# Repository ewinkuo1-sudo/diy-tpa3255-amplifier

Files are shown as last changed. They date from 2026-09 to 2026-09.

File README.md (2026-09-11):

# TPA3255 DIY 立體聲後級

使用 TI TPA3255 自畫電路與 PCB，搭配材料選用、3D 機構與量測，完成一台練習機／備用後級，記錄 AI 協作過程供課堂展示。

## 先看成品怎麼用

**Z10 送出音樂 → 這台後級放大 → 左右喇叭發聲。** 音量由 Z10 調整；後級機內自帶電源，機背只接一條市電電源線，另外可接 Trigger 跟隨前級開機／待機。

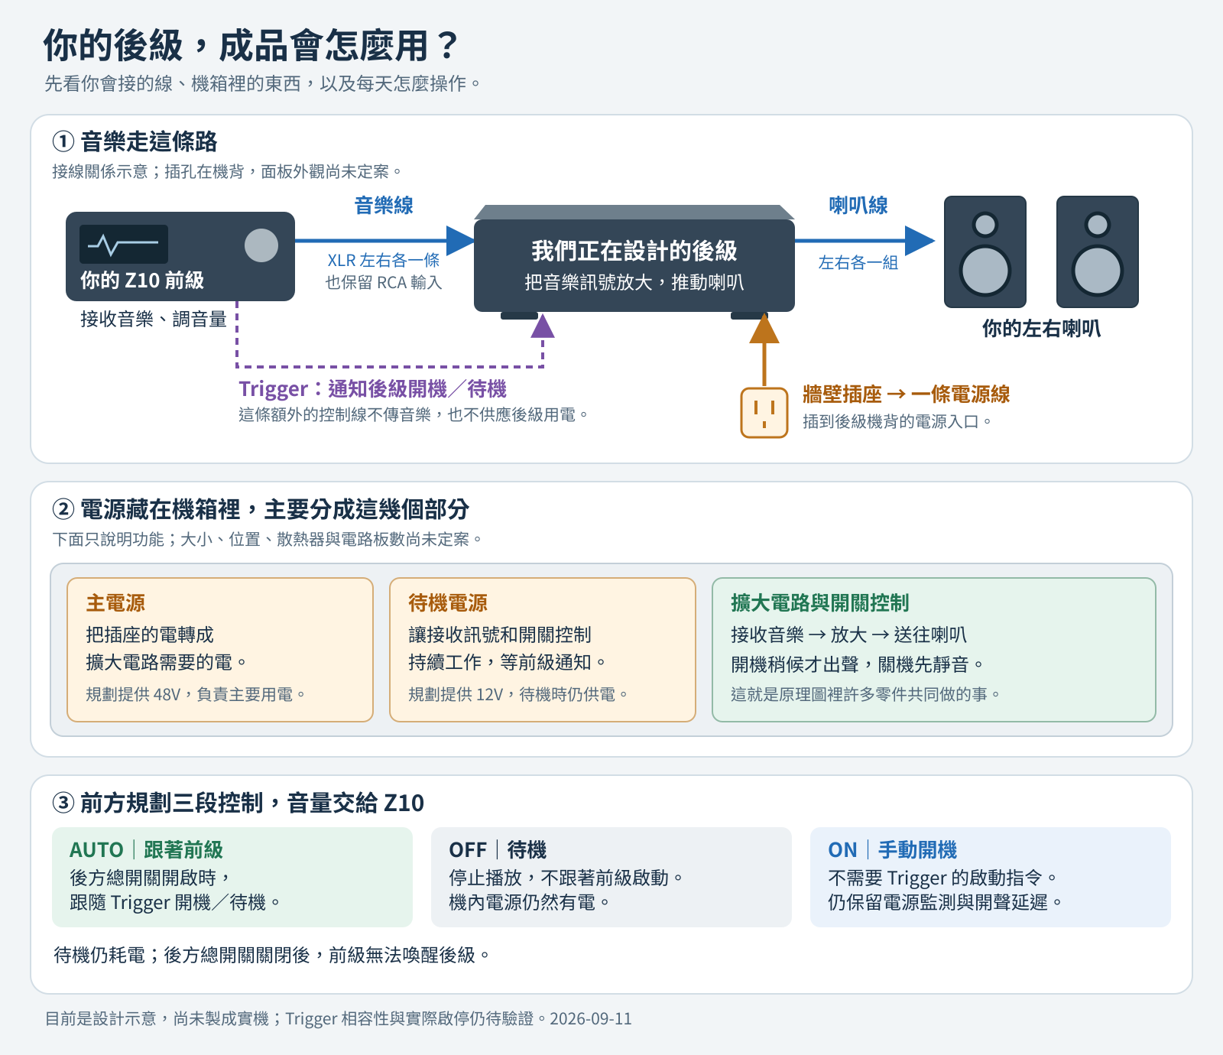
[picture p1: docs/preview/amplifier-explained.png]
後級使用方式圖解


[白話說明與放大圖](docs/使用方式圖解.md)。這是功能與使用方式示意，外觀、內部位置及尺寸尚未定案；目前尚無實機。

## 目前進度

V0.3 已加入 **XLR 平衡輸入並保留 RCA**，搭配濾波後回授（PFFB）、四顆 Coilcraft MA5172-AE，以及隔離 Trigger、自動啟停與 48V 功率電源開關。原八頁的全部元件已按訊號路徑重新排列成 **一張連續接線的完整電路圖**，可由輸入一路看到放大、喇叭、四路回授及啟停控制；元件與電氣連接維持原版。已開始 PCB 零件配置；以 2×50W / 8Ω 為第一階段目標，尚無完成的板子或實測。

XLR 使用 INA2137 差動接收器，依 Z10 的 XLR／RCA 電平匹配音量。第一版由左右聲道跳線選擇輸入，切換前先進入待機。

整機已改為 **機內電源、機背一條市電線**：規劃單一 IEC 入口，機內分別供應 48V 主電源與 12V 待機電源。Trigger 關機只停止功率級供電，兩組 AC/DC 與 12V 支路仍有電。電源模組已有候選，交流保護、12V 入口保護、配線及熱驗證尚待完成；Z10 Trigger 的電壓、極性與帶載能力仍需實測。

## PCB 第一版配置

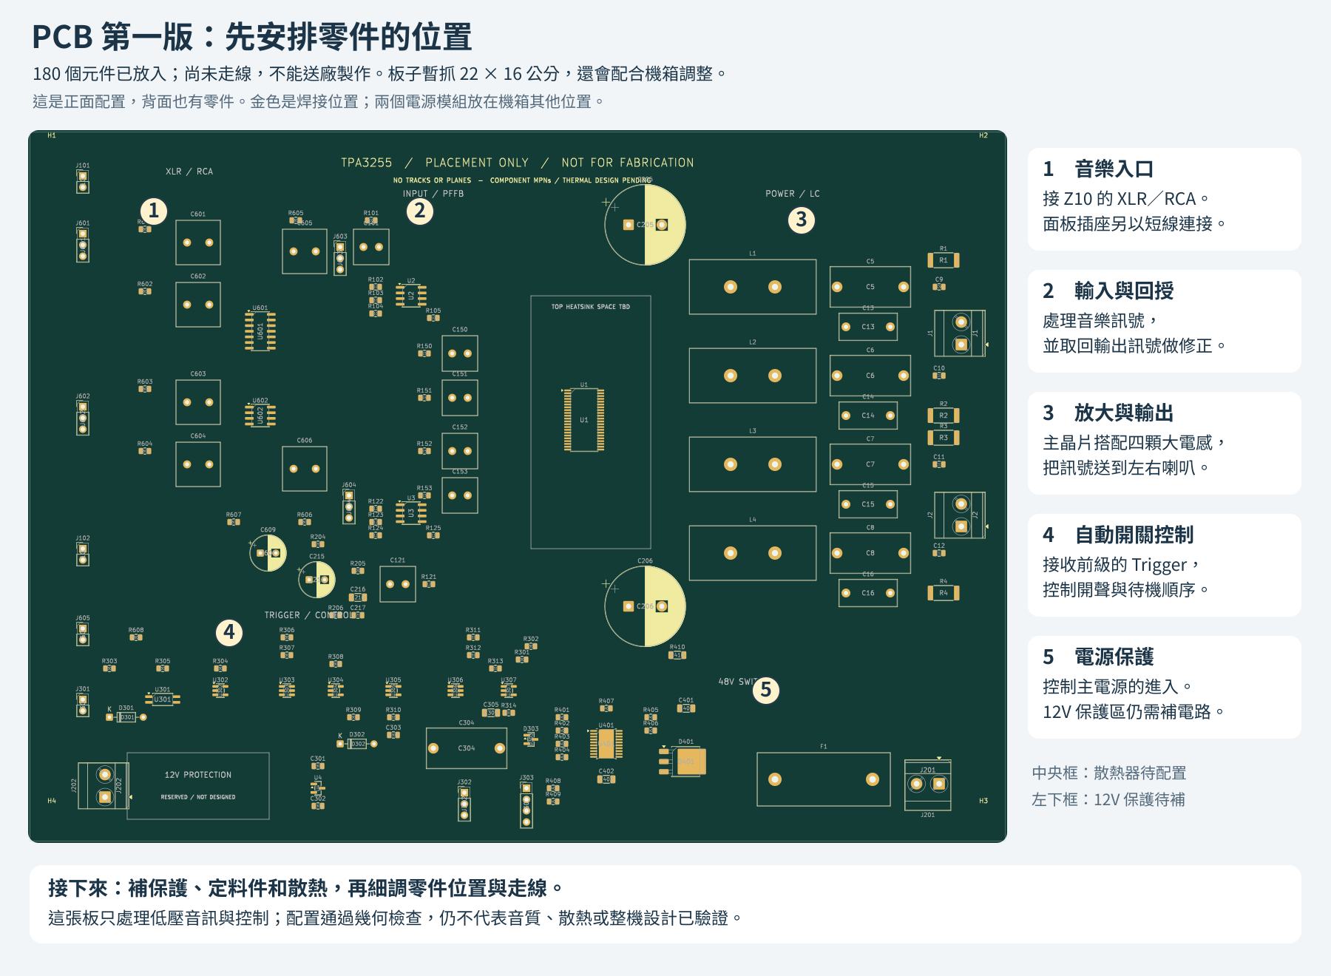
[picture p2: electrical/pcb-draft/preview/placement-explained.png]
PCB 配置中文圖解


**[看 PCB 配置與中文說明](electrical/pcb-draft/README.md)** · [檢查結果](electrical/pcb-draft/validation.md)

已放入 180 個元件與 4 個固定孔，暫抓 22×16 公分，尺寸與料件仍需調整。**尚未走線，不能送廠製作。** 先補電源保護、定料與散熱，再細調位置和走線。

## 電路圖：輸入、放大、回授與控制接成一張大圖

**[開啟／下載單頁 PDF](electrical/v03/preview/tpa3255-v03-overview.pdf)** · [放大 SVG](electrical/v03/preview/tpa3255-v03-overview.svg) · [看圖說明](electrical/v03/README.md) · [合併檢查](electrical/v03/overview-validation.md)

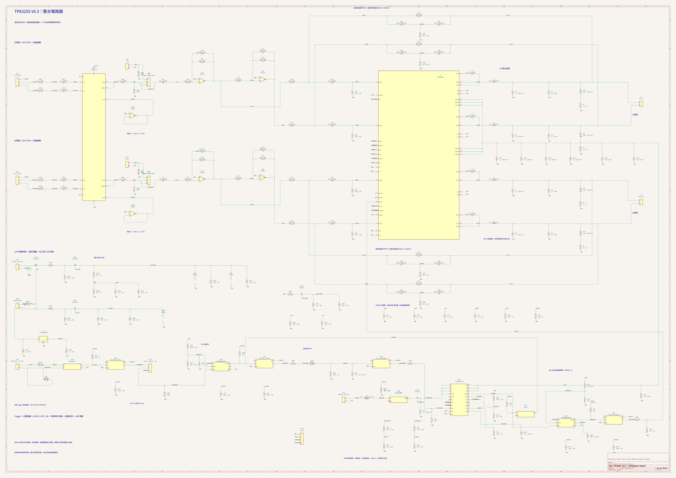
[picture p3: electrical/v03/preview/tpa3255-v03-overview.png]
V0.3 完整單頁電路總圖


總圖採 **A0 橫式單頁**，180 個元件重新編排；音訊由左往右，四路 PFFB 實際接線繞回輸入，下方整合供電與啟停控制。483 個腳位、120 個網路與原版一致，另以移除標籤的接線表確認主要路徑確實連通。PDF／SVG 可放大看數值。建議直接把單頁 PDF 傳給教授，螢幕閱讀時放大；列印以 A0 原尺寸為佳，縮到 A4 文字會太小。供電、偏壓與部分狀態線使用同名標籤相連；導線交叉處有圓點才相接。

[中文設計說明](docs/V0.3_設計說明.md) · [電路／模型驗證報告](electrical/v03/validation.md) · [原八頁 PDF](electrical/v03/preview/tpa3255-v03.pdf)

## 整機電源與機箱

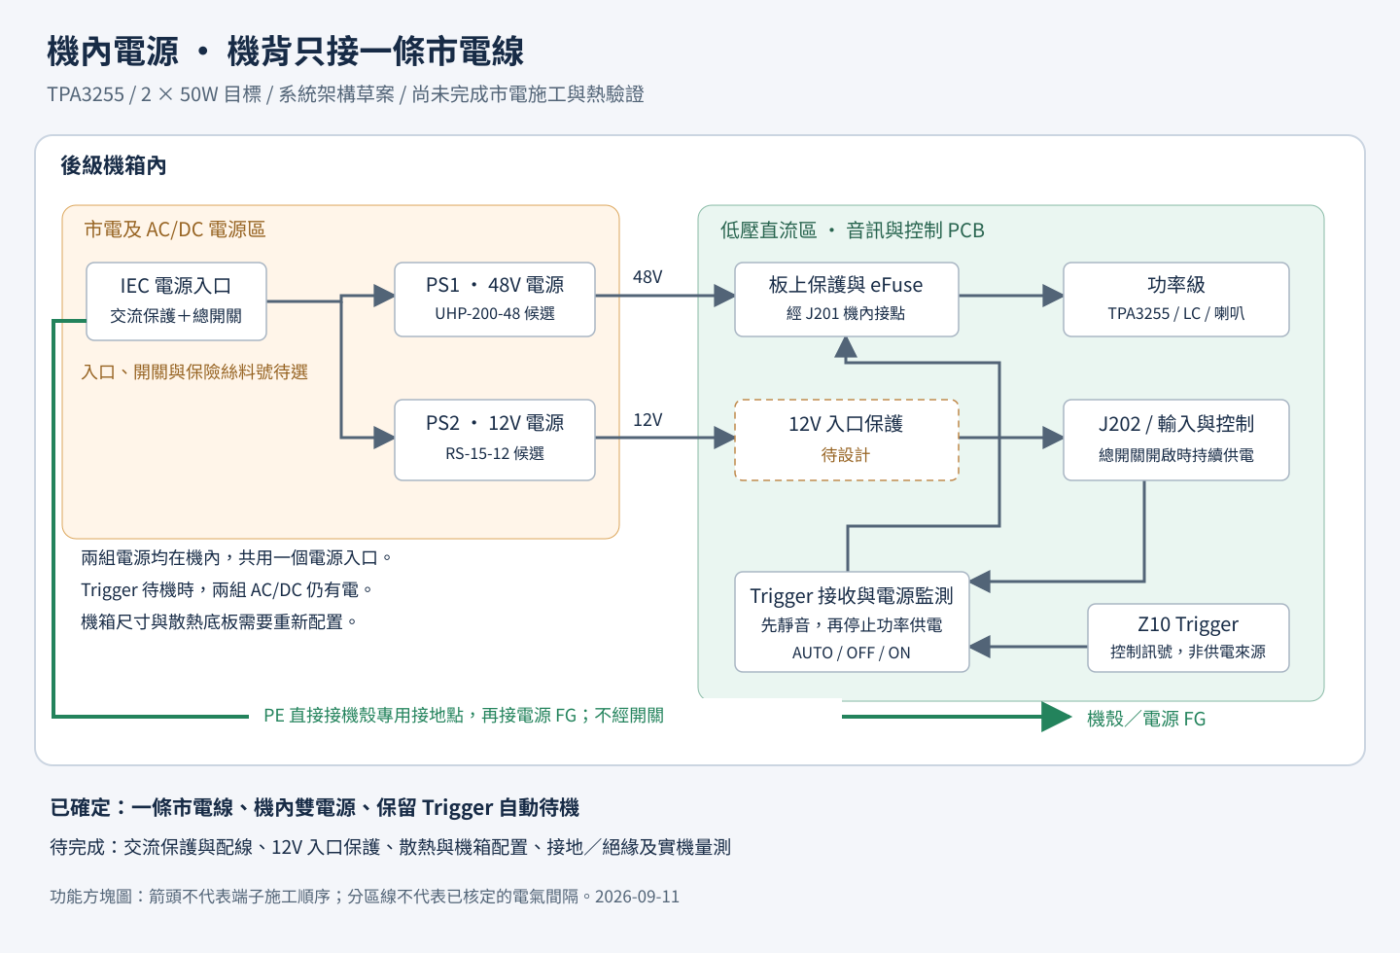
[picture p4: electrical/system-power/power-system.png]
一條市電線的機內電源架構


[電源架構、模組候選與待辦](electrical/system-power/README.md) · [機箱製作方式](mechanical/機箱選擇.md)

採現成鋁機箱＋客製前後面板的方向，需重新容納機內電源、熱路徑與市電配線。機箱尚未定案；[原 V0.1 空間圖](mechanical/README.md) 保留為歷史占位，不代表目前整機尺寸。

## 文件

| 文件 | 用途 |
|---|---|
| [使用方式圖解](docs/使用方式圖解.md) | 先看 Z10、後級、喇叭怎麼連接，以及電源和開關怎麼用 |
| [PCB 配置草案](electrical/pcb-draft/README.md) | 真正 KiCad 板檔、180 元件初步配置、中文預覽與待辦 |
| [機內電源架構](electrical/system-power/README.md) | 單一市電入口、48V／12V 模組候選、保護接地與待機 |
| [V0.3 電路設計](docs/V0.3_設計說明.md) | 電感選型、回授、Z10 匹配與 Trigger 啟停 |
| [PCB 設計要求](docs/V0.3_PCB設計要求.md) | 供電、接地、取樣與元件配置要求 |
| [V0.2 電路設計](docs/V0.2_電路設計.md) | 歷史基線：手動控制、未加 PFFB |
| [音質改善評估](docs/V0.2_音質改善評估.md) | 回授、電感、供電與輸入級的改善優先順序 |
| [BOM 草案](electrical/v03/bom-draft.csv) | V0.3 電路元件；封裝候選另列於 PCB 草案，尚未回填定案 |
| [V0.1 設計規格](docs/V0.1_設計規格.md) | 系統、選材條件與測試流程 |
| [電路設計筆記](docs/01_電路設計.md) | 已修正的腳位、供電與設計注意事項 |
| [功率估算](docs/V0.1_功率估算.md) | 可重算的需求情境 |
| [原始規劃](docs/00_專案總覽.md) | 歷史成本與構想，待重核 |
| [接班進度](HANDOFF.md) | 下一步與驗證程度 |
| [拆分紀錄](MIGRATION.md) | 舊版本與歷史來源 |

## 下一步

補齊 12V 入口保護與交流入口／總開關選型，依機內電源的散熱需求重排機箱。同時完成回授穩定性、真實運放與電源開關的進一步驗證，核對 Trigger 介面、剩餘料件及封裝，再確定 PCB 板形、佈局和散熱器。

重新產生計算報告：

```sh
python3 tools/power_budget.py > docs/V0.1_功率估算.md
```

預覽更新方式見 [看圖說明](mechanical/README.md)。
Purifi 主力機位於 [獨立專案](https://github.com/ewinkuo1-sudo/diy-purifi-amplifier)，本專案的檔案與測試不依賴它。

## License

MIT（沿用來源專案的授權聲明）；衍生自 KiCad 的獨立封裝另依[封裝庫授權](electrical/pcb-draft/Placement.pretty/README.md)。

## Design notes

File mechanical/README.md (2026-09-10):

# 看圖入口

目前按使用者要求採 **機內電源、機背一條市電線**，見[整機電源架構圖](../electrical/system-power/README.md)。機箱建議採現成鋁殼＋客製前後板，已整理[製作方式與尺寸參考](機箱選擇.md)。型號與尺寸需重新配置；以下 V0.1 圖僅為外接電源時期的歷史占位，未包含現在的機內 AC/DC、XLR、實際電感及固定方式。

## 機殼草案

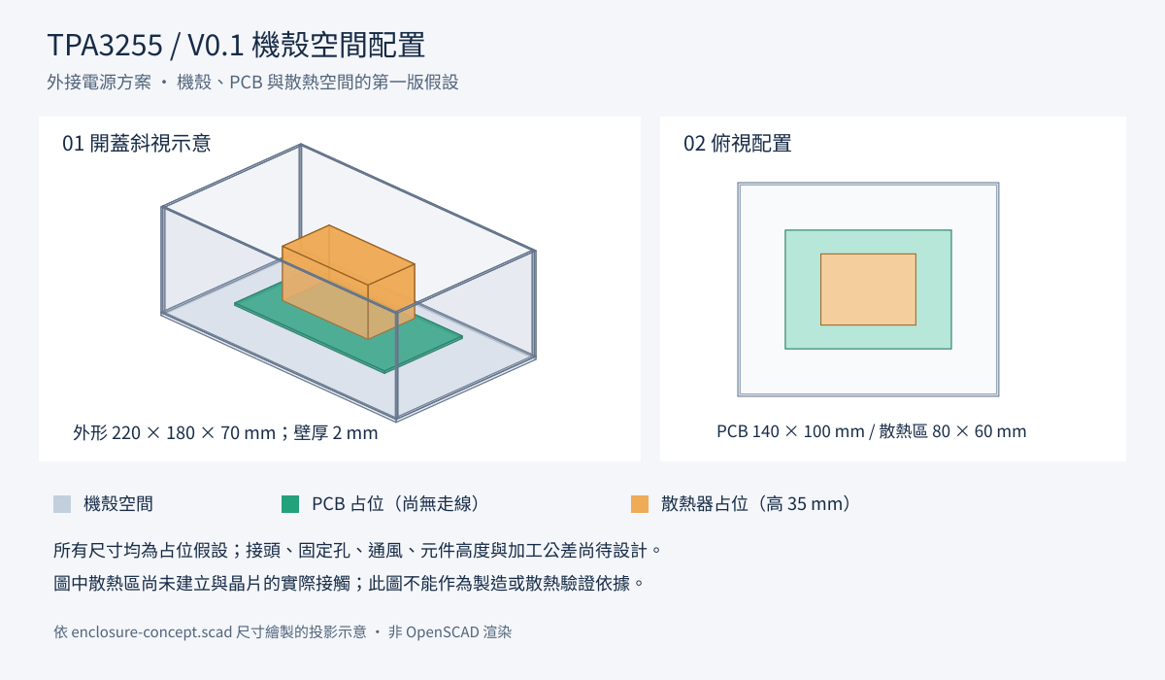
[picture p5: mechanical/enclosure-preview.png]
TPA3255 V0.1 機殼空間配置


左側是開蓋斜視，右側是俯視。綠色是 PCB 占位，橘色是散熱器占位，灰色是機殼。這是空間配置草案；板上尚無元件與走線，尺寸仍可改。

- [放大看 PNG](enclosure-preview.png)
- [向量圖 SVG](enclosure-preview.svg)
- [可修改尺寸的 OpenSCAD 原始檔](enclosure-concept.scad)
- [系統方塊圖與設計規格](../docs/V0.1_設計規格.md#系統方塊圖)

GitHub 的文件與 PNG 可直接閱讀。若要旋轉並修改機殼模型，下載 `.scad`，用 [OpenSCAD](https://openscad.org/) 開啟並按 F5 預覽。本機目前尚未安裝 OpenSCAD；上述圖片是讀取模型尺寸繪製的投影示意，不是 CAD 軟體渲染。

## 更新預覽

在專案根目錄執行：

```sh
python3 tools/enclosure_preview.py
rsvg-convert -o mechanical/enclosure-preview.png mechanical/enclosure-preview.svg
```

Python 腳本不需要額外套件；PNG 轉換使用 librsvg 的 `rsvg-convert`。腳本讀取 SCAD 中的數值尺寸，投影邏輯對應目前的矩形空間配置。若更改 SCAD 的幾何形狀，需同步更新腳本。預覽固定隱藏上蓋，尚未輸出可旋轉的 STL。

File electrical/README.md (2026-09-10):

# TPA3255 原理圖：直接看圖

最新設計已移至 **[V0.3 八頁原理圖：XLR／RCA 與 Trigger](v03/README.md)**。以下保留 V0.2 歷史基線。

這裡是 V0.2 可編輯的 KiCad 電路草案，已通過 ERC 與接線群組核對，尚無 PCB 或實測。四頁屬於同一電路，全域網路名稱相同即相連。

**[下載四頁 PDF](preview/tpa3255-v02.pdf)** · [中文設計說明](../docs/V0.2_電路設計.md) · [驗證結果](validation.md) · [BOM 草案](bom-draft.csv)

## 1. 功率級與輸出濾波

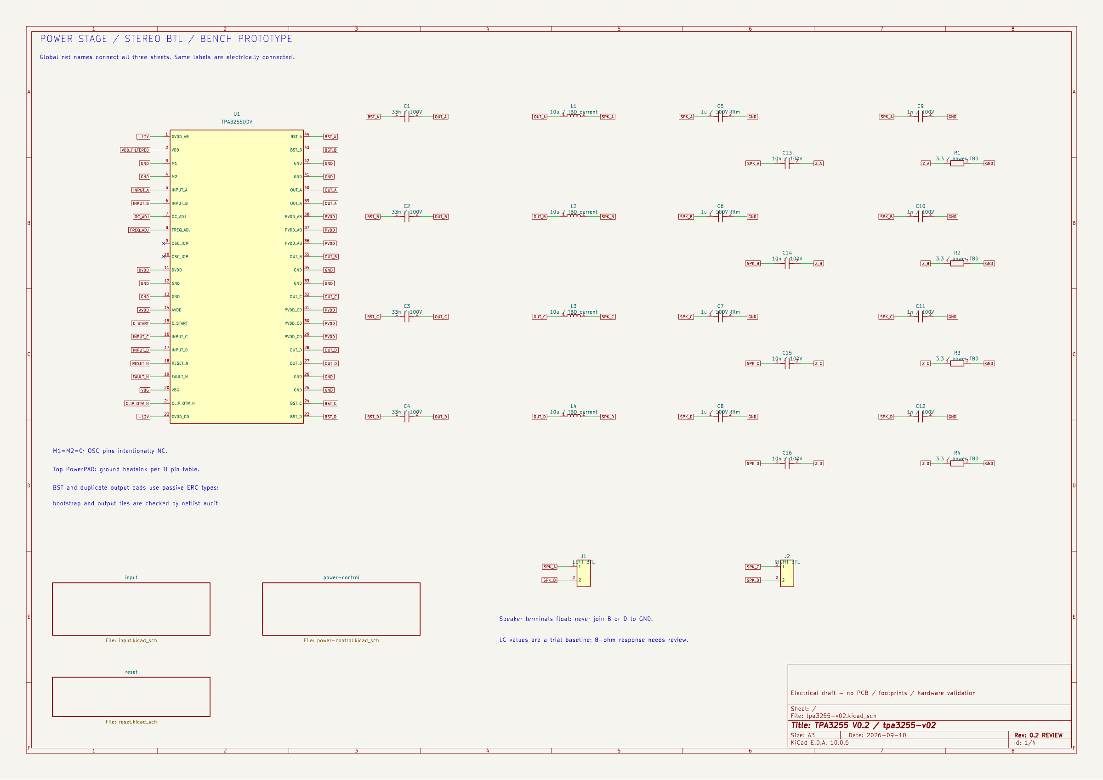
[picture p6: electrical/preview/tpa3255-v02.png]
TPA3255 功率級


[放大 SVG](preview/tpa3255-v02.svg)

## 2. RCA 輸入級

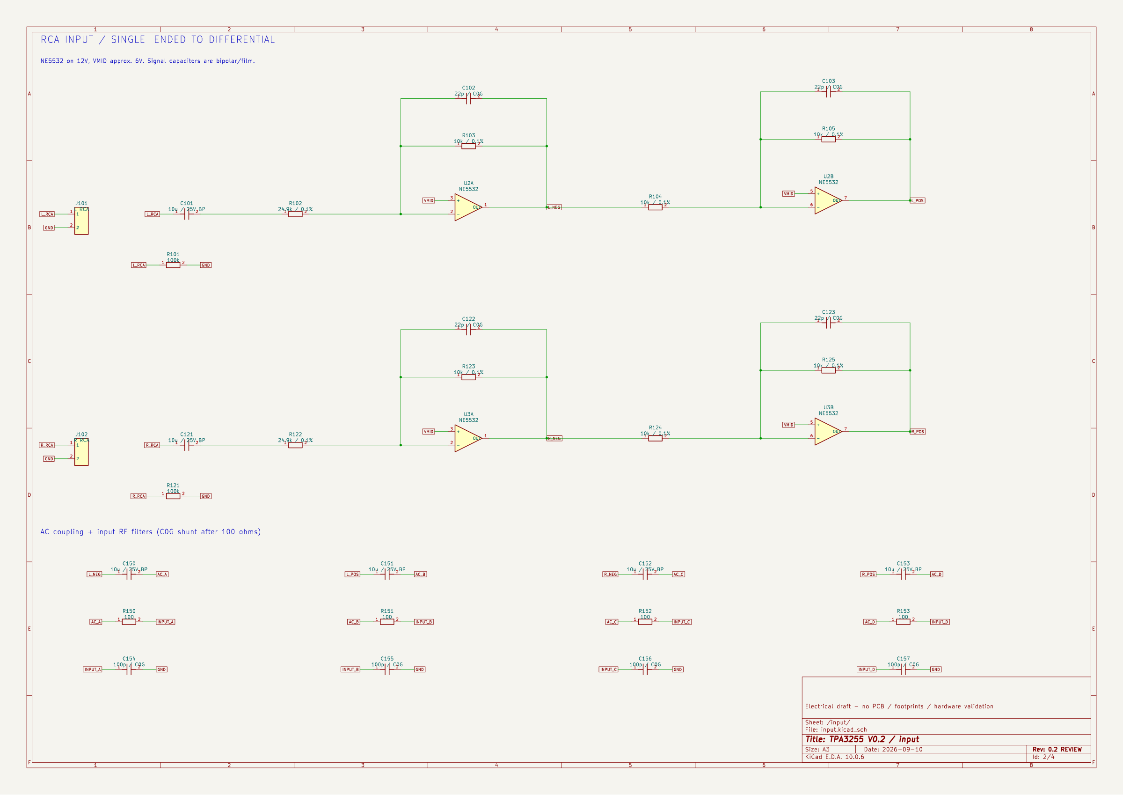
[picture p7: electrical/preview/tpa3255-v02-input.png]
RCA 輸入與差動轉換


[放大 SVG](preview/tpa3255-v02-input.svg)

## 3. 供電與去耦

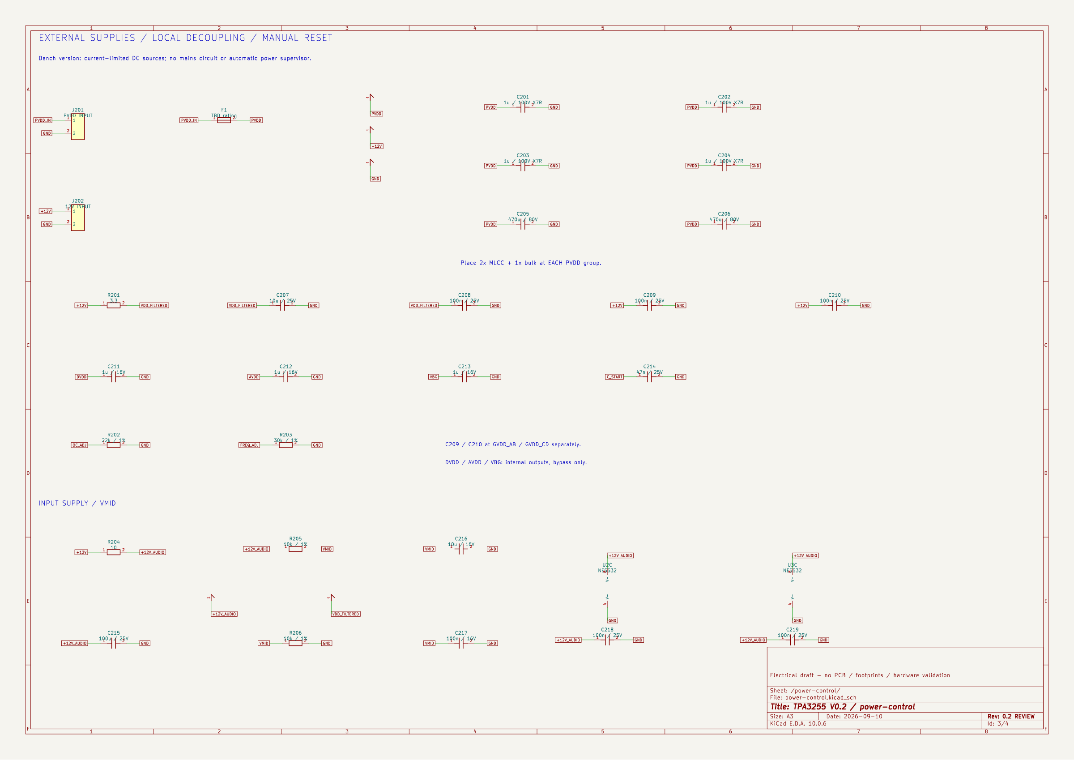
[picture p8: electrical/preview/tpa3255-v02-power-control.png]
主電源、12V 與局部去耦


[放大 SVG](preview/tpa3255-v02-power-control.svg)

## 4. 手動啟停控制

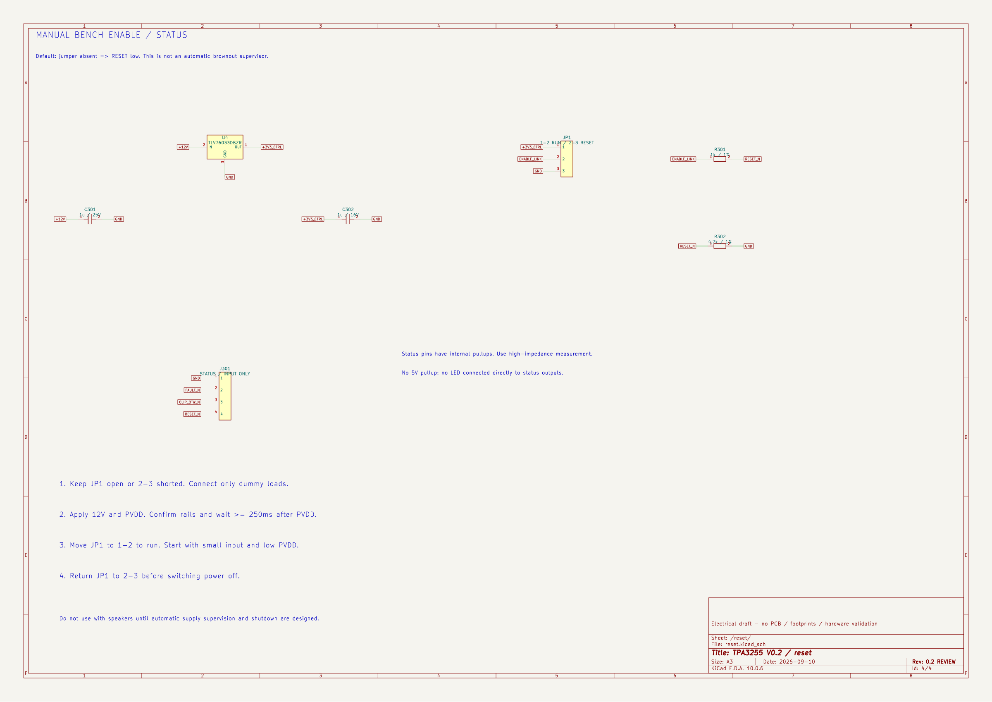
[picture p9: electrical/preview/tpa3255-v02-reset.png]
手動 RESET 與故障量測


[放大 SVG](preview/tpa3255-v02-reset.svg)

## 編輯與重現

用 KiCad 10 開啟 [tpa3255-v02.kicad_pro](tpa3255-v02.kicad_pro)，再開啟同名原理圖。`Project.kicad_sym` 與 `sym-lib-table` 已隨專案附上，不依賴另行下載的自訂符號。

檢查與輸出（在專案根目錄）：

```sh
python3 tools/verify_electrical.py
python3 tools/export_schematic.py
```

`verify_electrical.py` 讀取目前的原理圖，用 KiCad 匯出接線表，核對 `expected-connections.csv` 並產生 ngspice 輸入／LC 區塊模型、CSV 數據與報告。更改電路時需審查並更新預期接線表；不要為了通過檢查而直接接受未知連接。

`tools/build_schematic.py` 是本次初始圖面的產生器，重跑會覆寫四頁原理圖、自訂符號、預期接線表與專案檔。若已在 KiCad 手動編輯，平時使用上面的驗證／匯出指令即可。

`export_schematic.py` 使用 `kicad-cli` 匯出四頁 PDF／SVG，整理 SVG 行尾空白，再用 `rsvg-convert` 產生寬 2400 像素的 PNG。需安裝 KiCad 與提供 `rsvg-convert` 的 librsvg；圖面更新時執行一次即可同步首頁預覽。

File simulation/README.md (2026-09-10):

# V0.2 區塊模擬

由 `python3 tools/verify_electrical.py` 從 KiCad 匯出接線表產生，使用 ngspice 47。

| 檔案 | 範圍 | CSV first / second |
|---|---|---|
| `input-ac.cir` / `input-ac.csv` | 左右輸入級 AC，理想有限增益運放 | 左聲道 / 右聲道的晶片輸入差動電壓 |
| `filter-ac.cir` / `filter-ac.csv` | 左聲道 BTL 輸出濾波，4Ω 和 8Ω 比較 | 4Ω / 8Ω 的差動電壓 |

CSV 頻率單位 Hz，電壓是相對 1V AC 激勵的複數結果。數值不是 THD、噪音、熱或實機性能。模型與假設見 [設計說明](../docs/V0.2_電路設計.md)，摘要見 [驗證報告](../electrical/validation.md)。

在本目錄可用 `ngspice -b input-ac.cir` 或 `ngspice -b filter-ac.cir` 重跑，生成 `.dat`。正式 CSV 與驗證報告由根目錄的驗證腳本統一更新。

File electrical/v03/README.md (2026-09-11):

# V0.3 電路圖：完整單頁整合電路

原八頁的所有元件已重新編排成 **一張 A0 橫式、連續接線的完整電路圖**，包含 XLR 平衡接收／RCA 選擇、PFFB、四顆 MA5172-AE，以及隔離 Trigger 控制與 48V 功率電源開關。180 個元件、483 個腳位、120 個網路與原版完全一致；音訊、四路回授與主要啟停控制以實際導線連接；電路功能未改。電路已有接線檢查及簡化模型驗證，亦有[未走線 PCB 配置草案](../pcb-draft/README.md)，尚無實機性能驗證。

整機採[機內電源、單一市電入口](../system-power/README.md)。總圖完整涵蓋原八頁的低壓音訊與控制；J201／J202 為機內供電接點，市電區另行規劃，沒有包含在本版 ERC／模型驗證內。

**[開啟／下載單頁 PDF](preview/tpa3255-v03-overview.pdf)** · [放大 SVG](preview/tpa3255-v03-overview.svg) · [高解析 PNG](preview/tpa3255-v03-overview.png) · [單頁 KiCad 圖檔](tpa3255-v03-overview.kicad_sch) · [合併檢查](overview-validation.md)

完整單頁電路總圖

建議將單頁 PDF 傳給教授，放大看元件數值；列印以 A0 原尺寸為佳，縮到 A4 文字會太小。PDF／SVG 是可放大的向量圖；PNG 供快速預覽。供電、偏壓與部分狀態線仍以同名標籤表示相連；導線交叉有圓點才相接。

總圖閱讀順序：

1. 左側 XLR／RCA 輸入與選擇 → NE5532 差動驅動 → 中央 TPA3255 → 右側 LC 與喇叭。
2. 喇叭端的四路 PFFB 從功率級上下方繞回 SUM 加總點；回授阻容直接畫在回線上。
3. 左下方為 12V 待機、類比供電與 VMID；功率級 PVDD 去耦接在右側供電幹線。
4. 下方 Trigger 經隔離、模式選擇、電源監測與關機保持，控制 48V eFuse；延遲開聲線直接接回 TPA3255 的 RESET。

原八頁的方格分區已移除。U1／U601 的圖形腳位改按訊號流排列，實體腳號、名稱與電氣型態均保留；一個 IC 仍是一個 IC。

[中文設計說明](../../docs/V0.3_設計說明.md) · [電路／模型驗證](validation.md) · [BOM 草案](bom-draft.csv)

<details>
<summary>展開原八頁分區圖（維護與逐區查閱）</summary>

[下載原八頁 PDF](preview/tpa3255-v03.pdf)。以下為原版頁次；整合總圖已依訊號路徑重新安排。

## 1. 功率級與輸出電感

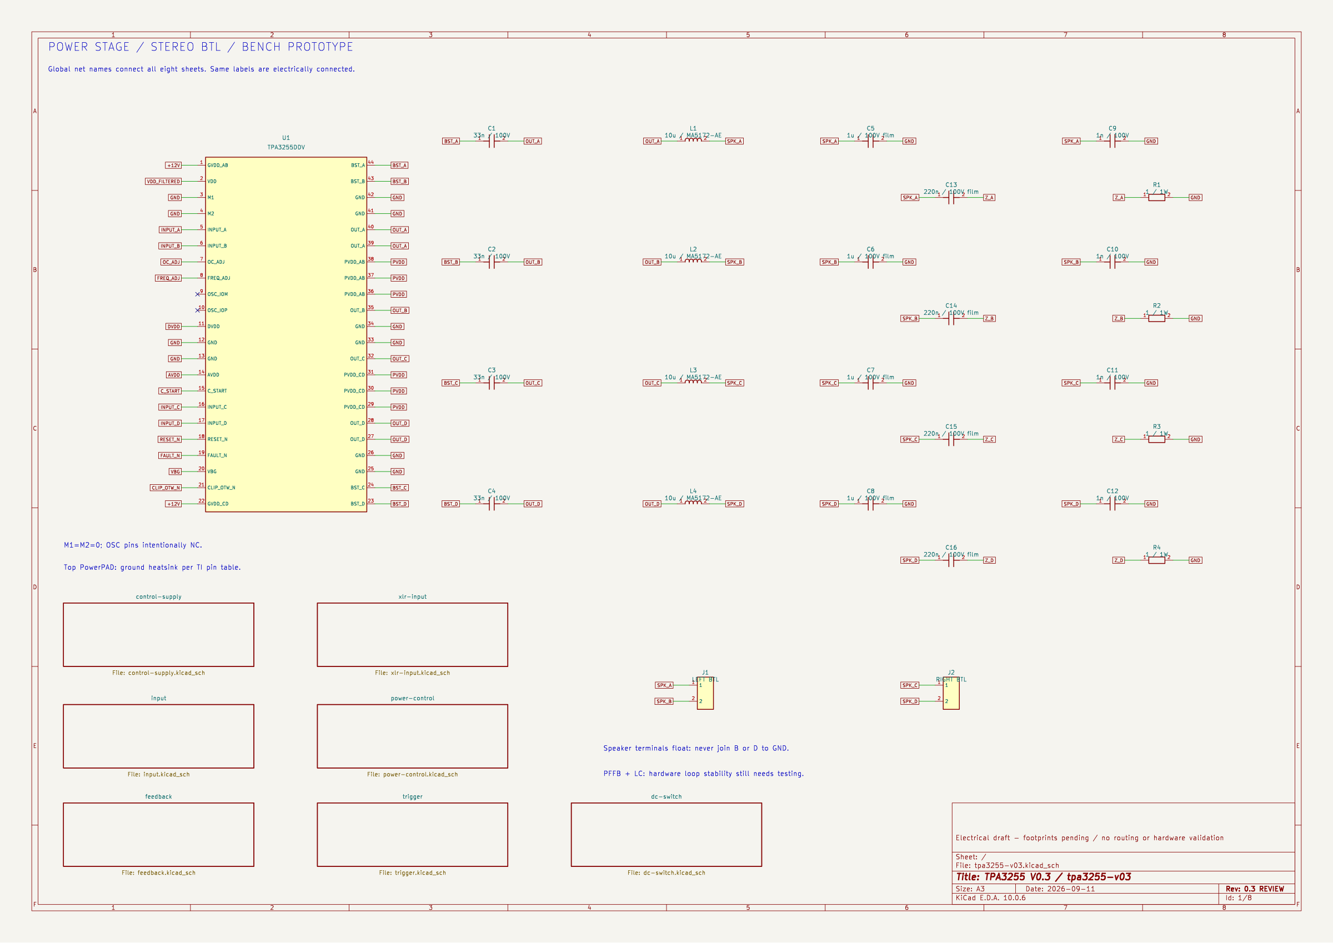
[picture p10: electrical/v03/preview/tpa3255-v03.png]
功率級


[放大 SVG](preview/tpa3255-v03.svg)

## 2. RCA 插座與選定訊號的差動驅動級

RCA 或 XLR 訊號由第八頁 J603／J604 選擇後，送入本頁的 C101／C121。

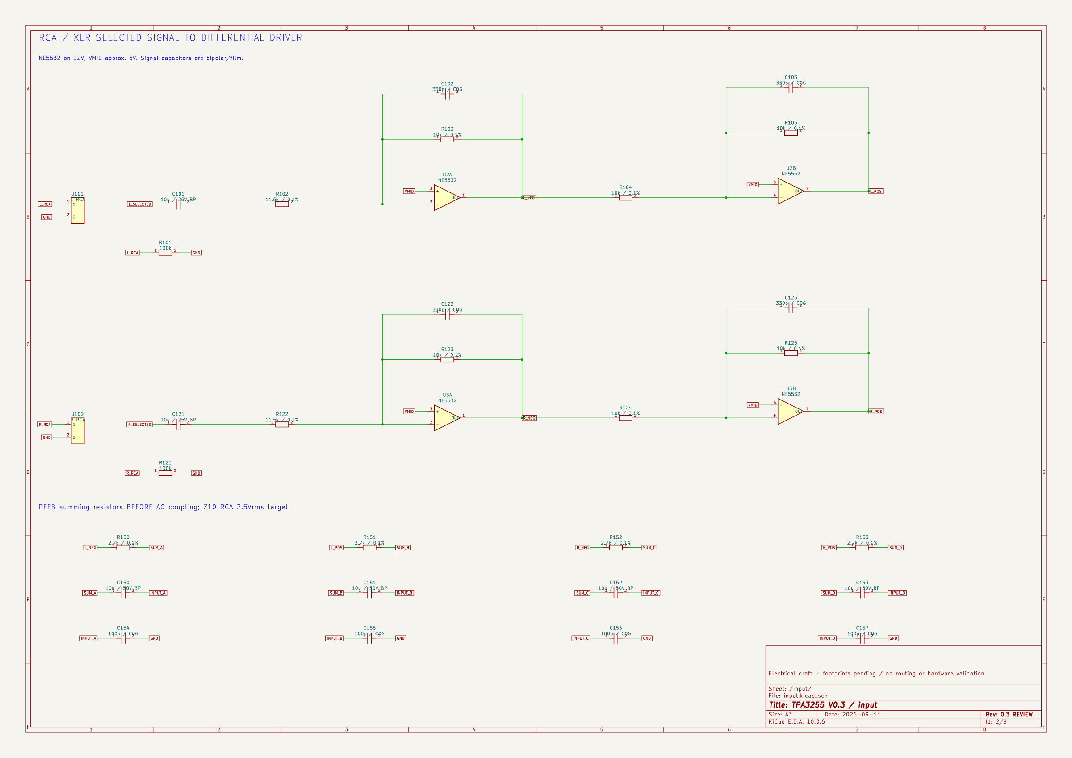
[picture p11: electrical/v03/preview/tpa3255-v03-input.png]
輸入級


[放大 SVG](preview/tpa3255-v03-input.svg)

## 3. 供電去耦

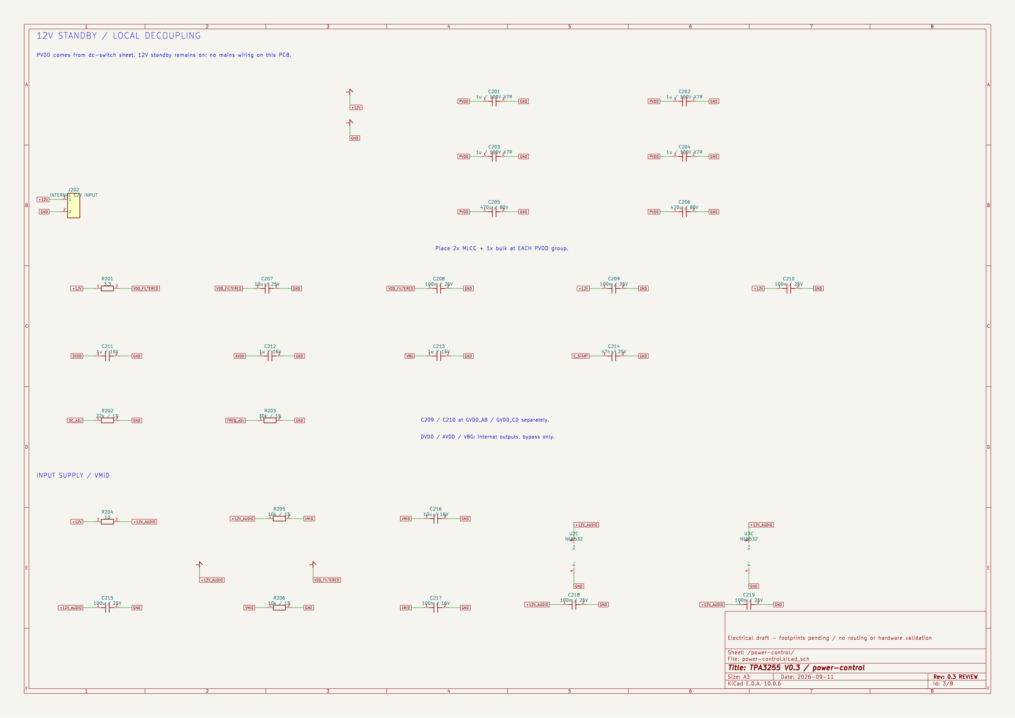
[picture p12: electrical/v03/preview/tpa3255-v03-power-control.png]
供電去耦


[放大 SVG](preview/tpa3255-v03-power-control.svg)

## 4. 濾波後回授 PFFB

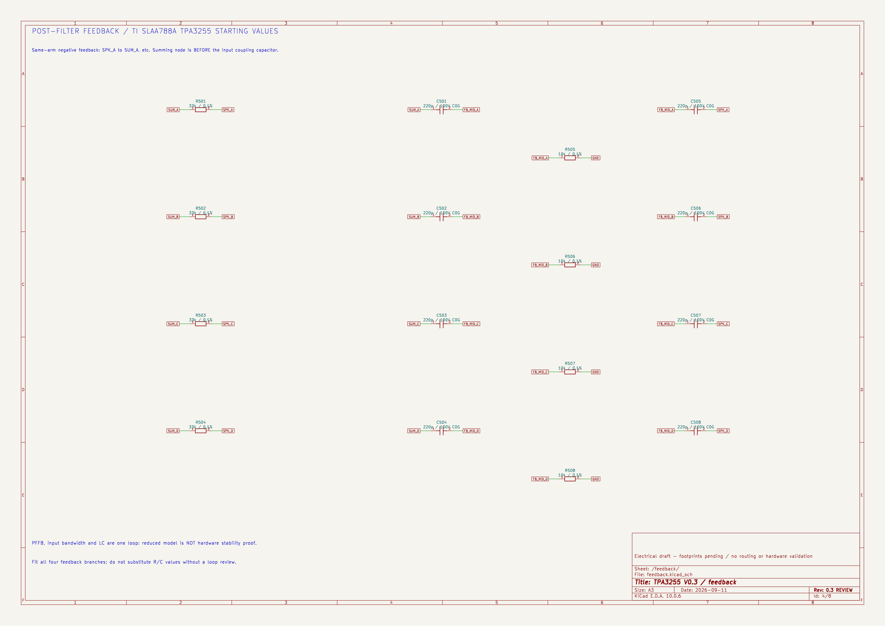
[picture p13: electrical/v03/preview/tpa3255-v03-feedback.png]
PFFB


[放大 SVG](preview/tpa3255-v03-feedback.svg)

## 5. Trigger 接收與關機延遲

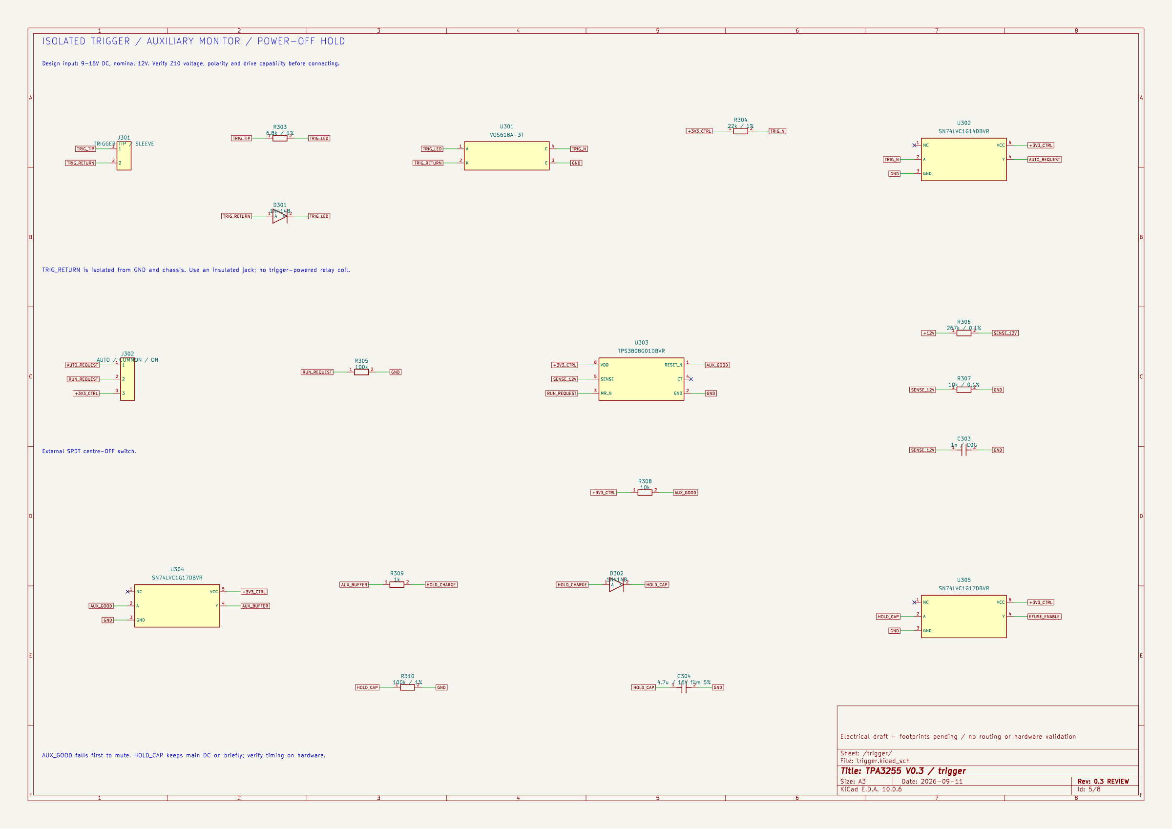
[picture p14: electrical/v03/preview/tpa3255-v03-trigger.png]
Trigger


[放大 SVG](preview/tpa3255-v03-trigger.svg)

## 6. 48V 功率電源開關與延遲開聲

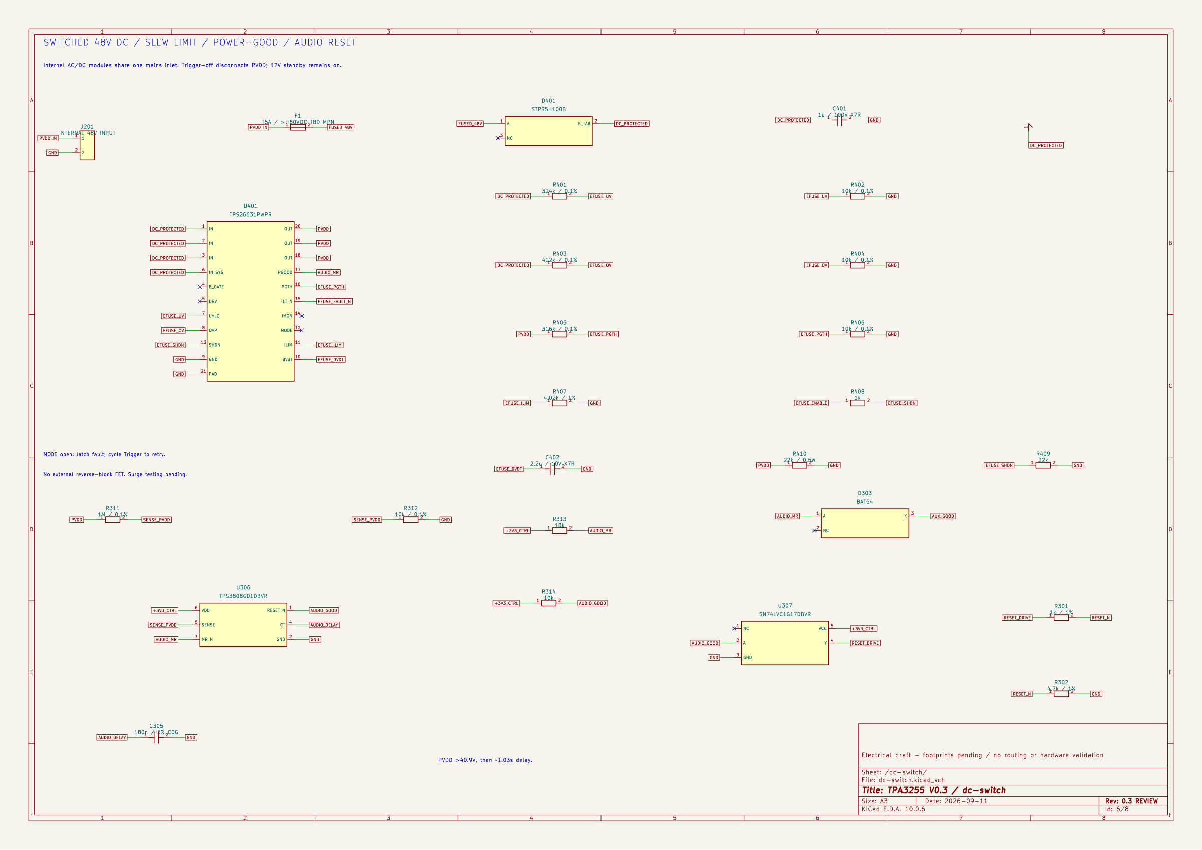
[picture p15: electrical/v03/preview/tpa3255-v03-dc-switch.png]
功率電源開關


[放大 SVG](preview/tpa3255-v03-dc-switch.svg)

## 7. 待機控制供電

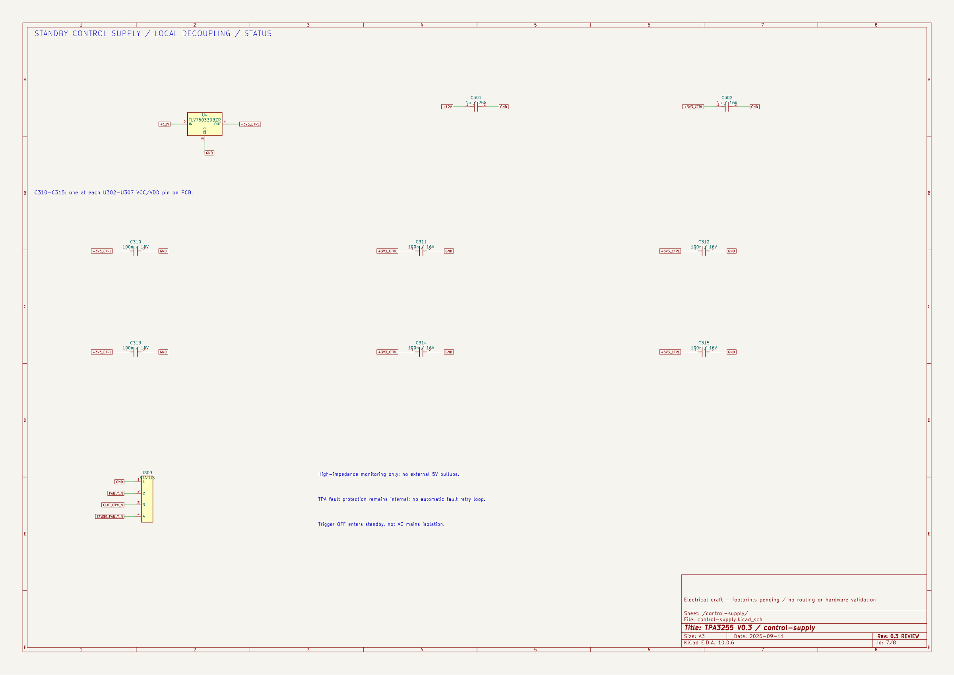
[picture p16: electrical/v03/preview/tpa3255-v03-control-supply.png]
待機控制供電


[放大 SVG](preview/tpa3255-v03-control-supply.svg)

## 8. XLR 平衡接收與輸入選擇

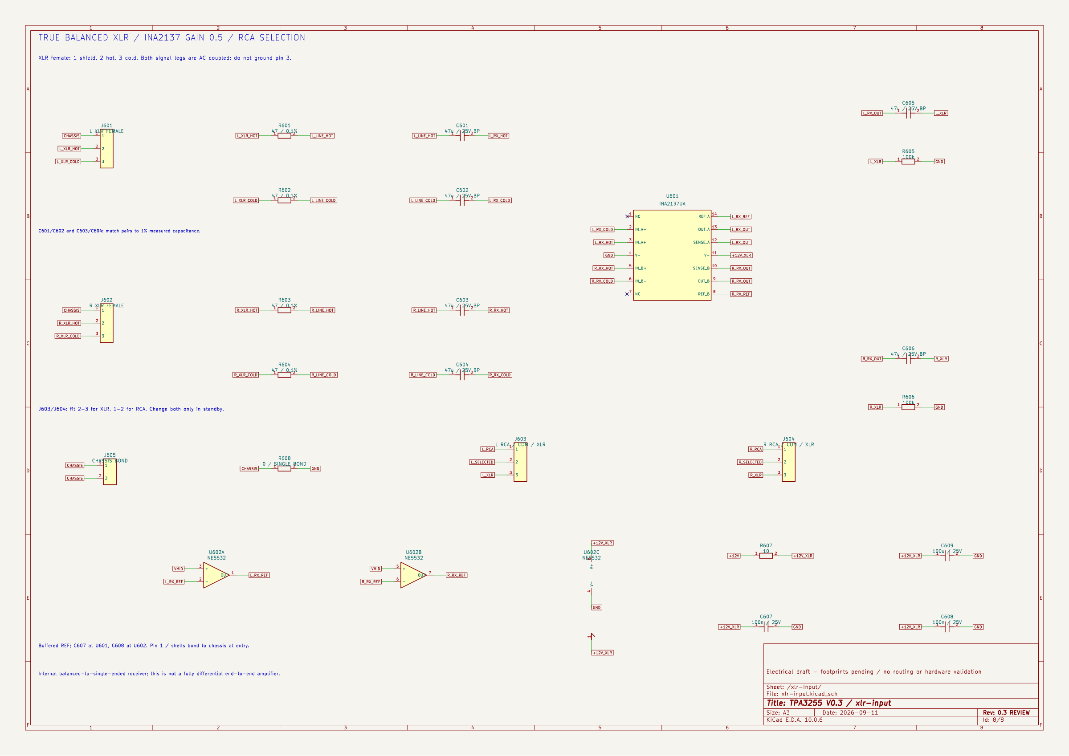
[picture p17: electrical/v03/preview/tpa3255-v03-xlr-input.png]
XLR 平衡輸入


[放大 SVG](preview/tpa3255-v03-xlr-input.svg)

左右聲道各一個 XLR 母座。J603／J604 均接 2–3 選 XLR，均接 1–2 選 RCA；切換前先將 J302 設為 OFF 待機。這版是板上跳線設定，機殼面板切換方式尚待機構與靜音設計。

</details>

## 原始檔、編輯與驗證

單頁總圖可用 KiCad 10 開啟 [tpa3255-v03-overview.kicad_pro](tpa3255-v03-overview.kicad_pro)，它是包含全部元件的原生單頁圖檔。由現行八頁來源讀取全部元件，再重新配置位置與實際導線；保留元件、數值、單元及符號 UUID。`Overview.kicad_sym` 保存 U1／U601 的功能排列圖形，其餘符號沿用 Project 庫。

維護時仍以八頁來源為準，再重建總圖。既有 PCB 對應原階層路徑，請繼續從原專案更新 PCB；總圖若另行編輯，不會自動回寫來源，重建也會覆寫總圖。`overview-sources.json` 記錄 SHA-256，驗證可偵測來源變動而總圖尚未更新。

只更新總圖時執行（不需重跑電路模型）：

```sh
python3 tools/build_schematic_overview.py
python3 tools/verify_schematic_overview.py
python3 tools/export_schematic.py electrical/v03/tpa3255-v03-overview.kicad_sch --pdf-from-svg --png-width 4800
```

驗證會比對元件、每個符號的電氣腳位、全部接線與 ERC，再暫時移除標籤，檢查音訊、回授及主要控制路徑仍靠導線完整連接。PDF 由 KiCad SVG 轉為靜態向量圖，保留 A0 尺寸、中文與細節。

KiCad 10 開啟 [tpa3255-v03.kicad_pro](tpa3255-v03.kicad_pro)，再開同名原理圖；自訂符號庫已隨附。電感料號已選，其餘 BOM 仍有待定項，全部 footprint 尚未定案。

在儲存庫根目錄執行：

```sh
python3 tools/verify_v03.py
python3 tools/export_schematic.py electrical/v03/tpa3255-v03.kicad_sch
```

`verify_v03.py` 檢查實際 KiCad 接線表，更新 BOM、AC 數據與控制時序規格模型。後者不是實際控制 IC 的 SPICE 模型，也沒有驗證真正的回授穩定裕度。

`tools/build_schematic_v03.py` 只供重建這版初始圖面，會覆寫本資料夾的原理圖、符號庫、預期接線表與專案檔。手動編輯後使用上述驗證與匯出指令，避免直接重建。V0.2 仍保留在[上層歷史圖面](../README.md)。

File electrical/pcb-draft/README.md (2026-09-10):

# PCB 第一版：零件配置草案

已開始畫真正的 KiCad 電路板檔案。本階段先安排零件位置和空間，**尚未走線，不能送廠製作**。板子暫抓 220×160 mm，機箱與散熱器仍需配合調整。

PCB 配置中文圖解

[放大中文圖解](preview/placement-explained.svg) · [正面原始預覽](preview/top.png) · [背面原始預覽](preview/bottom.png) · [檢查結果](validation.md)

## 目前這張板包含什麼

- 180 個電路元件與 4 個暫定 M3 固定孔，保留原理圖接線資料。
- 左側接前級；中間放輸入處理、回授與功率晶片；右側安排四顆電感與喇叭輸出；下方安排 Trigger 與主電源開關。
- 主晶片頂部的散熱器、12V 入口保護各有空間標記。標記是配置預留，不代表完成 3D 干涉檢查或電氣隔離設計。
- 暫用 4 層、1.6 mm 板厚做空間研究；尚未核定製程、銅厚、介質、線寬、過孔或地平面，沒有畫任何銅箔走線／覆銅。
- 只包括音訊與低壓控制。兩個 AC/DC 電源、交流入口與市電線束放在機箱其他位置，不在這張板上。

分區和現有間距只是起點。高電流回路、去耦過孔、回授取樣、背面元件可裝配性及散熱器固定仍要細調；目前不能以「放得下」判定可用於實際功率輸出。

## 封裝核對與尚未定料的項目

[placement.csv](placement.csv) 每個元件一列，記錄初始封裝、正／背面、位置和來源封裝檔 SHA-256；它是生成結果，手動修改板檔後需同步更新。`package_candidate` 表示已依下列原廠資料核對封裝類型及腳序，但未完成製造放行；`provisional` 表示暫用的尺寸／封裝占位，未選定相應實際料號。

| 部分 | 本次處理與依據 |
|---|---|
| TPA3255 | 使用 DDV 44 腳頂面散熱封裝；PCB 沒有額外的第 45 腳底部散熱焊盤。依 [TI 原廠資料，封裝及 §12](https://www.ti.com/lit/ds/symlink/tpa3255.pdf)。散熱器尺寸與接觸壓力未定。 |
| 主電源開關 | TPS26631 使用 PWP0020T 對應的 HTSSOP-20 與 2.96×2.96 mm 阻焊開口版本，底部第 21 腳接 GND；散熱銅面／過孔仍未設計。[TI TPS2663](https://www.ti.com/lit/ds/symlink/tps2663.pdf) |
| XLR 接收與運放 | INA2137UA 用 SOIC-14；NE5532 暫選 SOIC-8（D 封裝方向，完整訂購料號待定）。[INA2137](https://www.ti.com/lit/ds/symlink/ina137.pdf)、[NE5532](https://www.ti.com/lit/ds/symlink/ne5532.pdf) |
| 監測／邏輯／穩壓 | TPS3808 DBV 用 6 腳 SOT-23；LVC1G14／17 DBV 用 5 腳 SOT-23；TLV760 DBZ 為 3 腳且 1=OUT、2=IN、3=GND。[TPS3808](https://www.ti.com/lit/ds/symlink/tps3808.pdf)、[LVC1G14](https://www.ti.com/lit/ds/symlink/sn74lvc1g14.pdf)、[LVC1G17](https://www.ti.com/lit/ds/symlink/sn74lvc1g17.pdf)、[TLV760](https://www.ti.com/lit/ds/symlink/tlv760.pdf) |
| Trigger 光耦 | VOS618A 用 SSOP-4，依 [Vishay 外形與腳序](https://www.vishay.com/docs/83465/vos618a.pdf)。隔離兩側仍須在走線時保持分開。 |
| 二極體 | D303 的 BAT54 由邏輯兩腳符號改成實體 1=A、2=NC、3=K，陰極接 AUX_GOOD，功能方向不變。[Nexperia BAT54](https://assets.nexperia.com/documents/data-sheet/BAT54.pdf)。D401 採 DPAK，1=A、2=K／散熱片、3=NC，[ST 資料](https://www.st.com/resource/en/datasheet/stps5h100.pdf)。D301／D302 的軸向封裝另依本專案 A=1、K=2 重新編號，陰極帶位置不變。 |
| 電感 | 自訂 MA5172-AE 占位採原廠 28.6×12.3 mm 包絡與名義 10 mm 腳距。**1.4 mm 成品孔、3 mm 焊盤是本次暫定值**，不是原廠建議；腳距 ±0.5 mm、線徑最大 1.07 mm 仍須配合孔公差、裝配及電流核定。[Coilcraft 外形圖](https://www.coilcraft.com/getmedia/5fb1a3ea-b3b6-4ae7-89c3-2a4c68c350e4/ma5172.pdf) |
| 電阻／電容／保險絲 | 封裝僅估空間。0805、1206 或 2512 尺寸不能保證耐壓、功率、電容偏壓特性或誤差；所有實際料號需補齊。無極性電容用無正負標記的專用占位；F1 與座尚未定料，圖中外形／孔距不對應已核定的產品。 |
| 插座與線束 | XLR、RCA、Trigger 和面板控制暫以板端排針占位，**不是面板插座的實際腳位／孔位**；尚需選有防呆／固定的接頭並製作線束對照。主電源與喇叭端子也只選封裝候選，額定與料號未核定。 |

## 開啟與修改

KiCad 10 開啟 [tpa3255-placement.kicad_pro](tpa3255-placement.kicad_pro)，再開同名 PCB；也可直接開 [板檔](tpa3255-placement.kicad_pcb)。原理圖維持在 [V0.3](../v03/README.md)。

本階段封裝候選由 `placement.csv`／生成器管理，**尚未回填原理圖的 Footprint 欄位**，避免把占位當成定案。正式轉入原理圖與 PCB 同步流程時，先定料、回填封裝、核對多單元符號對應，再審查「由原理圖更新 PCB」的差異。不能直接重新生成後覆蓋人工佈局。

```sh
python3 tools/verify_pcb_draft.py
python3 tools/export_pcb_draft.py
```

`tools/build_pcb_draft.py` 由最新原理圖產生初始配置，預設拒絕覆寫已有板檔；`--force` 會丟棄人工 PCB 修改。這不是佈線工具。背面預覽從背面看，左右相對正面翻轉。

PCB 草案完成後的下一步：先補 12V 保護並核定料件／散熱器，再縮短功率回路與取樣路徑、配置地平面並逐區走線。製板前仍須完整 DRC、電路與熱設計審查；試作板再量測音質、穩定度、啟停與溫升。沒有輸出 Gerber 或下單。

本機 KiCad 10.0.6 Python API 的部分舊通孔封裝寫出時會遺漏阻焊開口，生成器已補回，檢查工具會重新讀取板檔逐腳核對。這項工具相容處理不改變腳號或接線。專案自訂庫的來源與授權見 [Placement.pretty/README.md](Placement.pretty/README.md)。

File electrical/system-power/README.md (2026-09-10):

# 機內電源：一條市電線的整機架構

2026-09-11。使用者已確定成品採機內電源，機背只接一條市電電源線。以下是整機架構與電源候選，尚未完成市電配線施工圖、交流保護選型、機構熱驗證或採購。

機內電源架構

[放大向量圖](power-system.svg) · [低壓音訊／控制原理圖](../v03/README.md) · [機箱規劃](../../mechanical/機箱選擇.md)

## 已確定的使用方式

- 機背規劃單一 IEC C14 三芯電源入口與總電源開關，前面維持 AUTO／OFF／ON 控制；電源線型式與額定隨最終入口及使用地核定。
- 機內兩組隔離式 AC/DC 電源共用這個市電入口，分別提供 48V 主電源與 12V 待機／類比電源。
- J201、J202 改為機內供電接點，成品後板不提供兩個外接 DC 電源孔。
- 後方總電源開啟後，兩組電源持續工作；AUTO 跟隨 Z10 Trigger，板上 eFuse 控制功率級的 48V。
- Trigger 關閉先靜音，再停止功率級供電。兩組 AC/DC 與 12V 類比／控制仍有電，所以仍有待機耗電；不宣稱低於 0.5W 或零耗電。
- 後方總開關關閉會撤除兩組 AC/DC 的輸入，Trigger 無法喚醒。入口、開關上游與殘存電荷仍需按市電設備處理；維修先拔除電源線。

本次採現成隔離式 AC/DC 模組整合，音訊 PCB 維持低壓直流電路。尚未加入以 Trigger 關閉主 AC/DC 的市電繼電器，也未使用電源模組遙控功能。

## 第一輪候選

候選用於容量、空間與介面評估，確切料號須通過降額、保護協調、供貨與價格確認後才列入採購清單。

| 位置 | 候選 | 核對到的原廠資料 |
|---|---|---|
| PS1 主電源 | MEAN WELL UHP-200-48，標準型 | 48V、4.2A、201.6W；90–264VAC；本體 194×55×26 mm；無風扇，須依安裝方式與溫度降額 |
| PS2 輔助電源 | MEAN WELL RS-15-12 | 12V、1.3A、15.6W；85–264VAC；本體 62.5×51×28 mm；螺絲端子，另需防觸碰罩與固定空間 |

來源：[UHP-200 原廠規格，2025-08-01](https://www.meanwell.com/upload/pdf/UHP-200%28R%29/UHP-200-spec.pdf)、[RS-15 原廠規格，2026-04-10](https://www.meanwell.com/Upload/PDF/RS-15/RS-15-SPEC.PDF)。上述範圍涵蓋本案暫以台灣 110V／60Hz 為評估條件；不表示整機已完成全輸入範圍驗證。

UHP-200 的標準型與帶 R 選配型不可混淆；本案不依賴 DC OK 或冗餘選配。其安裝頁要求用底部鋁板支援指定曲線，建議板為 **300×300×3 mm**，亦提供無額外鋁板時的降額曲線。不能把模組本體尺寸當成完整散熱占位，也不能直接把任何機箱側散熱片當作等效散熱底板。

## 容量與保護需要對上的地方

兩聲道各 50W、功率級效率假設 90% 時，主功率需求約 111W；先另留 5W 給主 DC 路徑損耗，約 116W，增加 25% 容量預留後約 145W。12V 支路另暫編 5W，約 0.42A。這些是選型假設，非最大值驗證或實測；與舊版把輔助耗電合併在 48V 預算的估算方式區分。

兩個候選的名義容量可作第一輪評估，但仍要核對低輸入電壓、箱內高溫及動態負載。這個配置不代表可以保證兩聲道各 100W。

- PS1 調整目標 48.0V，不任意調到最高輸出。板上 eFuse 仍負責主 DC 過壓、欠壓與啟停。電源自身的過壓動作範圍不能替代功率晶片的保護。
- 目前 eFuse 名義限流約 4.5A，PS1 額定為 4.2A；正常目標負載低於兩者，但故障時哪一級先動作及是否反覆重啟尚未驗證，需協調限流、板上 F1 與電源保護。
- PS2 調整目標 12.0V。**J202 前的反接／過壓／過流保護仍待設計**；現有 TPS3808 只監測供電及靜音，不能當作供電串聯保護。RS-15-12 自身過壓保護的動作範圍高於 TPA3255 建議的 12V 支路上限，不能據此宣稱供電已受完整保護。
- 交流端的入口、保險絲、雙極總開關、端子、配線與湧流處理仍待選型；須考慮兩個 AC/DC 同時冷啟動及熱重啟，不能只用音訊平均功率推算交流保險絲。[TPA3255 供電要求](https://www.ti.com/lit/ds/symlink/tpa3255.pdf)

## 接地與裝配要求

整機按有保護接地的金屬機箱方向設計。IEC 入口的 PE 直接到機殼專用接地固定點，再連接需要接地的面板／電源 FG；PE 不經總開關、保險絲、R608 或音訊 PCB。R608 只負責訊號 GND 與 CHASSIS 的設計連接，不能充當保護接地導體。N、PE 與訊號 GND 不可在機內任意短接。

兩路 DC 負端按音訊板 GND 連接需求共用參考，仍需核對電源輸出與 FG 的內部關係，避免另增訊號地回路。XLR 屏蔽、RCA 絕緣與 Trigger 隔離維持原設計要求。

市電線束、端子罩、防鬆固定及與低壓訊號區的間隔，要和機構一起設計；螺絲伸入、通風與鄰近熱源依原廠安裝規定審查。不能把方塊圖中的分區當成已通過的電氣間隙或爬電距離。

原廠要求 FG 接保護地，並要求整合後重新確認系統表現；模組本身的認證不代表本台整機已通過。[明緯機殼型電源安裝手冊](https://www.meanwell.com/Upload/PDF/Enclosed_Type_CH.pdf)

## 下一步與驗證程度

本次完成使用需求、架構圖、原廠候選核對及低壓圖面接點說明。V0.3 音訊板的接線與簡化模型驗證不包含市電模組。

下一階段先補 12V 入口保護、確定交流入口與總開關／保險絲，再把兩個電源、熱路徑與線束放入 3D 配置。機箱仍未定案。市電裝配與第一次上電須由具市電設備經驗的人員檢查接地、絕緣及接線；實機再量測突波、掉電靜音、待機耗電、溫升與噪聲。

本圖為系統方塊圖，沒有端子施工順序或可直接交付製造的配線尺寸。PNG 更新：`rsvg-convert -o electrical/system-power/power-system.png electrical/system-power/power-system.svg`。

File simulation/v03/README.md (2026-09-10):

# V0.3 模型與結果

執行 `python3 tools/verify_v03.py`，從 V0.3 實際 KiCad netlist 建立 AC 模型並核對控制腳位。

- `ac-rca-*`／`ac-xlr-*` 的 `.cir`／`.csv`：兩種輸入各有 4Ω、8Ω、空載近似，以及理想功率級或自訂 100kHz 極點兩種假設，共十二組。XLR 以 pin 2／3 各 ±0.5V 形成 1V 差動，RCA 使用 1V。運放只有理想有限增益，沒有真實頻寬、噪聲及失真。空載使用 1GΩ 數值近似。
- `ac-summary.csv`：20Hz／1kHz／20kHz 的增益與相對 1kHz 響應，包含輸入種類。
- `ac-common-*`／`xlr-external-imbalance.csv`：同相驅動 XLR 正負腳；一組理想匹配，一組外部 47Ω 電阻 ±0.1%、配對 47µF 電容 ±0.5%。INA2137 內部四電阻採名義 12kΩ／6kΩ 理想比例；理想匹配案例的極大抑制數值只是數值運算殘差，不是實機性能。外部公差案例也未包含晶片內部失配、真實 REF 阻抗、電容漏電／ESR 與訊源阻抗。
- `sequence-*.csv`：控制時序規格模型，由腳位審查後的阻容值與電源門檻驅動。涵蓋正常開關、缺少任一電源、5ms Trigger 脈衝、主／輔助電源掉壓與 eFuse 故障鎖定。不是實際半導體暫態模擬。

改為機內雙電源後，另加 `sequence-psu_48v_late.csv` 與 `sequence-psu_12v_late.csv`，驗證兩個電源啟動順序互換時，均等待供電良好及延遲後才開聲。1s／3s 階躍是測試刺激，不是廠商實際啟動波形；完整控制案例共九個。尚未模擬市電側、電源實際突波或 3.3V 控制電源崩落的半導體行為。

輸入選擇端在 KiCad 是三腳接頭，模型明確閉合所選模式的接點；XLR 正負腳、耦合、Sense、REF 與參考緩衝器使用實際 netlist。電源偏壓仍理想化，沒有模擬上電偏壓建立、切換爆音或功率放大器 clipping。

完整數值與限制見 [驗證報告](../../electrical/v03/validation.md)。所有數據為設計模型輸出，沒有實測資料。

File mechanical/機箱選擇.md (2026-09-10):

# 機箱製作方式與現成候選

2026-09-11。使用者已確定機內電源、單一市電線；現成機箱加客製面板仍是建議方向，型號、採購與加工圖未定。

## 建議：現成鋁機箱＋客製前後面板

第一版優先使用可拆裝、前後板可加工的現成金屬機箱。由專案設計接頭孔位、PCB 固定、線材空間與散熱器接觸，再依圖交由機箱供應商或加工店製作。無須從零切割、折彎整個盒子。

| 方式 | 本專案的取捨 |
|---|---|
| 現成鋁機箱＋加工面板 | 優先方向；可利用既有殼體與表面處理，仍可自行安排接頭與內部機構 |
| 從鋁板完全自製 | 自由度高，但額外增加折彎、接合、公差及表面處理工作；待現成尺寸確實不合時再考慮 |
| 3D 列印 | 用於面板試裝樣件、鑽孔治具、線夾與裝飾；支架須依承重、耐熱與位置判定，不作第一版功率散熱主體 |

上述為設計判斷，未取得加工報價；最終比較機箱、面板加工、運費與稅費的總成本。AI／3D 工作仍包含整機裝配、孔位設計與干涉檢查，採用現成殼體也能保留這些課堂展示成果。

## 查得的尺寸參考

以下原廠頁面於 2026-09-11 核對，原先按外接電源方向列入比較。改為機內電源後，兩款均須重新檢查，不能直接當成整機候選已通過；尚未確認台灣庫存、到貨時間、價格或裝配相容性。

| 候選 | 原廠資料與比較重點 |
|---|---|
| [TAKACHI HY88-28-23BB／SS](https://www.takachi-enclosure.com/products/HY) | 黑／銀散熱側板鋁機箱。外部寬×高×深為 280×88×231 mm，內部為 236×76×225 mm；原廠提供對應 PDF／DXF 圖。優先作桌上型外形與裝配空間參考 |
| [Hammond 1455U2801](https://www.hammfg.com/part/1455U2801) | 鋁擠型機箱、金屬端板，有原廠尺寸圖。列為普通鋁殼對照方案，散熱器及通風需另外評估 |

TAKACHI 數字依原廠表頭 W×H×D；內部尺寸仍要扣除接頭伸入、螺柱、螺絲與線材彎曲空間，不能直接當成 PCB 可用面積。較低價的通用空白面板機箱也可納入比較，但需取得同樣完整的內部尺寸與板厚資料。

## 本電路需要安排的內容

- 後板：左右 XLR 母座、兩個 RCA、四個喇叭端子、絕緣 Trigger 插座，以及單一 IEC 市電入口／總開關；不設外接 48V／12V 電源孔。J201／J202 改為機內線束接點。
- 前板：AUTO／OFF／ON 操作位置；指示燈可預留空間，但 V0.3 尚未畫出完整面板燈號電路。音量仍由 Z10 控制。
- 內部：兩組 AC/DC 電源及其散熱／防觸碰／配線空間，另加四顆電感、主電容、輸入區、功率區、控制區、接地點、線材及螺柱。音訊板 180 個元件未包含交流電源系統；電路分頁也不代表八塊 PCB。
- XLR pin 1／外殼在入口接 CHASSIS，訊號地依 V0.3 單點連接；RCA 與 Trigger 插座按設計絕緣，不能靠面板碰觸形成非預期接地。
- 散熱：TPA3255 使用頂面散熱，需安排晶片至散熱器／機箱的實際熱路徑及固定力。側面有散熱片不表示晶片已獲得散熱；另核對 eFuse 與反接二極體的銅面散熱。[TPA3255 原廠資料](https://www.ti.com/lit/ds/symlink/tpa3255.pdf)

目前依[機內雙電源架構](../electrical/system-power/README.md)重排空間。PS1 暫以 UHP-200-48 比較：本體 194×55×26 mm，但原廠指定散熱底板參考達 300×300×3 mm，並有不同安裝方式的降額曲線；原小型候選不得只按模組本體判斷裝得下。可能需要更大底板與機箱，或依實際熱負載重新選電源，尚未定案尺寸。

市電區與音訊區的機械隔離、線束防鬆及端子罩需設計；IEC PE 直接連機箱專用接地點與電源 FG，訊號 GND 的 R608 不能替代保護接地。這部分的空間也必須納入板形規劃。

## 執行順序

1. 取得候選機箱、兩個電源與實際接頭尺寸圖，完成供電分區、PCB／散熱器及線束的初步空間配置。
2. 用 3D 裝配檢查元件高度、後板接頭、線材與固定點，同步調整 PCB 板形。
3. 比較含加工的總價與供貨情況，再定案殼體；通過配置及散熱審查後輸出前後板加工圖。
4. 試裝、量測溫升並修正。現有模型尚未達到本階段。

原 [220×180×70 mm 空間圖](README.md) 為 V0.1 歷史占位，未按 V0.3 新增的 XLR 與實際電感更新。它不是現成機箱型號，也不是可直接加工的全自製機箱圖。

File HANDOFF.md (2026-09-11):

# TPA3255 接班進度

更新：2026-09-11，Codex。儲存庫 `ewinkuo1-sudo/diy-tpa3255-amplifier`；本次工作副本 `~/Projects/diy-tpa3255-amplifier`，原副本仍在 `~/.openclaw/workspace/diy-tpa3255-amplifier`。

## 使用者方向與同步約定

AI 應用課程，可含電路、材料、PCB 與 3D 設計；期限、預算、設備未定。前級為 Eversolo DAC-Z10，喇叭為 Usher BE-718，初期目標 2×50W / 8Ω。Purifi 在另一獨立儲存庫。

使用者要求每次完成並檢查後立即 commit / push 並回報，首頁同步可看的圖面。推送前確認遠端進度，不覆寫其他協作者。最近要求由設計端選電感、處理 PCB 注意事項、配合 Z10 Trigger 自動開關，並補上 XLR。

最新已確定：**電源內建，機背只接一條市電電源線**。取代先前外接兩路 DC 的成品方向；不需再詢問內建或外接。

使用者表示看不懂電路圖。後續說明先用成品接線、用途與操作介紹，再提供零件細節；首頁已先放 `docs/使用方式圖解.md` 的中文圖解（SVG／PNG），說明 Z10、後級、喇叭、機內電源與 Trigger。這是功能示意，不是定案面板、板數、配置或比例圖。

最新要求開始 PCB；已完成第一份未走線配置草案。可以先做配置與封裝審查，不需要等到實機音質量測後才能開始；正式走線／製板仍須處理下述電路與熱設計問題。

最新回饋：使用者要的是將八頁的所有內容重新編排成一張連續電路圖。前一版 A0 直式只是將八頁位置平移到 2×4 方格，不符合這個意思；已改成下述 **A0 橫式整合電路圖**。

## 新增：重新佈圖與連續接線的完整電路

- `electrical/v03/tpa3255-v03-overview.kicad_sch`／同名專案：保留原八頁全部 180 元件、192 符號單元（含電源旗標）。左右音訊由輸入經驅動、TPA3255 到 LC 與喇叭；四路 PFFB 直接沿回線繞回 SUM。下方串接 Trigger、隔離、啟停條件、48V eFuse 與 RESET。供電／偏壓及部分狀態線使用同名局部標籤。
- `tools/integrated_schematic_layout.py` 定義元件位置、導線與中文閱讀提示；`tools/build_schematic_overview.py` 為入口及原生格式共用函式。讀目前八頁來源，未呼叫會覆寫來源的初始電路生成器。
- U1／U601 的圖形腳位依訊號流重新排列，另存 `Overview.kicad_sym`；`sym-lib-table` 加入該庫，原 Project 庫未修改。元件 UUID、單元、實體腳號、名稱與電氣型態保留。其他符號仍使用 Project 庫。
- `tools/verify_schematic_overview.py` 比對原版／整合版實際匯出接線表與 `expected-connections.csv`：180 元件、483 腳位、120 網路群組。另比對每腳電氣定義、原生單元身份與屬性；移除標籤後再次匯出接線表，確認音訊、四路回授與主要啟停路徑確實由導線連通。兩版 ERC 要求 0 錯誤／0 警告，無排除。
- `overview-sources.json` 保存來源及總圖雜湊。局部標籤匯出時自訂名稱增加 `/` 路徑前綴；原未命名節點使用接線契約名稱。電氣等價以腳位群組判斷。
- A0 橫式向量 PDF／SVG 與 4800 像素 PNG 已同步至首頁；放大可看元件數值。原八頁 PNG 仍收在可展開區域。

**八頁來源仍是電路與既有 PCB 維護主檔**；板檔 UUID 路徑對應原階層，請從原專案更新 PCB。先改來源，再調整整合圖配置與接線並重建／驗證。總圖手改不會回寫來源，重建會覆寫衍生檔。這次未改電路功能、PCB 或性能模型，未新增實機驗證。

```sh
python3 tools/build_schematic_overview.py
python3 tools/verify_schematic_overview.py
python3 tools/export_schematic.py electrical/v03/tpa3255-v03-overview.kicad_sch --pdf-from-svg --png-width 4800
```

匯出工具仍只更新這次實際輸出的檔案，避免八頁原版與總圖共用檔名前綴時誤覆寫彼此的 PNG。

## 目前成果：V0.3 原理圖草案

- `electrical/v03/tpa3255-v03.kicad_pro`：八頁原理圖，依序為功率級、訊號驅動、類比供電、PFFB、Trigger、主電源開關、控制供電、XLR 輸入。
- `electrical/v03/README.md`：單頁總圖為預設看圖入口，原八頁 PNG／SVG／PDF 保留在可展開區域。180 個元件；原理圖 Footprint 欄位仍空白，PCB 封裝候選另列，尚未定料放行。
- `docs/V0.3_設計說明.md`：元件來源、訊號路徑、控制方式與限制；`docs/V0.3_PCB設計要求.md` 為下階段佈局要求。
- L1–L4 選 Coilcraft MA5172-AE：10µH，25°C 最大 DCR 26mΩ；45A 是典型 10% 電感下降條件，不是連續額定。
- 四路同臂 PFFB 採 TI SLAA788A TPA3255 範例起始值，SUM 在 AC 耦合前；輸出阻尼為 220nF + 1Ω，NE5532 回授補償 330pF。真實穩定裕度尚未驗證。
- XLR：U601 INA2137UA，實體 SOIC-14 腳位，約 0.5 倍差動接收；U602 兩個 NE5532 跟隨器提供低阻抗 REF。正負線各串 47Ω／0.1% 與 47µF BP，按聲道配對電容到 1%；輸出再隔直流。R607／C609 獨立濾波 12V 支路，C607／C608 本地去耦。
- J603／J604 各裝一個跳線帽：兩個都接 2–3 選 XLR，兩個都接 1–2 選 RCA，預定初裝 XLR。切換先將 J302 設為 OFF 待機；尚無面板切換／切換靜音電路。
- XLR pin 1／金屬外殼接 CHASSIS，R608 單點接 GND；RCA 插座絕緣。Trigger 的 TRIG_RETURN 維持隔離。
- Trigger 以 12V 名義、9–15V、tip 正／sleeve 負為待實測假設。Z10 手冊確認有 Trigger，但缺少完整電流、電平容差與極性資料。12V 設計負載約 1.6mA，不能引用其他機種 150mA 當成 Z10 規格。
- J302 外接 AUTO／OFF／ON 的 SPDT 中心斷開開關。TPS3808 監測輔助電源與 PVDD；開機先升功率電源，再延遲開聲；關機先 RESET 靜音，再延後停止 eFuse。
- 主電源以 TPS26631PWPR 切換、STPS5H100B 反接保護。eFuse 約 4.5A 名義限流，MODE 懸空選鎖定，軟啟動名義約 2.2s；F1 為 T5A／至少 80VDC 的規格占位，尚未選料號／協調曲線。
- PCB 封裝核對修正 D303 BAT54：原兩腳邏輯符號改為 SOT-23 實體 1=AUDIO_MR（A）、2=NC、3=AUX_GOOD（K），功能方向不變；原理圖、符號庫、接線契約與檢查已同步。D301／D302 仍採邏輯 A=1、K=2，專用 DO-35 封裝已反轉標準庫編號以維持陰極帶正確。
- 整機電源見 `electrical/system-power/README.md` 與方塊圖：單一 IEC 入口、交流保護／雙極總開關待選，機內 PS1 UHP-200-48 與 PS2 RS-15-12 為首輪候選，尚未採購。J201／J202 圖面文字已改為機內 DC 接點；音訊原理圖不含市電。
- Trigger 關機為待機：只切功率級 48V；兩組機內 AC/DC 及 12V 類比／控制仍有電。後方總開關撤除兩組 AC/DC 的輸入。待機耗電未測，功率電容不會立即放空。
- V0.2 圖面與模型保留於 `electrical/`、`simulation/` 上層，作為歷史基線。機殼仍是 V0.1 占位模型，尚未按電感／XLR／散熱器重新配置。

## 新增：PCB 初步配置

`electrical/pcb-draft/tpa3255-placement.kicad_pcb`／同名專案可直接用 KiCad 10 開啟。180 個電路元件（正面 127／背面 53）、4 個 NPTH 固定孔；暫用 220×160 mm、4 層、1.6 mm，尚無走線與覆銅。只包括低壓音訊與控制，機內 AC/DC 和市電線束另置。

`placement.csv` 記錄初始配置／封裝候選／來源 SHA-256。主要 IC 封裝族與腳序已核對；其餘電容、電阻、F1／座和板端接頭多為占位，全部仍未放行製造。面板 XLR／RCA／Trigger 插座不是這些排針，線束與防呆接頭待選。初始位置定義在 `tools/build_pcb_draft.py`；CSV 是輸出記錄，改板檔後需同步更新，不能把 CSV 當成自動匯入來源。

首頁已有中文 PCB 配置圖；`preview/top`、`bottom` 是 KiCad 原始預覽，背面以背面視角輸出。中文圖嵌入真實板檔匯出，不繪製虛構走線。散熱器與 12V 保護只預留框，尚未完成機構干涉／高度與熱路徑驗證。電源與訊號回路仍需縮短、重新微調配置。

## 驗證

`python3 tools/verify_v03.py` 通過：KiCad 10.0.6 ERC 0 錯誤／0 警告（無排除）；180 元件、483 腳、120 nets 群組吻合預期，另以獨立實體腳位檢查 XLR、PFFB、電源及控制。較前版多出 BAT54 實體 NC 腳及其獨立未接網路。

ngspice 47 執行 12 組 RCA／XLR AC 模型（4Ω、8Ω、空載 × 功率級無限頻寬／自訂 100kHz 極點）與 2 組共模模型。50W/8Ω 名義靈敏度約 RCA 2.126Vrms、XLR 差動 4.268Vrms；按 Z10 2.5／5Vrms 驅動，三個檢查頻率的輸出差異均小於 0.1dB。

9 個控制時序規格模型涵蓋正常開關、任一電源缺失、5ms Trigger 脈衝、主／輔助電源掉壓、eFuse 鎖定，以及新增的兩路電源啟動順序互換。後兩者用 1s／3s 階躍作測試刺激，非廠商波形。腳位與阻容核算不能當成實際半導體或市電驗證。數據及原始模型位於 `simulation/v03/`。

運放及 INA2137 內部比例仍理想化，TPA3255 只有線性增益源，100kHz 極點是自行假設；未驗證 PWM 延遲、真實 CMRR、噪聲、THD、迴路穩定裕度或偏壓建立爆音。已檢視圖面預覽；PCB 未走線，沒有 Gerber、整機 EMI／熱或實測。

`python3 tools/verify_pcb_draft.py` 通過：483 個電氣腳號／484 個編號銅焊盤（DPAK 腳與 tab 共用 2）、120 nets 與原理圖及接線契約吻合。符號 UUID、關鍵封裝腳位、通孔阻焊開口、焊盤位於板內均檢查；幾何／封裝 DRC 0 違規，**仍有 364 項未連接**，保留在 `drc.json`，不能稱為完整製造 DRC 通過。KiCad 10.0.6 獨立 Python API 對舊式 THT 封裝寫出阻焊層有差異，生成器已在原生檔案宣告中補回，驗證會重新載入確認；不得移除此檢查。

使用方式圖解僅更新文件與預覽，未改電路；檢查 SVG 格式、中文排版及文件連結，不重跑電路模型。

## 下一步

機箱仍優先現成鋁機箱＋客製面板，但需因機內電源重排。原 TAKACHI HY88-28-23／Hammond 1455U2801 小型候選尚未通過；UHP-200 本體雖小，其指定散熱底板參考為 300×300×3 mm，需審查降額或換用適合的電源／機箱。不得只看本體尺寸就宣稱裝得下。V0.1 空間圖仍保留歷史。

市電入口、交流保險絲／雙極總開關、湧流與端子防觸碰、機殼 PE 固定、12V 入口保護均未完成；R608 不是保護接地導體。原廠資料已核對並附來源，但整機配線、絕緣、EMI、噪聲與熱驗證尚未完成。市電裝配與初次上電需具相應經驗的人員檢查。

1. 驗證 PFFB 在實際 TPA3255、運放頻寬、電感容差與開路／不同喇叭負載下的穩定裕度。不可憑目前 AC 模型直接製板。
2. 審查 XLR 單電源擺幅／共模範圍、配對電容及訊源阻抗影響、REF 雜訊、上電偏壓建立與插拔／切換靜音；選 XLR 母座與後板佈局。
3. 確認 Z10 Trigger 電壓、極性與帶載能力，驗證正常及突然掉電時序；關機 RC 的 0.071–0.983s 是工程包絡，不是保證閾值。
4. 核定 48V 穩壓供電、12V 輸入保護、保險絲協調、eFuse／反接二極體散熱、電感磁芯損耗、其他料號與全部 footprint。
5. 以現有 PCB 配置為起點；定料後回填原理圖 Footprint，核對與板檔同步方式，再逐區佈線與覆銅，同步安排機箱、散熱器和面板線束。預留 XLR、RCA、絕緣 Trigger 與 AUTO／OFF／ON 操作介面。

## 工具與更新方法

本機已有 KiCad 10.0.6、kicad-library、ngspice 47、rsvg-convert；尚未安裝 OpenSCAD／FreeCAD。原廠資料表暫存在 `/tmp/tpa3255-reference`，持久連結列於設計文件，未將原廠 PDF 放進儲存庫。

```sh
python3 tools/verify_v03.py
python3 tools/export_schematic.py electrical/v03/tpa3255-v03.kicad_sch
python3 tools/verify_pcb_draft.py
python3 tools/export_pcb_draft.py
```

`tools/build_schematic_v03.py` 可重建 V0.3 初始圖面，但會覆寫專案、八頁圖面、符號庫及預期接線表；人工修改後避免直接執行。更改生成器後需審查新接線，再驗證／匯出。KiCad 10 `sym-lib-table` 必須保留標準多行格式。

舊 `tools/build_schematic.py`／`verify_electrical.py` 僅處理 V0.2；匯出工具未給參數時亦保留 V0.2 行為。

`tools/build_pcb_draft.py` 只生成初始配置；已有板檔時預設拒絕覆寫，`--force` 會丟棄人工改動。正式接續 PCB 工作前先讀草案 README，避免重新生成覆寫。`Placement.pretty` 內 DO-35 衍生封裝沿用 KiCad CC BY-SA 4.0 與附加例外，附授權文件；其餘專案自訂占位沿用 MIT。

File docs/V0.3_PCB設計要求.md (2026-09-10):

# V0.3 PCB 設計要求

依使用者要求，以下由設計端處理，不要求使用者自行決定走線。已開始[PCB 零件配置草案](../electrical/pcb-draft/README.md)，尚未走線；以下要求仍需在細部佈局與走線中落實。

整機已改為[機內雙電源、單一市電入口](../electrical/system-power/README.md)。音訊板只接兩路低壓 DC，市電端子與線束另設區域；機箱內須預留保護接地與電源散熱，不能沿用早期純音訊板占位。

| 區域 | 佈局與驗收要求 |
|---|---|
| 功率級 | 依 TI EVM 與資料表縮短 PVDD／半橋／去耦回路；bootstrap 電容放在對應 BST 與 OUT 腳旁 |
| 地平面 | 維持連續地平面，靠元件分區與回流路徑控制干擾；不任意切割地平面 |
| PFFB | 從各自 LC 濾波後的輸出取樣；回授走線遠離 OUT 開關節點與電感，保持四臂對稱 |
| 輸入 | RCA、XLR 接收器與 NE5532 放在低噪聲區；12V 類比去耦在元件旁；避免主電流流過輸入地與 VMID 回路 |
| XLR | 母座 pin 1／金屬外殼在入口接 CHASSIS；R608 單點接訊號 GND，RCA 插座絕緣；pin 2／3 走線及 47Ω／47µF 支路對稱；四顆輸入電容按聲道配對到 1% |
| 輸入選擇 | J603／J604 保留短路帽及操作空間，標清 RCA 1–2／XLR 2–3，初裝 XLR；前端配線短，面板切換與靜音另行設計 |
| 接收器參考 | U602 到 U601 REF 走線短；不與功率電流共用回流；INA2137 不能直接以未緩衝的 VMID 分壓器驅動 REF |
| 電感 | 四顆 MA5172-AE 各預留 28.6×12.3mm 本體包絡；腳距 10±0.5mm、最大線徑 1.07mm；鑽孔及焊盤另行核定，重件需固定 |
| 開關電源路徑 | TPS26631 的 PowerPAD 接地與導熱過孔，STPS5H100B 的 cathode tab 電位不可誤接 GND；依損耗分配銅面，遠離前端 |
| 控制 | U302–U307 各有本地去耦；CT、SENSE 與保持電容遠離開關節點；eFuse 設定電阻靠近 IC |
| 機內供電 | J201 接主 DC、J202 接持續供電的 12V；待補 12V 入口保護。兩路電源啟動先後、掉電及突波須另驗證 |
| 保護接地 | IEC PE 直接到機箱專用接地點及電源 FG；不依賴 PCB、訊號地 R608 或可拆訊號線維持保護接地 |
| Trigger | 絕緣插座；TRIG_RETURN 不接 GND／機殼；隔離兩側的銅面與焊盤不可誤連 |
| 喇叭端 | BTL 兩端均為輸出；左右負端不共接、不接機殼；預留差動量測位置 |
| 機構 | 為兩個 XLR 母座、兩個 RCA、絕緣 Trigger 插座與電源／喇叭端子預留後板空間；高度與散熱器仍需實際封裝核對，V0.1 機殼只是占位；八頁原理圖不表示八塊 PCB |

來源：[TPA3255 §12](https://www.ti.com/lit/ds/symlink/tpa3255.pdf)、[TPA3255EVM](https://www.ti.com/lit/ug/slou441/slou441.pdf)、[PFFB §1–2](https://www.ti.com/lit/an/slaa788a/slaa788a.pdf)、[TPS2663 §10](https://www.ti.com/lit/ds/symlink/tps2663.pdf)、[Coilcraft 外形圖](https://www.coilcraft.com/getmedia/5fb1a3ea-b3b6-4ae7-89c3-2a4c68c350e4/ma5172.pdf)。

XLR 接收器腳位、Sense／REF 與去耦依 [INA2137 原廠資料](https://www.ti.com/lit/ds/symlink/ina137.pdf) 核對；母座封裝需再依選定製造商確認，不能以通用三腳符號猜測實際孔位。

板層、線寬、孔徑、銅厚及距離必須依製程、溫升與回路要求核定；這張表不替代 DRC、熱分析或實機量測。

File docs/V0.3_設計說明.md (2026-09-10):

# V0.3：XLR／RCA、音質改版與前級 Trigger 自動啟停

2026-09-11。依使用者要求加入 XLR，保留 RCA，由設計端選擇電感、依 Z10 前級匹配輸入，加入 Trigger 自動開關機，並採用前次音質改善建議。此版為原理圖草案，已有[PCB 初步配置](../electrical/pcb-draft/README.md)，尚未走線或實機驗證。

開始 PCB 封裝核對時，已將 D303 BAT54 從邏輯兩腳符號修正為實體 SOT-23：1=A 接 AUDIO_MR、2=NC、3=K 接 AUX_GOOD；功能方向不變，避免套入封裝時誤接到 NC。依 [BAT54 原廠腳序](https://assets.nexperia.com/documents/data-sheet/BAT54.pdf)，並同步更新接線檢查。

[八頁電路圖與 PDF](../electrical/v03/README.md) · [驗證結果](../electrical/v03/validation.md) · [BOM 草案](../electrical/v03/bom-draft.csv) · [PCB 設計要求](V0.3_PCB設計要求.md)

## 使用時會怎麼動作

```mermaid
flowchart LR
    A[Z10 Trigger 開機訊號] --> B[隔離接收與電源檢查]
    B --> C[功率級 48V 緩慢上升]
    C --> D[電源穩定後延遲開聲]
    E[Z10 Trigger 關機訊號] --> F[先靜音]
    F --> G[延後切斷功率級 48V]
    G --> H[待機，等待下次 Trigger]
```

整機依使用者要求改為[機內電源、單一市電線](../electrical/system-power/README.md)，48V／12V 均由機內模組供應，J201／J202 為機內接點。Trigger 關機是進入待機：切斷板上功率級的 48V 供電；兩組 AC/DC 及 12V 待機／類比支路仍有電，總耗電待實測。後方總開關處理整機供電，音訊 PCB 不切換市電。交流保護與配線不在本版低壓原理圖內。

J302 接三段 AUTO／OFF／ON 開關。AUTO 跟隨前級；OFF 為開關中心斷開；ON 手動開啟，但仍受電源監測與延遲控制。開關連接腳為 1=AUTO、2=公共端、3=ON。

## 電感已選擇：四顆 Coilcraft MA5172-AE

| 項目 | 原廠資料／本版用途 |
|---|---|
| 位置與數量 | L1–L4，共四顆，BTL 每聲道兩顆 |
| 電感量 | 10µH，資料表容差 ±1µH |
| 直流電阻 | 25°C 最大 26mΩ；取代 V0.2 模型的假設 50mΩ |
| 電流與溫升 | 6.1Arms 對應 20°C 溫升、8.2Arms 對應 40°C 溫升，依原廠測試條件 |
| 電感下降電流 | 25°C、45A 對應典型 10% 電感下降；不能當成 45A 連續額定 |
| 機械空間 | 本體最大直徑 28.6mm、厚 12.3mm，腳距 10.0±0.5mm，線徑最大 1.07mm |

來源：[Coilcraft MA5172/3-AE、PA6331-AE，Doc 943-1，2023-04-11](https://www.coilcraft.com/getmedia/5fb1a3ea-b3b6-4ae7-89c3-2a4c68c350e4/ma5172.pdf)。

選它是因為有 Class-D 應用、電流與機械資料可核對。50W/8Ω 的喇叭電流為 2.5Arms；加入本版簡化的開關紋波估算後約 2.62Arms，低於上述溫升參考電流。銅損估算不含磁芯損耗，實際 450kHz、偏磁及封閉機箱溫升仍要量測。

7µH 的 MA5173-AE 及 15µH 的 PA6331-AE 屬不同濾波設計，不能直接代換。四顆電感需一起考慮容差、左右對稱、固定方式及 PCB 回路；不把標稱電流較大當作音質保證。TPA3255 也要求過流點仍保有足夠電感量，需檢查高溫與保護條件。[TPA3255 §7.3、§9.4](https://www.ti.com/lit/ds/symlink/tpa3255.pdf)

## 回授與輸入級一起修改

已加入四路同臂 PFFB：`SPK_A→SUM_A`，B／C／D 同理。採 TI TPA3255 範例的起始參數：33kΩ 回授、2.7kΩ 輸入加總電阻、220pF／220pF／10kΩ 高頻支路，輸出阻尼改為 220nF＋1Ω；運放回授電容改為 330pF。加總點位於送往晶片的耦合電容之前。[TI SLAA788A，Figure 2、Table 1](https://www.ti.com/lit/an/slaa788a/slaa788a.pdf)

本板保留 RCA 輸入與兩級 NE5532 差動轉換，第一級改為 11.5kΩ 輸入／10kΩ 回授，第二級 10kΩ／10kΩ。這是因應 PFFB 降低增益後重新匹配，不是直接套用 TI 整張 EVM。RCA 端約 100kΩ 並聯 11.5kΩ 的中頻負載，尚需核對 Z10 的實際帶載表現。新增的 XLR 接收器與 RCA 共用後段驅動級。

原廠 Z10 規格標示 RCA 2.5Vrms、XLR 5Vrms，均為 0dBFS。模型下達到 50W/8Ω 需要約 2.126Vrms RCA 或 4.268Vrms XLR 差動訊號，保留名義輸入餘裕；滿刻度輸入仍可能超過 50W，這不是硬性功率限制。[Eversolo DAC-Z10 官方手冊，P14](https://www.eversolo.com/files/DAC-Z10%20User%20Manual-v1.0.pdf)

在無限頻寬功率級的簡化模型中，20kHz 相對 1kHz 為 4Ω 約 −0.28dB、8Ω 約 +0.30dB；這只是設計分析。加入自訂 100kHz 功率級極點也重新計算，供敏感度比較。這兩種模型都沒有真正的 PWM 延遲、運放頻寬／失真／噪聲，因此不能用來宣稱音質或迴路穩定性已通過。

## XLR 平衡輸入怎麼接

```mermaid
flowchart LR
    X[左／右 XLR 母座] --> C[正負兩線各自隔直流]
    C --> R[INA2137 差動接收，約半倍增益]
    R --> S[左右輸入選擇跳線]
    A[左／右 RCA] --> S
    S --> N[NE5532 差動驅動]
    N --> T[TPA3255、LC 與 PFFB]
    T --> L[左／右喇叭]
```

J601／J602 是左右 XLR 母座，接點編號依插座原廠圖面核對，不依正面目視猜測：1 為屏蔽、2 為正訊號、3 為負訊號。2、3 腳分別接到 U601 INA2137UA 的正／負輸入，平衡接收後轉成單端，再送既有 NE5532 差動驅動級。這項設計主要處理兩條訊號線共同受到的干擾；是否比 RCA 安靜要看訊源、配線、PCB 與量測。

U601 以 SOIC-14 實體腳位繪製；Sense 接自身輸出，採原廠 0.5 倍組態。REF 需要低阻抗，故新增 U602 的兩個 NE5532 跟隨器，分別驅動左右 REF，避免直接負載原本 VMID 分壓器。U601／U602 使用獨立的 10Ω／100µF 濾波支路及各自 100nF 去耦。[INA137／INA2137，腳位圖與 Figure 1、REF 說明](https://www.ti.com/lit/ds/symlink/ina137.pdf)、[NE5532 單位增益工作與電源要求](https://www.ti.com/lit/ds/symlink/ne5532.pdf)

兩條 XLR 訊號線各串 47Ω／0.1% 與 47µF／25V 無極性電容，阻擋單電源偏壓流入前級。C601/C602、C603/C604 各成一對，需挑選實測電容量差異不超過 1% 的料件；一般電解電容標示 ±20% 並不能保證配對。接收器輸出再以 C605／C606 隔直流，100kΩ 提供選擇器前的直流回路。完整阻容值已納入模型，未把電容視為短路。

J603／J604 每聲道各一個三腳選擇端：均接 **2–3 為 XLR（預定初裝設定）**，均接 **1–2 為 RCA**。每個端子只裝一個跳線帽，兩種訊源不混接；先將 J302 設為 OFF 待機後再改設定。圖面中的接頭不會在 KiCad netlist 自動短接，模擬明確依所選模式閉合對應接點。面板切換、切換靜音及接頭確切料號仍待後續設計。

XLR pin 1 與金屬外殼在入口接機殼，J605 是機殼連接點；R608 是訊號 GND 與 CHASSIS 的單一 0Ω 連接。RCA 插座採絕緣安裝，避免出現額外機殼接點。Trigger 的隔離回線仍獨立，不接到這個屏蔽網路；PCB 須讓屏蔽回流避開安靜的輸入地。

搭配 Z10 時，依其手冊將 Output Port 選為 **XLR Only**，XLR Polarity 使用正常極性；使用 RCA 時則選 RCA 輸出。先從低音量開始調整。[Z10 官方手冊，P22](https://www.eversolo.com/files/DAC-Z10%20User%20Manual-v1.0.pdf)

XLR 與 RCA 的十二組負載／極點模型及兩組共模測試已通過；以 Z10 標示的 5／2.5Vrms 輸入比較，20Hz、1kHz、20kHz 的輸出差異均小於 0.1dB。模型使用理想內部電阻比與運放，不代表 INA2137 的真實 CMRR。實際電容匹配、訊源阻抗、共模範圍、12V 低電壓下的最大擺幅、偏壓建立／切換爆音、ESD／射頻干擾及失真仍需檢驗。

## Trigger 的規格邊界

Z10 官方手冊確認有 Trigger IN／OUT，官方韌體說明也列出聯動關機功能。查得的官方手冊沒有完整列出輸出電流能力、接點極性或電平容差；本版以 **12V 名義、9–15V 設計輸入範圍、tip 正／sleeve 負** 作為待實測的介面假設，沒有套用其他 Eversolo 型號的 150mA 額定。[Z10 官方手冊](https://www.eversolo.com/files/DAC-Z10%20User%20Manual-v1.0.pdf)、[官方下載與韌體紀錄](https://www.eversolo.com/en/downloads/dac-z10)

U301 VOS618A-3T 光耦接收訊號，6.8kΩ 限流，12V 時 LED 名義約 1.6mA；1N4148 保護 LED 反向電壓。`TRIG_RETURN` 不接板上 GND 或機殼，插座也須絕緣安裝，避免多出接地回路。這是訊號隔離；不把元件的隔離測試額定當成整板安規認證。[Vishay VOS618A](https://www.vishay.com/docs/83465/vos618a.pdf)

實機接線前需確認 Z10 Trigger 的電壓、正負極、待機電平，以及接上約 1.6mA 負載後能否保持正常。這是硬體相容性待辦，不是已完成的測試。

## 電源監測與實際斷開功率電源

U303 TPS3808 監測 12V，名義門檻 11.22V；Trigger 和 12V 正常後才產生 `AUX_GOOD`。U304／D302／R310／C304／U305 提供掉電保持：關閉請求先撤除音訊允許，再延後撤除 eFuse 使能。保持時間需以實際邏輯閾值、二極體、漏電和電容確認，試算包絡不是保證規格。[TPS3808，SBVS050N，2026-08 修訂](https://www.ti.com/lit/ds/symlink/tps3808.pdf)、[SN74LVC1G17](https://www.ti.com/lit/ds/symlink/sn74lvc1g17.pdf)、[SN74LVC1G14](https://www.ti.com/lit/ds/symlink/sn74lvc1g14.pdf)

U401 TPS26631PWPR 切換 48V。設定約 4.5A 名義限流，依該型號還具有短時 2 倍電流支援；MODE 留空選擇過載鎖定。2.2µF 設定名義約 2.2 秒軟啟動。324kΩ／10kΩ 設定欠壓，412kΩ／10kΩ 設定約 50.64V 過壓切斷。供電以穩壓 48V、±2% 作為下一步電源選型要求。[TPS2663，SLVSE94G，§5、§6.5、§8](https://www.ti.com/lit/ds/symlink/tps2663.pdf)

PGOOD 與 AUX_GOOD 共同控制 U306，U306 再監測 PVDD 約 40.9V，電源良好後延遲約 1.03 秒釋放 RESET。不能只依靠 PGOOD：eFuse 本身的狀態、實際 PVDD 及輔助電源都要符合條件。正常關機的保持時間以 3.3V 待機電源仍正常為前提；突然失去全部供電時，是否無爆音仍需實測。

D401 選 STPS5H100B 作主電源反接阻擋，需核對 DPAK 散熱。未使用 eFuse 外接反向阻擋 MOSFET，也尚未完成輸入突波抑制與 ESD 測試；不能把 eFuse 功能列表當作本板全部已具備的保護。[STPS5H100 資料表](https://www.st.com/resource/en/datasheet/stps5h100.pdf)

TPA 的 FAULT／CLIP_OTW 保留供量測，沒有將 FAULT 直接接回 RESET，以免啟動時正常的 FAULT 低態造成循環重啟。晶片內建故障保護仍運作。eFuse 過載鎖定後須讓 Trigger 關閉足夠久、使 SHDN 確實下降，再重開；除錯先以 OFF 至少 2 秒作測試條件，實機再核定。

## 完成程度與下一步

- 已完成：八頁原理圖、XLR 差動接收與 RCA 選擇、PFFB 改版、電感選型、Z10 電平匹配、隔離 Trigger 接收、監測與主電源開關草案。
- 已檢查：ERC、接線群組、關鍵控制腳位、音訊 AC 簡化模型，以及開關機／缺電源／掉壓／Trigger 短脈衝／eFuse 鎖定的時序規格模型。
- 尚待：真實迴路與運放模型／實測、XLR 輸入匹配與偏壓暫態、Trigger 相容性、電源切換與電感熱、全部封裝和最終料號、保險絲協調、12V 輸入保護、PCB、噪聲／THD／EMI 量測。

目前不產生 Gerber 或製板訂單。下一階段先審查上述硬體限制並完成料件及封裝，才能凍結 PCB；V0.2 原理圖及數據保留為歷史基線。

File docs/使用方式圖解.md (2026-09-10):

# 先看這台後級怎麼用

原理圖是在說明每個零件怎麼接。要理解這台產品，可以先從自己的設備和操作看起。

後級使用方式：Z10、喇叭、一條電源線與 Trigger

[放大看圖](preview/amplifier-explained.svg)

## 你每天會接觸的部分

**Z10 送出音樂 → 這台後級提供推動喇叭的力量 → 左右喇叭發聲。** 音量由 Z10 控制。

| 接什麼 | 做什麼 |
|---|---|
| 音樂線 | 從 Z10 接到後級。規劃使用左右兩條 XLR，也保留 RCA 輸入。第一版由機內跳線選擇，尚未設計面板輸入切換開關。 |
| 喇叭線 | 從後級接到左右喇叭，左右各一組。 |
| 一條市電電源線 | 從牆壁插座接到後級機背；主電源與待機電源都放在機箱裡。 |
| Trigger 控制線 | 前級透過這條線通知後級開機或待機。它不傳音樂，也不供應後級用電；不接這條線仍可手動開機。 |

前方規劃 **AUTO／OFF／ON**：AUTO 跟隨前級的 Trigger，OFF 進入待機，ON 手動開機。這些操作都以後方總電源開關已開啟為前提；音量交給 Z10。

待機會先靜音，再停止功率級供電；機內電源與控制電路仍有電、仍耗電。後方總電源開關關閉後，前級就不能喚醒後級。

## 原理圖和成品的關係

機箱內規劃主電源、待機電源、擴大電路與開關控制。原理圖把它們細分成零件與接線，供設計、檢查及製作電路板使用；圖上的位置不代表零件在機箱裡的實際位置，八頁圖也不代表八塊板。

這張圖是使用方式與功能示意，**不是定案外觀或實際內部配置**。目前已開始[PCB 零件配置](../electrical/pcb-draft/README.md)，尚未走線或製成實機；電源保護、散熱、機構與 Z10 Trigger 相容性仍需完成設計或驗證。

需要了解內部供電時，再看[電源架構](../electrical/system-power/README.md)；零件與接線細節見[八頁原理圖](../electrical/v03/README.md)。

圖面來源為同目錄 `preview/amplifier-explained.svg`；更新預覽：

```sh
rsvg-convert -o docs/preview/amplifier-explained.png docs/preview/amplifier-explained.svg
```

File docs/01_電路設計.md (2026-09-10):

---
title: TPA3255 電路設計
date: 2026-09-10
updated: 2026-09-10
status: planning
tags: [audio, amplifier, DIY, TPA3255, ClassD]
---

# TPA3255 從頭畫

> 上層：[TPA3255 專案首頁](../README.md)
>
> 規格數字來源：TI TPA3255 datasheet（SLASEA8A）、TPA3255EVM User's Guide。**畫圖前把 datasheet 的 Typical Application 與 Layout Guidelines 章節整份讀完**，這份筆記只是摘要。

> 2026-09-10 第二輪查核：修正增益、供電與部分選用敘述；本頁仍為摘要。架構見 [V0.1 設計規格](V0.1_設計規格.md)，目前實際電路草案見 [V0.2 電路設計](V0.2_電路設計.md)。

## 核心概念

用 TI TPA3255 晶片從零設計 D 類放大板。完整的 PCB 設計練習，完成後當備機或推桌面喇叭。

## TPA3255 規格（datasheet）

- 類型：Class D，閉迴路模擬回授，**pre-filter feedback**（回授取自 LC 濾波器之前的切換輸出）
- 輸出模式：4ch SE / 2ch BTL（立體聲）/ 1ch PBTL（單聲道橋接）/ 2.1 混用
- 功率：
  - 2ch BTL：315W×2 / 4Ω、185W×2 / 8Ω（10% THD+N）；1% THD+N 為 260W×2 / 4Ω、150W×2 / 8Ω（原廠條件，非本案實測）
  - 1ch PBTL：600W / 2Ω
- THD+N：~0.01%（1W，1kHz）
- SNR：~105–110dB（A-weighted）
- 效率：>90%
- 電源：PVDD 功率電源：4Ω 條件建議 18–53.5VDC（§7.3）；另需 VDD / GVDD 輔助供電
- 增益：晶片沒有 GAIN0 / GAIN1；§7.5 列典型 21.5dB。整機增益需連同前端與差動訊號定義計算
- 封裝：HTSSOP-44（DDV），**PowerPAD 在封裝頂面**，腳距 0.5mm
- 內建保護：過流、過溫、欠壓、短路、DC 偵測

## Pre-filter feedback 的意義

TPA3255 的回授迴路不包含輸出 LC 濾波器，所以：

- LC 濾波器的頻率響應直接呈現在喇叭端，**會隨喇叭阻抗變化**（4Ω 與 8Ω 的高頻響應不同）
- 電感的線性度、DCR、飽和特性直接影響失真與阻尼
- 這是它與 Purifi / Hypex（post-filter feedback）在架構上的根本差異，也是性能差距的主要來源
- 設計上的結論：**LC 濾波器要照 datasheet 的表選值，並針對目標喇叭阻抗選**，電感要用夠好的

## 散熱：PowerPAD 在頂面

DDV 封裝的散熱墊在**晶片上方**，不是像多數 QFN 那樣在底部。

- 散熱片要壓在 IC 頂面，中間夾導熱墊，用螺絲固定到 PCB 上 → **PCB 上要預留散熱片固定孔**，layout 時要把 IC 周圍的高元件清開
- 300W 級持續輸出會需要不小的散熱片（TPA3255EVM 附的散熱片可當尺寸參考）
- 反過來說，因為底部沒有需要回焊的大散熱墊，這顆其實**可以手焊**（0.5mm 腳距拖焊，要經驗與好的助焊劑）

## 焊接選項

1. **SMT 組裝服務** — 依實際 BOM、封裝庫存、數量與工程費取得報價
2. **手焊拖焊** — 可行（見上節），但 0.5mm 腳距沒經驗容易橋接
3. **TPA3255EVM** — TI 官方評估板可作參考與量測對照；價格待查，自畫設計仍可保留學習價值

建議：PCB 自己畫，SMT 交給 JLCPCB 貼；有預算的話另外買一片 EVM 當對照組。

## 電路架構

```
RCA 輸入 ──→ [輸入耦合與濾波] ──→ [TPA3255] ──→ [LC 輸出濾波 + Zobel] ──→ 喇叭
                                      ↑   ↑
                                   PVDD  頂面散熱片
                                （36–53V）
```

### 1. 輸入級
- 差動輸入，輸入耦合電容隔 DC（值依 datasheet；§7.5 列輸入電阻典型 20kΩ，前端仍須依實際差動接法分析）
- 輸入衰減與前端增益須依訊源最大電平、晶片差動輸入與削波餘裕計算
- 單端 RCA 進來可接 datasheet 的單端接法，或前面加一級單端轉差動

### 2. 輸出 LC 濾波
- Class D 最關鍵的部分，功能是把 PWM 方波濾成音頻
- TPA3255EVM 4Ω 參考值：**L = 10µH、C = 1µF 薄膜**；8Ω 負載照 datasheet 濾波器表調整
- 電感依負載峰值加開關紋波、偏磁後電感量、DCR 與溫升選型；不能以價格或單一電流數字判定
- 輸出加 **Zobel / snubber RC**（datasheet 有值），抑制高頻振鈴
- **Layout 最敏感區域**：IC 輸出到 LC 的走線要短，迴路面積小

### 3. Bootstrap 與去耦
- 每個半橋一顆 **bootstrap 電容 33nF**（0603 / 0805 陶瓷，耐壓 ≥100V）。**不要加大**，datasheet 明講加大會增加峰值電流、有可靠度風險
- PVDD 去耦：每對 PVDD 腳 **1µF / 100V 陶瓷**貼在腳旁；板上大電容依電源阻抗、負載瞬變、紋波與額定電壓選定；取消未經計算的固定容量下限
- 各輔助腳依原廠指定分別去耦，詳見 V0.2 原理圖；不可把所有腳位都套用同一組容量
- 外部 12V：供 VDD 與 GVDD_AB/CD。**DVDD / AVDD 是內部穩壓器輸出，只接規定去耦，不可接 12V 或拿來供外部電路**（§11.1）

### 4. 保護與控制腳位
- RESET、FAULT、CLIP_OTW 拉到控制／高阻抗量測介面，若要 LED 顯示應另外設計驅動
- 開機順序依 datasheet（§11.2–11.3，需同時處理主／輔助電源與 RESET，不以單一延遲代替時序驗證）

## PCB Layout 關鍵注意事項

Class D 的 layout 比 Class AB **敏感得多**：

1. **四層為本案初步選擇** — 保留連續地平面及短回流路徑；EVM 本身採雙層，層數不能取代佈局審查。實際成本待報價
2. **PWM 輸出到 LC 濾波器的走線要短** — 幾百 kHz 的大電流方波，走線就是天線
3. **PVDD 去耦電容直接貼在 IC 腳旁** — 回流路徑越短越好
4. **依原廠佈局管理回流** — 用元件分區控制大電流路徑；不能把「單點接地」當任意切割地平面的規則
5. **輸入訊號遠離 PWM 輸出與電感** — 高頻串擾
6. **散熱片固定孔與淨空** — 頂面散熱片要壓得上去，IC 周圍留空

## 其他專案參考

[Purifi 主力後級](https://github.com/ewinkuo1-sudo/diy-purifi-amplifier) 已獨立管理。可交流計算、KiCad 與量測方法；供電和保護必須按各自拓撲重新驗證。

## 參考資料

- [TPA3255 Datasheet，SLASEA8A](https://www.ti.com/lit/ds/symlink/tpa3255.pdf)（TI，§6、7、10–12；2026-09-10 查閱）
- [TPA3255EVM User's Guide，SLOU441](https://www.ti.com/lit/ug/slou441/slou441.pdf)（TI，含原理圖、BOM 與佈局）
- DIYAudio「TPA3255 - all about DIY」討論串
- 「TPA3255 – Some Insights You Will Not Find In AppNotes」（stromrichter.org，講 pre-filter feedback 與電感選擇）

## 待做

- [ ] 下載 TPA3255 datasheet，標記 Typical Application、濾波器表、layout 章節
- [ ] 確認 JLCPCB 有 TPA3255DDV 的 SMT 庫存
- [ ] 選定電源方案（48V SMPS 最簡單，另需 12V）
- [ ] 選散熱片（照 EVM 尺寸）並確定固定孔位
- [ ] KiCad 建立專案（四層）

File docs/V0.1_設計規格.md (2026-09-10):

# TPA3255 V0.1：第一版設計基線

日期：2026-09-10。本頁保留 V0.1 架構假設；目前已進展至 [V0.2 原理圖草案](V0.2_電路設計.md)，尚無 PCB 或實測。

## 目的與範圍

以 AI 協作完成電路、材料選用、PCB 與機構設計，保留查核、計算及改版過程供課堂展示。本專案完成 TPA3255 立體聲樣機，獨立管理規格、機構與驗證。

期限、預算、焊接設備與量測儀器尚未確定。以下為可修改的工程假設，不表示已核准採購。

| 項目 | V0.1 決定／假設 | 驗證方式 |
|---|---|---|
| 輸出 | 雙聲道 BTL；先以 8Ω 電阻負載測試，再評估 4Ω | 原理圖、假負載量測 |
| 主電源 | 外接 48V DC 為設計候選；初次測試使用符合工作範圍的較低電壓限流電源 | 實測啟動、負載瞬變及掉電 |
| 輔助電源 | 12V 供 VDD/GVDD；初次除錯可獨立供應，整合版再定 DC/DC | 供電順序與紋波量測 |
| 第一階段功率 | 暫定 2×50W / 8Ω、1kHz；此為設計目標，非現有性能 | 記錄雙聲道驅動、失真門檻與持續時間 |
| 輸入 | 優先立體聲 RCA、單端轉差動；XLR 留作後續選項 | 確認 Z10 輸出設定及輸入級 headroom |
| 電路基礎 | TI EVM 為參考，自畫原理圖並記錄修改理由 | 逐網核對，不能只比元件值 |
| PCB | 四層為初步選擇，板形尚未固定 | 疊構、回流、成本與機構共同審查 |
| 機構 | 外接電源；金屬機殼候選、獨立頂面散熱器 | 零件尺寸、固定力、熱與線材空間 |

50W 目標的失真驗收暫以 THD+N ≤1% 為上限；若儀器無法量測，結果只能記為輸出電壓與波形，不能宣稱已通過失真驗收。頻響、噪音、串音與溫升的驗收值需待量測設備盤點後凍結。

## 系統方塊圖

```mermaid
flowchart LR
  RCA[左右 RCA] --> FE[衰減／單端轉差動／耦合]
  FE --> AMP[TPA3255 雙 BTL]
  AMP --> LC[每半橋輸出濾波]
  LC --> LOAD[左右獨立浮接負載]
  DC[外部 DC 電源] --> ENTRY[輸入保險／反接與瞬變處理]
  ENTRY --> AMP
  ENTRY -.整合版待選.-> AUX[12V 輔助電源]
  AUX --> AMP
  CTRL[RESET 與故障狀態] <--> AMP
  AMP --- HEAT[頂面散熱器]
```

BTL 的兩個喇叭端均為輸出端，不能把負端當訊號地。上電檢查單必須指定差動量測方法；不可把接地式示波器地夾接到任一橋式輸出端。

## 設計順序

1. 完成元件腳位／封裝與原廠原理圖的人工逐項核對。
2. 畫 power、input、amplifier/filter、control 四個原理圖區塊。
3. 決定前端衰減與轉差動增益；Z10 最大輸出尚需原廠核對，不能直接當晶片容許輸入。
4. 決定 LC 拓撲和每聲道電感／電容接法，再計算 4Ω、8Ω 響應；不能只用單一 LC 截止頻率代表完整 BTL 電路。
5. 鎖定電感、接頭、電容與散熱器料號，取得尺寸／3D 模型後固定板形。
6. 完成 ERC、PCB 回流與散熱審查、DRC；之後才輸出製造檔。

## 零件選用條件（尚非採購 BOM）

| 區塊 | 已知需求 | 尚待選定 |
|---|---|---|
| 功率 IC | TPA3255 DDV，頂面散熱 | 完整訂購料號、授權供應商、封裝驗證 |
| 前端 | 參考 EVM 的 NE5532 架構 | 供電、偏壓、共模範圍、輸出擺幅、阻容值 |
| LC 電感 | 依峰值電流、紋波、DCR、溫升與偏磁後電感量選 | 材質、型號、尺寸；不能以標稱飽和電流單獨決定 |
| 輸出電容 | 依完整濾波拓撲及工作電壓選 | 容值、耐壓、介質與紋波能力 |
| 去耦／bulk | 依局部迴路與負載需求配置 | MLCC 直流偏壓降額、bulk ESR／紋波、壽命 |
| 12V 支路 | 供應 IC 及選定前端／控制電路 | 最大耗流、DC/DC 輸入瞬變耐受與雜訊 |
| DC 接頭／保險 | 依完整電源預算與湧入電流選 | 額定電流、線徑、熔斷特性及接觸電阻 |
| 散熱器 | 頂面接觸、固定與電氣隔離需求 | 熱阻、導熱介面及實際高度 |

## 3D 第一版

`../mechanical/enclosure-concept.scad` 是參數化空間模型：220×180×70mm 外形與 140×100mm PCB 均為占位假設。模型只有機殼、板區、散熱區；未定接頭開孔、螺柱、通風與加工公差，不能直接加工。塑膠列印可用於尺寸樣件，功率散熱需另行設計。

## 量測與作業證據

依序留下：斷電檢查 → 電源與 RESET → 無訊號假負載 → 小訊號 → 分階段提高輸出 → 溫升與掉電 → 修正。每筆記錄包含設備、接法、負載、電源、輸入、結果、照片及判定。通過假負載測試之前，不接 BE-718。

`../tools/power_budget.py` 可重算理想電氣需求；結果不是 SPICE、不是晶片功率保證，也不包含開關紋波。輸出見 `V0.1_功率估算.md`。

## 參考

- [TI TPA3255 datasheet，SLASEA8A](https://www.ti.com/lit/ds/symlink/tpa3255.pdf)：§6、§7.3–7.5、§10–12。
- [TI TPA3255EVM User’s Guide，SLOU441](https://www.ti.com/lit/ug/slou441/slou441.pdf)：輸入級、原理圖、BOM 與佈局；作為既有參考設計，不照抄全部功能。

查閱日：2026-09-10。所有未附原廠條件的數值均屬本案假設或計算。

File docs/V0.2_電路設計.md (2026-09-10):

# V0.2：第一版電路草案

2026-09-10。這一版將 V0.1 架構落成四頁 KiCad 原理圖，可從 [看圖入口](../electrical/README.md) 閱讀 PNG、SVG 或四頁 PDF。

## 這次完成什麼

- 主晶片 44 個腳位、立體聲 BTL 模式、bootstrap 與 LC 網路。
- 左右 RCA 輸入、兩級反相運放形成差動訊號、耦合與 RF 濾波。
- 外接主電源與 12V、各區去耦、輸入級 VMID 與 3.3V 控制電源。
- 手動 RESET／RUN、故障狀態量測接頭。
- 從實際 KiCad 接線表核對連接，並以其中的阻容數值產生 ngspice 區塊模型。

這四頁是同一個電路的分頁，透過全域網路標籤相連，不表示要做四塊 PCB。尚未安排 PCB、元件 footprint、實際散熱器及機構孔位。

## 輸入級

每聲道使用一顆 NE5532；供電為濾波後的單電源 12V，兩個正輸入均參考約半電源的 VMID。第一級採 24.9kΩ 輸入／10kΩ 回授，第二級採 10kΩ／10kΩ。反相差動輸出送往 TPA3255 的 A/B 或 C/D，配合功率級反相恢復整機極性。

前端理想差動增益約 −0.803V/V；納入 100Ω 串阻與模型中的 20kΩ 輸入負載後，1kHz 約 −0.799V/V。以晶片典型 21.5dB 增益估算，20Vrms 輸出所需 RCA 約 2.106Vrms，尚未含 LC 損耗。這是 50W/8Ω 測試目標的靈敏度估算，不是限功率電路；提高輸入仍可能超過目標或削波。

耦合電容採 10µF 雙極性或薄膜候選，避免在啟停偏壓變動時逕自假設極性。22pF 回授電容以 EVM 為起點；實際 NE5532 在本供電、負載及溫度下的擺幅與穩定性仍需原廠模型／實測確認。VMID 目前為電阻分壓與去耦，雜訊及啟動時間尚未驗證。

## 功率級與供電

U1 為 TPA3255 DDV 44-pin，模式腳接地為雙聲道 BTL。bootstrap 為每半橋 33nF；DVDD、AVDD、VBG 只接各自去耦，不供外部電路。12V 接 GVDD_AB/CD，VDD 經 3.3Ω 支路；局部去耦依功能分開放置。原理圖跨頁只為易讀，PCB 必須把去耦放回對應 IC 腳旁。

主電源暫以外接 48V 規劃，並另接外部 12V。圖中 F1、電源接頭、電容紋波能力、電感電流與功率電阻額定均未完成選型。此版沒有主電源反接、瞬變抑制或湧流控制，首次測試方案須使用限流、具保護的實驗電源；尚不能據此直接下單製板。

12V 輔助電源的初步預算可用晶片典型 30mA + 2×44mA，加兩顆 NE5532 的資料表最大靜態電流 2×16mA，再留訊號及控制餘裕，暫以至少 0.25A 可供應能力篩選。這不是全溫／動態耗流驗收值，也不表示可用線性穩壓直接將 48V 降到 12V。

## 手動控制

U4（TLV76033DBZR）由 12V 產生 3.3V，只供本板的低功耗啟停控制。JP1 的 1–2 為 RUN、2–3 為 RESET；移除跳線時由 4.7kΩ 保持低態。1kΩ 串阻與 4.7kΩ 下拉指定 1% 電阻，並核算原廠最大輸入漏電對高低態的影響。

這是實驗用手動啟停：上電保持 RESET，在主／輔助電源穩定且 PVDD 上電至少 250ms 後才 RUN；關電先 RESET。它沒有自動監測主電源，也不會在意外斷電或 brownout 時保證靜音。自動電源監測與故障關閉是下一階段，喇叭接入前須完成。

J301 供高阻抗量測 FAULT_N、CLIP_OTW_N 與 RESET_N。故障輸出有內部拉高，不直接接 LED，也不接外部 5V 拉高。

## LC 模型的發現

暫用每半橋 10µH、1µF，加原廠範例的小電容及 RC 支路。ngspice 以正負相位的兩個理想源驅動，完整保留 BTL 的兩個電感及兩個對地電容；每顆電感 DCR 暫設 0.05Ω。

8Ω 時 20kHz 約 +0.809dB，相對 1kHz 約抬升 0.915dB；4Ω 時 20kHz 約 −0.613dB。下一步應依實際負載與電感料號比較替代 LC 組合，之後才凍結容值。

輸入模型的兩顆運放是有限增益理想受控源；沒有模擬 NE5532 的實際頻寬、雜訊或削波，也沒有 TPA3255 的 PWM 模型。不能由此推論 THD+N、EMI、保護動作、最大功率或散熱性能。數據與檢查範圍見 [驗證報告](../electrical/validation.md)。

## 原廠依據與版本

| 來源 | 本次用途 |
|---|---|
| [TI TPA3255，SLASEA8A](https://www.ti.com/lit/ds/symlink/tpa3255.pdf) | pp.3–4 腳位；pp.6–8 工作條件、增益／漏電；p.22 參考接法；pp.29–31 電源／啟停；p.33 連續地平面 |
| [TI TPA3255EVM，SLOU441](https://www.ti.com/lit/ug/slou441/slou441.pdf) | p.18 輸入級與偏壓參考；p.19 功率級／去耦參考，移除多模式選擇與 EVM 擴充功能 |
| [TI NE5532，SLOS075K](https://www.ti.com/lit/ds/symlink/ne5532.pdf) | pp.2–4 腳位、供電與電氣條件；EVM 單電源用法不等於全部 ±15V 指標可套用 |
| [TI TLV760，SNVSAV1A](https://www.ti.com/lit/ds/symlink/tlv760.pdf) | pp.3–5 接腳、輸入範圍及電容條件 |

查閱日：2026-09-10。原廠 PDF 留作本機查核，不重新散布整份 PDF；本專案的元件符號為自行建立，物理腳號已對照原廠圖面。BST 腳及同一半橋的重複輸出腳採 passive ERC 類型；每個半橋仍保留一個 output 腳。ERC 不驗證 bootstrap 能量來源，另以接線表檢查電容連到正確半橋。

## 下一步

1. 決定 8Ω 與 4Ω 的頻響目標，調整 LC，選擇能在預設過流門檻下維持所需電感量的實際電感。
2. 加入主電源監測、自動啟停與掉電靜音；目前手動控制保留作除錯選項。
3. 確定電源輸入保護、保險、接頭及額定，完成正式 BOM 與 footprint 核對。
4. 依實際零件及散熱器尺寸重畫板形／機殼，再進入 PCB 佈局。

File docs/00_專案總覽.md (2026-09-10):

# TPA3255 專案總覽

> 從舊雙軌總覽抽出 TPA3255 部分。以下數字保留為歷史草案，與現行規格不一致時，以 [V0.1 設計規格](V0.1_設計規格.md) 及 [電路設計](01_電路設計.md) 的已查核內容為準。價格與比較未於拆分時重新驗證。

用 TI TPA3255 晶片從零設計整塊 D 類放大板。學完整的 Class D PCB 設計流程。

| 指標 | TPA3255 DIY | vs C 298 |
|---|---|---|
| THD+N | ~0.01%（1W）| 差 10–100 倍 |
| SNR | ~105–110dB | 差 10–15dB |
| 功率 | 315W×2 / 4Ω（BTL，10% THD）；175W×2 / 8Ω | 4Ω 功率更大 |
| 回授 | pre-filter（LC 濾波器之前）| C 298 是 post-filter，頻響不受喇叭阻抗影響；TPA3255 會 |
| 效率 | >90% | 同等級 |

**你要畫的 PCB（2 塊）：**
1. **放大板** — TPA3255 + LC 輸出濾波 + 頂面散熱片 + 保護（這是核心）
2. **電源板** — 依本專案重新設計；V0.1 採外接電源構想

**預估成本：**

| 項目 | 估價（NT$）|
|---|---|
| TPA3255 ×1（雙聲道）| $250–400 |
| LC 濾波電感、薄膜電容、MLCC | $300–500 |
| 散熱片 + 導熱墊（IC 頂面 PowerPAD）| $100–300 |
| PCB 製板（四層）| $200–400 |
| 電源（48V SMPS 或變壓器整流）| $500–1,000 |
| 機殼、端子 | $500–1,000 |
| **合計** | **NT$2,000–3,600** |

**完成後用途**：推電腦桌面喇叭或當備機。

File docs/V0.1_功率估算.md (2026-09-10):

# V0.1 功率估算

假設：兩聲道同時正弦輸出、48V 電源、功率級效率 90%、另加 5W 輔助預算。
效率與輔助功耗為估算假設；實際值須量測。

| 每聲道 W | Ω | Vrms | Vpeak | Arms | Apeak | 輸入總 W | 48V 平均 A | 功率級總損耗 W |
|---|---|---|---|---|---|---|---|---|
| 10 | 8 | 8.94 | 12.65 | 1.12 | 1.58 | 27.22 | 0.57 | 2.22 |
| 50 | 8 | 20.00 | 28.28 | 2.50 | 3.54 | 116.11 | 2.42 | 11.11 |
| 100 | 8 | 28.28 | 40.00 | 3.54 | 5.00 | 227.22 | 4.73 | 22.22 |
| 50 | 4 | 14.14 | 20.00 | 3.54 | 5.00 | 116.11 | 2.42 | 11.11 |
| 100 | 4 | 20.00 | 28.28 | 5.00 | 7.07 | 227.22 | 4.73 | 22.22 |

公式：Vrms=√(PR)，Irms=√(P/R)，峰值=RMS×√2；Pin=2P/η+Paux。

50W/8Ω 的初步外部電源容量預留 25%：
145.14W，即 48V 下 3.02A。這是容量篩選起點，不是選定料號。

未含：輸出電感紋波、負載相位、削波餘裕、電源瞬變、開機湧流、散熱器熱阻與環境降額。
所有列皆為需求情境，不代表 V0.1 可達成；不能由本表宣稱 THD+N 或選定保險絲。

重算：在專案根目錄執行 `python3 tools/power_budget.py`。

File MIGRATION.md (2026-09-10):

# 專案來源

2026-09-10 依使用者要求，將雙軌規劃拆為兩個獨立專案。

本專案由 [diy-amplifier 的拆分前版本](https://github.com/ewinkuo1-sudo/diy-amplifier/tree/37fbbb1de3810481597ad3595cc5f0d225e31988) 匯入相關檔案。
新儲存庫從拆分時開始獨立提交；完整舊提交歷史仍可在來源儲存庫查閱。

- 原路線 A → [diy-purifi-amplifier](https://github.com/ewinkuo1-sudo/diy-purifi-amplifier)
- 原路線 B → [diy-tpa3255-amplifier](https://github.com/ewinkuo1-sudo/diy-tpa3255-amplifier)

各自使用 docs/ 放設計文件，mechanical/ 放機構圖面，tools/ 放本專案的計算工具。未有內容的資料夾不預先建立。

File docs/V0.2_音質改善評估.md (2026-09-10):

# V0.2 音質改善評估

2026-09-10。檢視版本：`9357709`。使用者希望聲音更好；本次為設計審查與下一版建議，尚未修改原理圖或驗證改善後的聲音。

建議方向：降低噪聲與失真、讓頻率響應較少受負載影響，並確保音樂峰值與開關機時都能正常工作。可量測的改善是否可聞，仍需實機及音量匹配的比較。

## 目前知道什麼

V0.2 的 ERC 和接線核對已通過，但它們不驗證音質。現有輸入級使用理想運放模型，輸出使用理想源與固定阻值負載，不能拿來宣稱整機 THD+N、底噪、抗干擾或真實喇叭表現。

[已保存的模擬結果](../electrical/validation.md)顯示：8Ω 時 20kHz 相對 1kHz 約抬升 0.915dB；4Ω 時約下降 0.398dB。這表示輸出濾波具有負載相關性。不能據此判定聽起來刺耳，也不能把固定 8Ω 模型當作實際 BE-718 的阻抗曲線。

## 改善優先順序

| 優先項目 | 現況 | 下一版要做的事 | 對使用者的意義 |
|---|---|---|---|
| 1. 輸出回授與濾波 | 沒有濾波後回授；LC 高頻響應隨負載改變 | 評估 PFFB，再一起決定 LC、阻尼及輸入增益 | 目標是讓送到喇叭的訊號更忠實，降低濾波元件帶來的誤差 |
| 2. 輸出電感實際選型 | L1–L4 只有 10µH 占位，電流額定、料號未定 | 比較電感量隨電流的變化、損耗、溫升與保護門檻 | 避免音量變大時因元件非線性增加失真 |
| 3. 供電、接地與 PCB | 尚無 PCB；前端與功率驅動共用外部 12V | 規劃低噪聲前端供電、完整地平面、功率電流回路及輸入屏蔽 | 降低嘶聲、嗡聲及開關干擾的風險 |
| 4. 輸入與 DAC 匹配 | RCA、NE5532、單電源 VMID；真實模型未驗證 | 計算全鏈路噪聲與擺幅；評估真正的 XLR 平衡接收 | 降低外部干擾，保留音樂峰值的餘裕 |
| 5. 自動啟停與故障處理 | JP1 手動啟停 | 監測主／輔助電源並自動延遲開聲、掉電靜音 | 改善日常使用，減少開關機爆音；進入喇叭測試前完成 |

以上是設計工作優先級。供電監測與保護是接喇叭前的必要工作，不因排列在第五項而延後到實機使用之後。

## 為何先評估 PFFB

PFFB（濾波後回授）把輸出濾波後的訊號送回放大器修正。TI 說明此方法可降低 LC 元件造成的失真；在本案中，也值得用來評估減少負載造成的頻響差異。[TI SLAA788A，§2–3、§11–16、附錄 E](https://www.ti.com/lit/an/slaa788a/slaa788a.pdf)

採用前需同時重算增益、阻尼與穩定性，涵蓋空載、不同負載、接近削波及元件容差；現有區塊 AC 模型不足以驗證整個回授迴路。TI 範例的 TPA3255 功率級增益由 21.5dB 降至 15.93dB，因此不能直接加上回授而保留所有輸入級參數。[同文件 Table 2 與穩定性章節](https://www.ti.com/lit/an/slaa788a/slaa788a.pdf)

PFFB 是下一版候選架構。原廠範例的測試結果不能直接當作本板的失真或穩定性結果。

## 值得投入的元件與佈局工作

電感不只看標稱 µH 或最大 A：必須看工作電流下的線性、開關損耗與熱。TI 的比較顯示，同一標稱電感值仍可能帶來不同失真，因此選型應依資料與量測。[TI：Selecting the Right Inductor for Ultra-low Distortion Class-D Audio Amplifiers](https://www.ti.com/lit/pdf/ssztbo2)

NE5532 目前沒有證據顯示是本案的主要瓶頸，TI EVM 也使用它。應先檢查本案單 12V 供電下的工作範圍、VMID 雜訊、阻值造成的噪聲和實際輸出擺幅，再決定是否更換。[TI TPA3255EVM](https://www.ti.com/tool/TPA3255EVM)

PCB 佈局要讓小訊號遠離開關節點，縮小大電流回路，將去耦放在對應腳旁，並維持完整地平面；功能分區不等於任意切割地平面。供電與散熱也要在雙聲道負載下核對。[TI TPA3255 資料表，§10、§11.4、§12](https://www.ti.com/lit/ds/symlink/tpa3255.pdf)

## 配合現有 DAC

依 Z10 官方規格，RCA 為 2.5Vrms、XLR 為 5Vrms，條件為 0dBFS。現版估算約 2.106Vrms RCA 可達 50W/8Ω，尚未含 LC 損耗；50W 是測試目標，不是硬性功率上限。[Eversolo DAC-Z10 規格](https://www.eversolo.com/Product/index/model/DAC-Z10/target/XIffD4sPvkjeq7k9e%5Bld%5D3ulg%3D%3D.html)

真正的平衡接收是可評估的抗干擾方案，需包含阻抗匹配、共模工作範圍及接地設計。僅換 XLR 插座不會自動得到平衡接收的效果；原本已安靜的短線連接也未必有可聞改善。是否增加此功能，應和 PFFB 後的整機增益、成本及接頭空間一起評估。

## 下一版如何判斷有沒有進步

- 比較相同輸出電平下的頻響，涵蓋 4Ω、8Ω，以及有來源或實測依據的喇叭等效負載。
- 量測輸入短路與接上 DAC 時的底噪，記錄量測頻寬與加權方式。
- 量測失真隨功率及頻率的變化，涵蓋小音量和接近預期最大輸出；同時檢查雙聲道供電與溫升。
- 檢查回授穩定性與開關機瞬態；儀器和假負載符合 BTL 量測需求後才進行實機測試。
- 實機比較時對齊音量，避免把比較大聲誤認為比較好聽。

這些是待執行的驗證項目，並非已達成的性能規格。目前尚未選定量測設備、確定聽音所需峰值功率或建立 BE-718 實際阻抗模型。

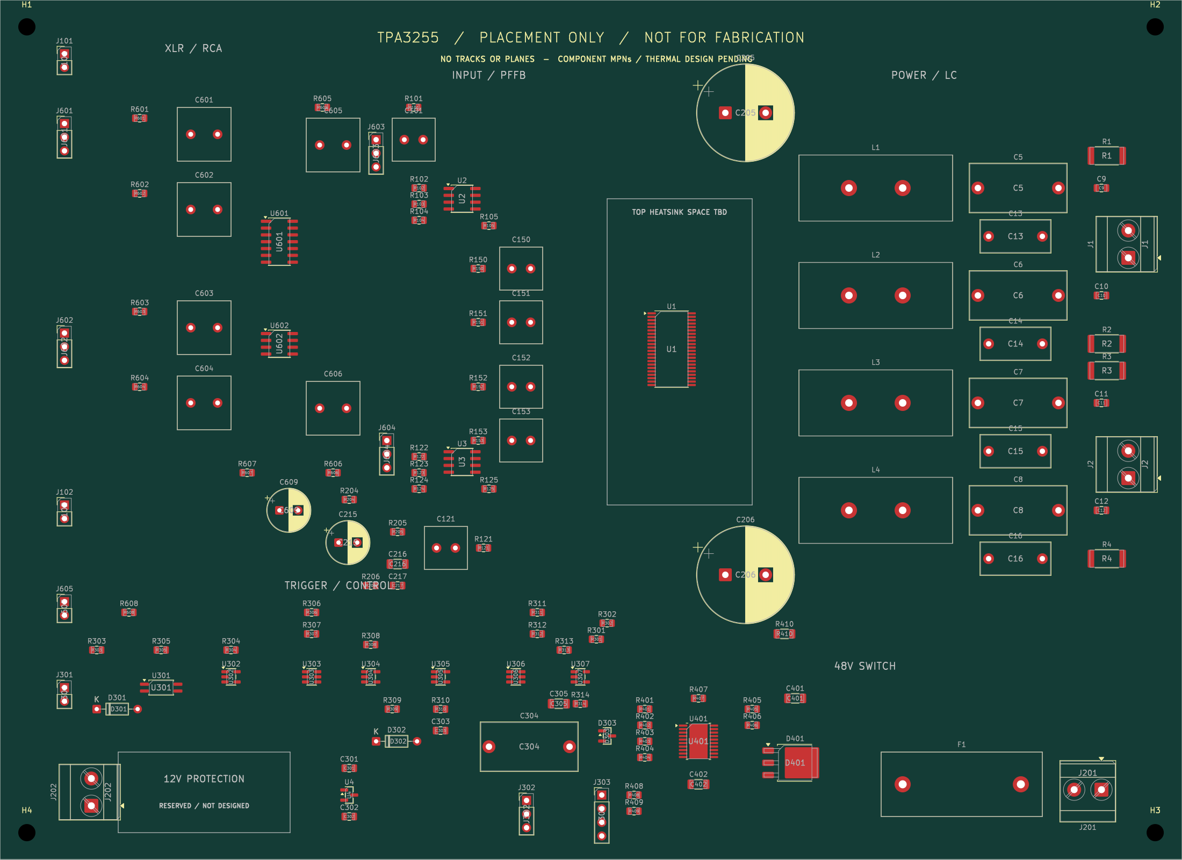
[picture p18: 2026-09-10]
electrical/pcb-draft/preview/top.png

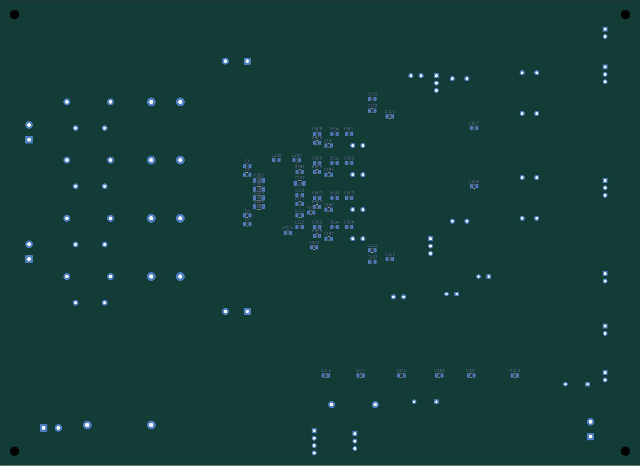
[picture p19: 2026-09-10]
electrical/pcb-draft/preview/bottom.png

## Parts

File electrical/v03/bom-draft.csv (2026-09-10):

Refs | Value | Footprint | Qty | DNP
C1-C4 | 33n / 100V |  | 4
C5-C8 | 1u / 100V film |  | 4
C9-C12 | 1n / 100V |  | 4
C13-C16 | 220n / 100V film |  | 4
C101,C121 | 10u / 25V BP |  | 2
C102,C103,C122,C123 | 330p / C0G |  | 4
C150-C153 | 10u / 50V BP |  | 4
C154-C157 | 100p / C0G |  | 4
C201-C204,C401 | 1u / 100V X7R |  | 5
C205,C206 | 470u / 80V |  | 2
C207 | 10u / 25V |  | 1
C208-C210,C218,C219,C607,C608 | 100n / 25V |  | 7
C211-C213,C302 | 1u / 16V |  | 4
C214 | 47n / 25V |  | 1
C215,C609 | 100u / 25V |  | 2
C216 | 10u / 16V |  | 1
C217,C310-C315 | 100n / 16V |  | 7
C301 | 1u / 25V |  | 1
C303 | 1n / C0G |  | 1
C304 | 4.7u / 16V film 5% |  | 1
C305 | 180n / 5% C0G |  | 1
C402 | 2.2u / 10V X7R |  | 1
C501-C508 | 220p / 100V C0G |  | 8
C601-C606 | 47u / 25V BP |  | 6
D301,D302 | 1N4148 |  | 2
D303 | BAT54 |  | 1
D401 | STPS5H100B |  | 1
F1 | T5A / >=80VDC TBD MPN |  | 1
J1 | LEFT BTL |  | 1
J2 | RIGHT BTL |  | 1
J101 | L RCA |  | 1
J102 | R RCA |  | 1
J201 | INTERNAL 48V INPUT |  | 1
J202 | INTERNAL 12V INPUT |  | 1
J301 | TRIGGER TIP / SLEEVE |  | 1
J302 | AUTO / COMMON / ON |  | 1
J303 | STATUS |  | 1
J601 | L XLR FEMALE |  | 1
J602 | R XLR FEMALE |  | 1
J603 | L RCA / COM / XLR |  | 1
J604 | R RCA / COM / XLR |  | 1
J605 | CHASSIS BOND |  | 1
L1-L4 | 10u / MA5172-AE |  | 4
R1-R4 | 1 / 1W |  | 4
R101,R121,R305,R605,R606 | 100k |  | 5
R102,R122 | 11.5k / 0.1% |  | 2
R103-R105,R123-R125,R307,R312,R402,R404,R406,R505-R508 | 10k / 0.1% |  | 15
R150-R153 | 2.7k / 0.1% |  | 4
R201 | 3.3 |  | 1
R202,R304 | 22k / 1% |  | 2
R203 | 30k / 1% |  | 1
R204,R607 | 10 |  | 2
R205,R206 | 10k / 1% |  | 2
R301 | 1k / 1% |  | 1
R302 | 4.7k / 1% |  | 1
R303 | 6.8k / 1% |  | 1
R306 | 267k / 0.1% |  | 1
R308,R313,R314 | 10k |  | 3
R309,R408 | 1k |  | 2
R310 | 100k / 1% |  | 1
R311 | 1M / 0.1% |  | 1
R401 | 324k / 0.1% |  | 1
R403 | 412k / 0.1% |  | 1
R405 | 316k / 0.1% |  | 1
R407 | 4.02k / 1% |  | 1
R409 | 22k |  | 1
R410 | 22k / 0.5W |  | 1
R501-R504 | 33k / 0.1% |  | 4
R601-R604 | 47 / 0.1% |  | 4
R608 | 0 / SINGLE BOND |  | 1
U1 | TPA3255DDV |  | 1
U2,U3,U602 | NE5532 |  | 3
U4 | TLV76033DBZR |  | 1
U301 | VOS618A-3T |  | 1
U302 | SN74LVC1G14DBVR |  | 1
U303,U306 | TPS3808G01DBVR |  | 2
U304,U305,U307 | SN74LVC1G17DBVR |  | 3
U401 | TPS26631PWPR |  | 1
U601 | INA2137UA |  | 1

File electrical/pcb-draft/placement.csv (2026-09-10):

reference | value | footprint | status | x_mm | y_mm | rotation_deg | side | footprint_sha256
C1 | 33n / 100V | Capacitor_SMD:C_0805_2012Metric | provisional | 135 | 57 | 0 | B | 62775a51fe74ba7f1b572de327bdbd3fc92582721b2abcaa47787865590d89cb
C2 | 33n / 100V | Capacitor_SMD:C_0805_2012Metric | provisional | 135 | 60 | 0 | B | 62775a51fe74ba7f1b572de327bdbd3fc92582721b2abcaa47787865590d89cb
C3 | 33n / 100V | Capacitor_SMD:C_0805_2012Metric | provisional | 135 | 74 | 0 | B | 62775a51fe74ba7f1b572de327bdbd3fc92582721b2abcaa47787865590d89cb
C4 | 33n / 100V | Capacitor_SMD:C_0805_2012Metric | provisional | 135 | 77 | 0 | B | 62775a51fe74ba7f1b572de327bdbd3fc92582721b2abcaa47787865590d89cb
C5 | 1u / 100V film | Capacitor_THT:C_Rect_L18.0mm_W9.0mm_P15.00mm_FKS3_FKP3 | provisional | 182 | 35 | 0 | F | 2cefe1b7b4b50cd43199e4cdc2ca843393db0095876f3f26deb29bdeb93dac9e
C6 | 1u / 100V film | Capacitor_THT:C_Rect_L18.0mm_W9.0mm_P15.00mm_FKS3_FKP3 | provisional | 182 | 55 | 0 | F | 2cefe1b7b4b50cd43199e4cdc2ca843393db0095876f3f26deb29bdeb93dac9e
C7 | 1u / 100V film | Capacitor_THT:C_Rect_L18.0mm_W9.0mm_P15.00mm_FKS3_FKP3 | provisional | 182 | 75 | 0 | F | 2cefe1b7b4b50cd43199e4cdc2ca843393db0095876f3f26deb29bdeb93dac9e
C8 | 1u / 100V film | Capacitor_THT:C_Rect_L18.0mm_W9.0mm_P15.00mm_FKS3_FKP3 | provisional | 182 | 95 | 0 | F | 2cefe1b7b4b50cd43199e4cdc2ca843393db0095876f3f26deb29bdeb93dac9e
C9 | 1n / 100V | Capacitor_SMD:C_0805_2012Metric | provisional | 205 | 35 | 0 | F | 62775a51fe74ba7f1b572de327bdbd3fc92582721b2abcaa47787865590d89cb
C10 | 1n / 100V | Capacitor_SMD:C_0805_2012Metric | provisional | 205 | 55 | 0 | F | 62775a51fe74ba7f1b572de327bdbd3fc92582721b2abcaa47787865590d89cb
C11 | 1n / 100V | Capacitor_SMD:C_0805_2012Metric | provisional | 205 | 75 | 0 | F | 62775a51fe74ba7f1b572de327bdbd3fc92582721b2abcaa47787865590d89cb
C12 | 1n / 100V | Capacitor_SMD:C_0805_2012Metric | provisional | 205 | 95 | 0 | F | 62775a51fe74ba7f1b572de327bdbd3fc92582721b2abcaa47787865590d89cb
C13 | 220n / 100V film | Capacitor_THT:C_Rect_L13.0mm_W6.0mm_P10.00mm_FKS3_FKP3_MKS4 | provisional | 184 | 44 | 0 | F | 7672e33a5ccc2c55a4569535706789413885ef9c8dfcc8f6919c5708c810ec06
C14 | 220n / 100V film | Capacitor_THT:C_Rect_L13.0mm_W6.0mm_P10.00mm_FKS3_FKP3_MKS4 | provisional | 184 | 64 | 0 | F | 7672e33a5ccc2c55a4569535706789413885ef9c8dfcc8f6919c5708c810ec06
C15 | 220n / 100V film | Capacitor_THT:C_Rect_L13.0mm_W6.0mm_P10.00mm_FKS3_FKP3_MKS4 | provisional | 184 | 84 | 0 | F | 7672e33a5ccc2c55a4569535706789413885ef9c8dfcc8f6919c5708c810ec06
C16 | 220n / 100V film | Capacitor_THT:C_Rect_L13.0mm_W6.0mm_P10.00mm_FKS3_FKP3_MKS4 | provisional | 184 | 104 | 0 | F | 7672e33a5ccc2c55a4569535706789413885ef9c8dfcc8f6919c5708c810ec06
C101 | 10u / 25V BP | Placement:BP_Cap_D8_P3.5 | provisional | 77 | 26 | 0 | F | c07037b337b8a5c206b1e8cac7ab5ff0bc5a8583b61bd0324506813ea5b541d2
C102 | 330p / C0G | Capacitor_SMD:C_0805_2012Metric | provisional | 92 | 34 | 0 | B | 62775a51fe74ba7f1b572de327bdbd3fc92582721b2abcaa47787865590d89cb
C103 | 330p / C0G | Capacitor_SMD:C_0805_2012Metric | provisional | 92 | 38 | 0 | B | 62775a51fe74ba7f1b572de327bdbd3fc92582721b2abcaa47787865590d89cb
C121 | 10u / 25V BP | Placement:BP_Cap_D8_P3.5 | provisional | 83 | 102 | 0 | F | c07037b337b8a5c206b1e8cac7ab5ff0bc5a8583b61bd0324506813ea5b541d2
C122 | 330p / C0G | Capacitor_SMD:C_0805_2012Metric | provisional | 92 | 86 | 0 | B | 62775a51fe74ba7f1b572de327bdbd3fc92582721b2abcaa47787865590d89cb
C123 | 330p / C0G | Capacitor_SMD:C_0805_2012Metric | provisional | 92 | 90 | 0 | B | 62775a51fe74ba7f1b572de327bdbd3fc92582721b2abcaa47787865590d89cb
C150 | 10u / 50V BP | Placement:BP_Cap_D8_P3.5 | provisional | 97 | 50 | 0 | F | c07037b337b8a5c206b1e8cac7ab5ff0bc5a8583b61bd0324506813ea5b541d2
C151 | 10u / 50V BP | Placement:BP_Cap_D8_P3.5 | provisional | 97 | 60 | 0 | F | c07037b337b8a5c206b1e8cac7ab5ff0bc5a8583b61bd0324506813ea5b541d2
C152 | 10u / 50V BP | Placement:BP_Cap_D8_P3.5 | provisional | 97 | 72 | 0 | F | c07037b337b8a5c206b1e8cac7ab5ff0bc5a8583b61bd0324506813ea5b541d2
C153 | 10u / 50V BP | Placement:BP_Cap_D8_P3.5 | provisional | 97 | 82 | 0 | F | c07037b337b8a5c206b1e8cac7ab5ff0bc5a8583b61bd0324506813ea5b541d2
C154 | 100p / C0G | Capacitor_SMD:C_0805_2012Metric | provisional | 107 | 50 | 0 | B | 62775a51fe74ba7f1b572de327bdbd3fc92582721b2abcaa47787865590d89cb
C155 | 100p / C0G | Capacitor_SMD:C_0805_2012Metric | provisional | 107 | 60 | 0 | B | 62775a51fe74ba7f1b572de327bdbd3fc92582721b2abcaa47787865590d89cb
C156 | 100p / C0G | Capacitor_SMD:C_0805_2012Metric | provisional | 107 | 72 | 0 | B | 62775a51fe74ba7f1b572de327bdbd3fc92582721b2abcaa47787865590d89cb
C157 | 100p / C0G | Capacitor_SMD:C_0805_2012Metric | provisional | 107 | 82 | 0 | B | 62775a51fe74ba7f1b572de327bdbd3fc92582721b2abcaa47787865590d89cb
C201 | 1u / 100V X7R | Capacitor_SMD:C_1206_3216Metric | provisional | 131 | 62 | 0 | B | b2e4a08e3aaf40bc587090190c0e3969e962d7ae962c172cce0581ae8327651c
C202 | 1u / 100V X7R | Capacitor_SMD:C_1206_3216Metric | provisional | 131 | 65 | 0 | B | b2e4a08e3aaf40bc587090190c0e3969e962d7ae962c172cce0581ae8327651c
C203 | 1u / 100V X7R | Capacitor_SMD:C_1206_3216Metric | provisional | 131 | 68 | 0 | B | b2e4a08e3aaf40bc587090190c0e3969e962d7ae962c172cce0581ae8327651c
C204 | 1u / 100V X7R | Capacitor_SMD:C_1206_3216Metric | provisional | 131 | 71 | 0 | B | b2e4a08e3aaf40bc587090190c0e3969e962d7ae962c172cce0581ae8327651c
C205 | 470u / 80V | Capacitor_THT:CP_Radial_D18.0mm_P7.50mm | provisional | 135 | 21 | 0 | F | 1c99021c3a0ed41751554408bb417ab0045a43bdf8744bcb186a90710d994559
C206 | 470u / 80V | Capacitor_THT:CP_Radial_D18.0mm_P7.50mm | provisional | 135 | 107 | 0 | F | 1c99021c3a0ed41751554408bb417ab0045a43bdf8744bcb186a90710d994559
C207 | 10u / 25V | Capacitor_SMD:C_1206_3216Metric | provisional | 117 | 63 | 0 | B | b2e4a08e3aaf40bc587090190c0e3969e962d7ae962c172cce0581ae8327651c
C208 | 100n / 25V | Capacitor_SMD:C_0805_2012Metric | provisional | 118 | 55 | 0 | B | 62775a51fe74ba7f1b572de327bdbd3fc92582721b2abcaa47787865590d89cb
C209 | 100n / 25V | Capacitor_SMD:C_0805_2012Metric | provisional | 125 | 55 | 0 | B | 62775a51fe74ba7f1b572de327bdbd3fc92582721b2abcaa47787865590d89cb
C210 | 100n / 25V | Capacitor_SMD:C_0805_2012Metric | provisional | 117 | 74 | 0 | B | 62775a51fe74ba7f1b572de327bdbd3fc92582721b2abcaa47787865590d89cb
C211 | 1u / 16V | Capacitor_SMD:C_0805_2012Metric | provisional | 117 | 67 | 0 | B | 62775a51fe74ba7f1b572de327bdbd3fc92582721b2abcaa47787865590d89cb
C212 | 1u / 16V | Capacitor_SMD:C_0805_2012Metric | provisional | 117 | 70 | 0 | B | 62775a51fe74ba7f1b572de327bdbd3fc92582721b2abcaa47787865590d89cb
C213 | 1u / 16V | Capacitor_SMD:C_0805_2012Metric | provisional | 117 | 78 | 0 | B | 62775a51fe74ba7f1b572de327bdbd3fc92582721b2abcaa47787865590d89cb
C214 | 47n / 25V | Capacitor_SMD:C_0805_2012Metric | provisional | 121 | 80 | 0 | B | 62775a51fe74ba7f1b572de327bdbd3fc92582721b2abcaa47787865590d89cb
C215 | 100u / 25V | Capacitor_THT:CP_Radial_D8.0mm_P3.50mm | provisional | 63 | 101 | 0 | F | e7256cc327aa5d1bc5410a487248fa9b5e3d25153b2315201d5da5108cb49580
C216 | 10u / 16V | Capacitor_SMD:C_1206_3216Metric | provisional | 74 | 105 | 0 | F | b2e4a08e3aaf40bc587090190c0e3969e962d7ae962c172cce0581ae8327651c
C217 | 100n / 16V | Capacitor_SMD:C_0805_2012Metric | provisional | 74 | 109 | 0 | F | 62775a51fe74ba7f1b572de327bdbd3fc92582721b2abcaa47787865590d89cb
C218 | 100n / 25V | Capacitor_SMD:C_0805_2012Metric | provisional | 86 | 40 | 0 | B | 62775a51fe74ba7f1b572de327bdbd3fc92582721b2abcaa47787865590d89cb
C219 | 100n / 25V | Capacitor_SMD:C_0805_2012Metric | provisional | 86 | 89 | 0 | B | 62775a51fe74ba7f1b572de327bdbd3fc92582721b2abcaa47787865590d89cb
C301 | 1u / 25V | Capacitor_SMD:C_0805_2012Metric | provisional | 65 | 143 | 0 | F | 62775a51fe74ba7f1b572de327bdbd3fc92582721b2abcaa47787865590d89cb
C302 | 1u / 16V | Capacitor_SMD:C_0805_2012Metric | provisional | 65 | 152 | 0 | F | 62775a51fe74ba7f1b572de327bdbd3fc92582721b2abcaa47787865590d89cb
C303 | 1n / C0G | Capacitor_SMD:C_0805_2012Metric | provisional | 82 | 136 | 0 | F | 62775a51fe74ba7f1b572de327bdbd3fc92582721b2abcaa47787865590d89cb
C304 | 4.7u / 16V film 5% | Capacitor_THT:C_Rect_L18.0mm_W9.0mm_P15.00mm_FKS3_FKP3 | provisional | 91 | 139 | 0 | F | 2cefe1b7b4b50cd43199e4cdc2ca843393db0095876f3f26deb29bdeb93dac9e
C305 | 180n / 5% C0G | Capacitor_SMD:C_1206_3216Metric | provisional | 104 | 131 | 0 | F | b2e4a08e3aaf40bc587090190c0e3969e962d7ae962c172cce0581ae8327651c
C310 | 100n / 16V | Capacitor_SMD:C_0805_2012Metric | provisional | 43 | 129 | 0 | B | 62775a51fe74ba7f1b572de327bdbd3fc92582721b2abcaa47787865590d89cb
C311 | 100n / 16V | Capacitor_SMD:C_0805_2012Metric | provisional | 58 | 129 | 0 | B | 62775a51fe74ba7f1b572de327bdbd3fc92582721b2abcaa47787865590d89cb
C312 | 100n / 16V | Capacitor_SMD:C_0805_2012Metric | provisional | 69 | 129 | 0 | B | 62775a51fe74ba7f1b572de327bdbd3fc92582721b2abcaa47787865590d89cb
C313 | 100n / 16V | Capacitor_SMD:C_0805_2012Metric | provisional | 82 | 129 | 0 | B | 62775a51fe74ba7f1b572de327bdbd3fc92582721b2abcaa47787865590d89cb
C314 | 100n / 16V | Capacitor_SMD:C_0805_2012Metric | provisional | 96 | 129 | 0 | B | 62775a51fe74ba7f1b572de327bdbd3fc92582721b2abcaa47787865590d89cb
C315 | 100n / 16V | Capacitor_SMD:C_0805_2012Metric | provisional | 108 | 129 | 0 | B | 62775a51fe74ba7f1b572de327bdbd3fc92582721b2abcaa47787865590d89cb
C401 | 1u / 100V X7R | Capacitor_SMD:C_1206_3216Metric | provisional | 148 | 130 | 0 | F | b2e4a08e3aaf40bc587090190c0e3969e962d7ae962c172cce0581ae8327651c
C402 | 2.2u / 10V X7R | Capacitor_SMD:C_1206_3216Metric | provisional | 130 | 146 | 0 | F | b2e4a08e3aaf40bc587090190c0e3969e962d7ae962c172cce0581ae8327651c
C501 | 220p / 100V C0G | Capacitor_SMD:C_0805_2012Metric | provisional | 100 | 46 | 0 | B | 62775a51fe74ba7f1b572de327bdbd3fc92582721b2abcaa47787865590d89cb
C502 | 220p / 100V C0G | Capacitor_SMD:C_0805_2012Metric | provisional | 100 | 56 | 0 | B | 62775a51fe74ba7f1b572de327bdbd3fc92582721b2abcaa47787865590d89cb
C503 | 220p / 100V C0G | Capacitor_SMD:C_0805_2012Metric | provisional | 100 | 68 | 0 | B | 62775a51fe74ba7f1b572de327bdbd3fc92582721b2abcaa47787865590d89cb
C504 | 220p / 100V C0G | Capacitor_SMD:C_0805_2012Metric | provisional | 100 | 78 | 0 | B | 62775a51fe74ba7f1b572de327bdbd3fc92582721b2abcaa47787865590d89cb
C505 | 220p / 100V C0G | Capacitor_SMD:C_0805_2012Metric | provisional | 111 | 46 | 0 | B | 62775a51fe74ba7f1b572de327bdbd3fc92582721b2abcaa47787865590d89cb
C506 | 220p / 100V C0G | Capacitor_SMD:C_0805_2012Metric | provisional | 111 | 56 | 0 | B | 62775a51fe74ba7f1b572de327bdbd3fc92582721b2abcaa47787865590d89cb
C507 | 220p / 100V C0G | Capacitor_SMD:C_0805_2012Metric | provisional | 111 | 68 | 0 | B | 62775a51fe74ba7f1b572de327bdbd3fc92582721b2abcaa47787865590d89cb
C508 | 220p / 100V C0G | Capacitor_SMD:C_0805_2012Metric | provisional | 111 | 78 | 0 | B | 62775a51fe74ba7f1b572de327bdbd3fc92582721b2abcaa47787865590d89cb
C601 | 47u / 25V BP | Placement:BP_Cap_D10_P5 | provisional | 38 | 25 | 0 | F | 02b646bc071b9e1bd998976ccb4a00782db2eb447e36fab5d66330906a4a3986
C602 | 47u / 25V BP | Placement:BP_Cap_D10_P5 | provisional | 38 | 39 | 0 | F | 02b646bc071b9e1bd998976ccb4a00782db2eb447e36fab5d66330906a4a3986
C603 | 47u / 25V BP | Placement:BP_Cap_D10_P5 | provisional | 38 | 61 | 0 | F | 02b646bc071b9e1bd998976ccb4a00782db2eb447e36fab5d66330906a4a3986
C604 | 47u / 25V BP | Placement:BP_Cap_D10_P5 | provisional | 38 | 75 | 0 | F | 02b646bc071b9e1bd998976ccb4a00782db2eb447e36fab5d66330906a4a3986
C605 | 47u / 25V BP | Placement:BP_Cap_D10_P5 | provisional | 62 | 27 | 0 | F | 02b646bc071b9e1bd998976ccb4a00782db2eb447e36fab5d66330906a4a3986
C606 | 47u / 25V BP | Placement:BP_Cap_D10_P5 | provisional | 62 | 76 | 0 | F | 02b646bc071b9e1bd998976ccb4a00782db2eb447e36fab5d66330906a4a3986
C607 | 100n / 25V | Capacitor_SMD:C_0805_2012Metric | provisional | 57 | 44 | 0 | B | 62775a51fe74ba7f1b572de327bdbd3fc92582721b2abcaa47787865590d89cb
C608 | 100n / 25V | Capacitor_SMD:C_0805_2012Metric | provisional | 57 | 64 | 0 | B | 62775a51fe74ba7f1b572de327bdbd3fc92582721b2abcaa47787865590d89cb
C609 | 100u / 25V | Capacitor_THT:CP_Radial_D8.0mm_P3.50mm | provisional | 52 | 95 | 0 | F | e7256cc327aa5d1bc5410a487248fa9b5e3d25153b2315201d5da5108cb49580
D301 | 1N4148 | Placement:DO35_A1_K2_P7.62 | provisional | 18 | 132 | 0 | F | 1bb330a37c34172e1b41f82d967462f5f3cef8e02a81710f4c141939324e7364
D302 | 1N4148 | Placement:DO35_A1_K2_P7.62 | provisional | 70 | 138 | 0 | F | 1bb330a37c34172e1b41f82d967462f5f3cef8e02a81710f4c141939324e7364
D303 | BAT54 | Package_TO_SOT_SMD:SOT-23 | package_candidate | 113 | 137 | 0 | F | 0d88c86c1b6d8c1aae4aa8c09386264c089d4451a128b6ccd63ed253f4300b15
D401 | STPS5H100B | Package_TO_SOT_SMD:TO-252-3_TabPin2 | package_candidate | 148 | 142 | 0 | F | b38d2dae2942b02a83304e3c2d2ee8aff35f7b8fa6457b2f9ac3fdea91984dea
F1 | T5A / >=80VDC TBD MPN | Placement:Fuse_P22_Provisional | provisional | 179 | 146 | 0 | F | 6d549ec40e0b7eca4435a8b638907d48bddc54eb3ae967934af63880b9e11ecc
J1 | LEFT BTL | TerminalBlock_Phoenix:TerminalBlock_Phoenix_MKDS-3-2-5.08_1x02_P5.08mm_Horizontal | provisional | 210 | 48 | 90 | F | e3b06eda34b6c80468fef8b320e1710a8d768cdb078443257022da58112e71fe
J2 | RIGHT BTL | TerminalBlock_Phoenix:TerminalBlock_Phoenix_MKDS-3-2-5.08_1x02_P5.08mm_Horizontal | provisional | 210 | 89 | 90 | F | e3b06eda34b6c80468fef8b320e1710a8d768cdb078443257022da58112e71fe
J101 | L RCA | Connector_PinHeader_2.54mm:PinHeader_1x02_P2.54mm_Vertical | provisional | 12 | 10 | 0 | F | 5301303268f72ba9cc94b7fdbac355951933e6854272ce8d300b679b86b5d45d
J102 | R RCA | Connector_PinHeader_2.54mm:PinHeader_1x02_P2.54mm_Vertical | provisional | 12 | 94 | 0 | F | 5301303268f72ba9cc94b7fdbac355951933e6854272ce8d300b679b86b5d45d
J201 | INTERNAL 48V INPUT | TerminalBlock_Phoenix:TerminalBlock_Phoenix_MKDS-3-2-5.08_1x02_P5.08mm_Horizontal | provisional | 205 | 147 | 180 | F | e3b06eda34b6c80468fef8b320e1710a8d768cdb078443257022da58112e71fe
J202 | INTERNAL 12V INPUT | TerminalBlock_Phoenix:TerminalBlock_Phoenix_MKDS-3-2-5.08_1x02_P5.08mm_Horizontal | provisional | 17 | 150 | 90 | F | e3b06eda34b6c80468fef8b320e1710a8d768cdb078443257022da58112e71fe
J301 | TRIGGER TIP / SLEEVE | Connector_PinHeader_2.54mm:PinHeader_1x02_P2.54mm_Vertical | provisional | 12 | 128 | 0 | F | 5301303268f72ba9cc94b7fdbac355951933e6854272ce8d300b679b86b5d45d
J302 | AUTO / COMMON / ON | Connector_PinHeader_2.54mm:PinHeader_1x03_P2.54mm_Vertical | provisional | 98 | 149 | 0 | F | e5f24b6fea852f86171042806da48490229c9c8025b6d266b8cad6485b26e79f
J303 | STATUS | Connector_PinHeader_2.54mm:PinHeader_1x04_P2.54mm_Vertical | provisional | 112 | 148 | 0 | F | 571d2d16b49795f8f9a91f96cc83fd2adf49890cd66c377189c44204ebd03c29
J601 | L XLR FEMALE | Connector_PinHeader_2.54mm:PinHeader_1x03_P2.54mm_Vertical | provisional | 12 | 23 | 0 | F | e5f24b6fea852f86171042806da48490229c9c8025b6d266b8cad6485b26e79f
J602 | R XLR FEMALE | Connector_PinHeader_2.54mm:PinHeader_1x03_P2.54mm_Vertical | provisional | 12 | 62 | 0 | F | e5f24b6fea852f86171042806da48490229c9c8025b6d266b8cad6485b26e79f
J603 | L RCA / COM / XLR | Connector_PinHeader_2.54mm:PinHeader_1x03_P2.54mm_Vertical | provisional | 70 | 26 | 0 | F | e5f24b6fea852f86171042806da48490229c9c8025b6d266b8cad6485b26e79f
J604 | R RCA / COM / XLR | Connector_PinHeader_2.54mm:PinHeader_1x03_P2.54mm_Vertical | provisional | 72 | 82 | 0 | F | e5f24b6fea852f86171042806da48490229c9c8025b6d266b8cad6485b26e79f
J605 | CHASSIS BOND | Connector_PinHeader_2.54mm:PinHeader_1x02_P2.54mm_Vertical | provisional | 12 | 112 | 0 | F | 5301303268f72ba9cc94b7fdbac355951933e6854272ce8d300b679b86b5d45d
L1 | 10u / MA5172-AE | Placement:MA5172_AE_Provisional | provisional | 163 | 35 | 0 | F | 0ec708b51ea6f765428eedcae2f9a843a1a39e19a95a74f7cf50fea7ee9290ad
L2 | 10u / MA5172-AE | Placement:MA5172_AE_Provisional | provisional | 163 | 55 | 0 | F | 0ec708b51ea6f765428eedcae2f9a843a1a39e19a95a74f7cf50fea7ee9290ad
L3 | 10u / MA5172-AE | Placement:MA5172_AE_Provisional | provisional | 163 | 75 | 0 | F | 0ec708b51ea6f765428eedcae2f9a843a1a39e19a95a74f7cf50fea7ee9290ad
L4 | 10u / MA5172-AE | Placement:MA5172_AE_Provisional | provisional | 163 | 95 | 0 | F | 0ec708b51ea6f765428eedcae2f9a843a1a39e19a95a74f7cf50fea7ee9290ad
R1 | 1 / 1W | Resistor_SMD:R_2512_6332Metric | provisional | 206 | 29 | 0 | F | abab4bf8eeb3ed03061d8eeb56b542cdac074ce8a0ace0f9b06e933c0b48f297
R2 | 1 / 1W | Resistor_SMD:R_2512_6332Metric | provisional | 206 | 64 | 0 | F | abab4bf8eeb3ed03061d8eeb56b542cdac074ce8a0ace0f9b06e933c0b48f297
R3 | 1 / 1W | Resistor_SMD:R_2512_6332Metric | provisional | 206 | 69 | 0 | F | abab4bf8eeb3ed03061d8eeb56b542cdac074ce8a0ace0f9b06e933c0b48f297
R4 | 1 / 1W | Resistor_SMD:R_2512_6332Metric | provisional | 206 | 104 | 0 | F | abab4bf8eeb3ed03061d8eeb56b542cdac074ce8a0ace0f9b06e933c0b48f297
R101 | 100k | Resistor_SMD:R_0805_2012Metric | provisional | 77 | 20 | 0 | F | f050b6a50cc7e6f86291fb7aa8f87b0d02255e21cfbddf291cdccc87e5889794
R102 | 11.5k / 0.1% | Resistor_SMD:R_0805_2012Metric | provisional | 78 | 35 | 0 | F | f050b6a50cc7e6f86291fb7aa8f87b0d02255e21cfbddf291cdccc87e5889794
R103 | 10k / 0.1% | Resistor_SMD:R_0805_2012Metric | provisional | 78 | 38 | 0 | F | f050b6a50cc7e6f86291fb7aa8f87b0d02255e21cfbddf291cdccc87e5889794
R104 | 10k / 0.1% | Resistor_SMD:R_0805_2012Metric | provisional | 78 | 41 | 0 | F | f050b6a50cc7e6f86291fb7aa8f87b0d02255e21cfbddf291cdccc87e5889794
R105 | 10k / 0.1% | Resistor_SMD:R_0805_2012Metric | provisional | 91 | 42 | 0 | F | f050b6a50cc7e6f86291fb7aa8f87b0d02255e21cfbddf291cdccc87e5889794
R121 | 100k | Resistor_SMD:R_0805_2012Metric | provisional | 90 | 102 | 0 | F | f050b6a50cc7e6f86291fb7aa8f87b0d02255e21cfbddf291cdccc87e5889794
R122 | 11.5k / 0.1% | Resistor_SMD:R_0805_2012Metric | provisional | 78 | 85 | 0 | F | f050b6a50cc7e6f86291fb7aa8f87b0d02255e21cfbddf291cdccc87e5889794
R123 | 10k / 0.1% | Resistor_SMD:R_0805_2012Metric | provisional | 78 | 88 | 0 | F | f050b6a50cc7e6f86291fb7aa8f87b0d02255e21cfbddf291cdccc87e5889794
R124 | 10k / 0.1% | Resistor_SMD:R_0805_2012Metric | provisional | 78 | 91 | 0 | F | f050b6a50cc7e6f86291fb7aa8f87b0d02255e21cfbddf291cdccc87e5889794
R125 | 10k / 0.1% | Resistor_SMD:R_0805_2012Metric | provisional | 91 | 91 | 0 | F | f050b6a50cc7e6f86291fb7aa8f87b0d02255e21cfbddf291cdccc87e5889794
R150 | 2.7k / 0.1% | Resistor_SMD:R_0805_2012Metric | provisional | 89 | 50 | 0 | F | f050b6a50cc7e6f86291fb7aa8f87b0d02255e21cfbddf291cdccc87e5889794
R151 | 2.7k / 0.1% | Resistor_SMD:R_0805_2012Metric | provisional | 89 | 60 | 0 | F | f050b6a50cc7e6f86291fb7aa8f87b0d02255e21cfbddf291cdccc87e5889794
R152 | 2.7k / 0.1% | Resistor_SMD:R_0805_2012Metric | provisional | 89 | 72 | 0 | F | f050b6a50cc7e6f86291fb7aa8f87b0d02255e21cfbddf291cdccc87e5889794
R153 | 2.7k / 0.1% | Resistor_SMD:R_0805_2012Metric | provisional | 89 | 82 | 0 | F | f050b6a50cc7e6f86291fb7aa8f87b0d02255e21cfbddf291cdccc87e5889794
R201 | 3.3 | Resistor_SMD:R_0805_2012Metric | provisional | 117 | 59 | 0 | B | f050b6a50cc7e6f86291fb7aa8f87b0d02255e21cfbddf291cdccc87e5889794
R202 | 22k / 1% | Resistor_SMD:R_0805_2012Metric | provisional | 113 | 73 | 0 | B | f050b6a50cc7e6f86291fb7aa8f87b0d02255e21cfbddf291cdccc87e5889794
R203 | 30k / 1% | Resistor_SMD:R_0805_2012Metric | provisional | 112 | 85 | 0 | B | f050b6a50cc7e6f86291fb7aa8f87b0d02255e21cfbddf291cdccc87e5889794
R204 | 10 | Resistor_SMD:R_0805_2012Metric | provisional | 65 | 93 | 0 | F | f050b6a50cc7e6f86291fb7aa8f87b0d02255e21cfbddf291cdccc87e5889794
R205 | 10k / 1% | Resistor_SMD:R_0805_2012Metric | provisional | 74 | 99 | 0 | F | f050b6a50cc7e6f86291fb7aa8f87b0d02255e21cfbddf291cdccc87e5889794
R206 | 10k / 1% | Resistor_SMD:R_0805_2012Metric | provisional | 69 | 109 | 0 | F | f050b6a50cc7e6f86291fb7aa8f87b0d02255e21cfbddf291cdccc87e5889794
R301 | 1k / 1% | Resistor_SMD:R_0805_2012Metric | provisional | 111 | 119 | 0 | F | f050b6a50cc7e6f86291fb7aa8f87b0d02255e21cfbddf291cdccc87e5889794
R302 | 4.7k / 1% | Resistor_SMD:R_0805_2012Metric | provisional | 113 | 116 | 0 | F | f050b6a50cc7e6f86291fb7aa8f87b0d02255e21cfbddf291cdccc87e5889794
R303 | 6.8k / 1% | Resistor_SMD:R_0805_2012Metric | provisional | 18 | 121 | 0 | F | f050b6a50cc7e6f86291fb7aa8f87b0d02255e21cfbddf291cdccc87e5889794
R304 | 22k / 1% | Resistor_SMD:R_0805_2012Metric | provisional | 43 | 121 | 0 | F | f050b6a50cc7e6f86291fb7aa8f87b0d02255e21cfbddf291cdccc87e5889794
R305 | 100k | Resistor_SMD:R_0805_2012Metric | provisional | 30 | 121 | 0 | F | f050b6a50cc7e6f86291fb7aa8f87b0d02255e21cfbddf291cdccc87e5889794
R306 | 267k / 0.1% | Resistor_SMD:R_0805_2012Metric | provisional | 58 | 114 | 0 | F | f050b6a50cc7e6f86291fb7aa8f87b0d02255e21cfbddf291cdccc87e5889794
R307 | 10k / 0.1% | Resistor_SMD:R_0805_2012Metric | provisional | 58 | 118 | 0 | F | f050b6a50cc7e6f86291fb7aa8f87b0d02255e21cfbddf291cdccc87e5889794
R308 | 10k | Resistor_SMD:R_0805_2012Metric | provisional | 69 | 120 | 0 | F | f050b6a50cc7e6f86291fb7aa8f87b0d02255e21cfbddf291cdccc87e5889794
R309 | 1k | Resistor_SMD:R_0805_2012Metric | provisional | 73 | 132 | 0 | F | f050b6a50cc7e6f86291fb7aa8f87b0d02255e21cfbddf291cdccc87e5889794
R310 | 100k / 1% | Resistor_SMD:R_0805_2012Metric | provisional | 82 | 132 | 0 | F | f050b6a50cc7e6f86291fb7aa8f87b0d02255e21cfbddf291cdccc87e5889794
R311 | 1M / 0.1% | Resistor_SMD:R_0805_2012Metric | provisional | 100 | 114 | 0 | F | f050b6a50cc7e6f86291fb7aa8f87b0d02255e21cfbddf291cdccc87e5889794
R312 | 10k / 0.1% | Resistor_SMD:R_0805_2012Metric | provisional | 100 | 118 | 0 | F | f050b6a50cc7e6f86291fb7aa8f87b0d02255e21cfbddf291cdccc87e5889794
R313 | 10k | Resistor_SMD:R_0805_2012Metric | provisional | 105 | 121 | 0 | F | f050b6a50cc7e6f86291fb7aa8f87b0d02255e21cfbddf291cdccc87e5889794
R314 | 10k | Resistor_SMD:R_0805_2012Metric | provisional | 108 | 131 | 0 | F | f050b6a50cc7e6f86291fb7aa8f87b0d02255e21cfbddf291cdccc87e5889794
R401 | 324k / 0.1% | Resistor_SMD:R_0805_2012Metric | provisional | 120 | 132 | 0 | F | f050b6a50cc7e6f86291fb7aa8f87b0d02255e21cfbddf291cdccc87e5889794
R402 | 10k / 0.1% | Resistor_SMD:R_0805_2012Metric | provisional | 120 | 135 | 0 | F | f050b6a50cc7e6f86291fb7aa8f87b0d02255e21cfbddf291cdccc87e5889794
R403 | 412k / 0.1% | Resistor_SMD:R_0805_2012Metric | provisional | 120 | 138 | 0 | F | f050b6a50cc7e6f86291fb7aa8f87b0d02255e21cfbddf291cdccc87e5889794
R404 | 10k / 0.1% | Resistor_SMD:R_0805_2012Metric | provisional | 120 | 141 | 0 | F | f050b6a50cc7e6f86291fb7aa8f87b0d02255e21cfbddf291cdccc87e5889794
R405 | 316k / 0.1% | Resistor_SMD:R_0805_2012Metric | provisional | 140 | 132 | 0 | F | f050b6a50cc7e6f86291fb7aa8f87b0d02255e21cfbddf291cdccc87e5889794
R406 | 10k / 0.1% | Resistor_SMD:R_0805_2012Metric | provisional | 140 | 135 | 0 | F | f050b6a50cc7e6f86291fb7aa8f87b0d02255e21cfbddf291cdccc87e5889794
R407 | 4.02k / 1% | Resistor_SMD:R_0805_2012Metric | provisional | 130 | 130 | 0 | F | f050b6a50cc7e6f86291fb7aa8f87b0d02255e21cfbddf291cdccc87e5889794
R408 | 1k | Resistor_SMD:R_0805_2012Metric | provisional | 118 | 148 | 0 | F | f050b6a50cc7e6f86291fb7aa8f87b0d02255e21cfbddf291cdccc87e5889794
R409 | 22k | Resistor_SMD:R_0805_2012Metric | provisional | 118 | 151 | 0 | F | f050b6a50cc7e6f86291fb7aa8f87b0d02255e21cfbddf291cdccc87e5889794
R410 | 22k / 0.5W | Resistor_SMD:R_1206_3216Metric | provisional | 146 | 118 | 0 | F | c7320668dc81bbb954cb4f15e4e7a766c120059343d43551468c8f7ccc8fde37
R501 | 33k / 0.1% | Resistor_SMD:R_0805_2012Metric | provisional | 105 | 46 | 0 | B | f050b6a50cc7e6f86291fb7aa8f87b0d02255e21cfbddf291cdccc87e5889794
R502 | 33k / 0.1% | Resistor_SMD:R_0805_2012Metric | provisional | 105 | 56 | 0 | B | f050b6a50cc7e6f86291fb7aa8f87b0d02255e21cfbddf291cdccc87e5889794
R503 | 33k / 0.1% | Resistor_SMD:R_0805_2012Metric | provisional | 105 | 68 | 0 | B | f050b6a50cc7e6f86291fb7aa8f87b0d02255e21cfbddf291cdccc87e5889794
R504 | 33k / 0.1% | Resistor_SMD:R_0805_2012Metric | provisional | 105 | 78 | 0 | B | f050b6a50cc7e6f86291fb7aa8f87b0d02255e21cfbddf291cdccc87e5889794
R505 | 10k / 0.1% | Resistor_SMD:R_0805_2012Metric | provisional | 111 | 49 | 0 | B | f050b6a50cc7e6f86291fb7aa8f87b0d02255e21cfbddf291cdccc87e5889794
R506 | 10k / 0.1% | Resistor_SMD:R_0805_2012Metric | provisional | 111 | 59 | 0 | B | f050b6a50cc7e6f86291fb7aa8f87b0d02255e21cfbddf291cdccc87e5889794
R507 | 10k / 0.1% | Resistor_SMD:R_0805_2012Metric | provisional | 111 | 71 | 0 | B | f050b6a50cc7e6f86291fb7aa8f87b0d02255e21cfbddf291cdccc87e5889794
R508 | 10k / 0.1% | Resistor_SMD:R_0805_2012Metric | provisional | 111 | 81 | 0 | B | f050b6a50cc7e6f86291fb7aa8f87b0d02255e21cfbddf291cdccc87e5889794
R601 | 47 / 0.1% | Resistor_SMD:R_0805_2012Metric | provisional | 26 | 22 | 0 | F | f050b6a50cc7e6f86291fb7aa8f87b0d02255e21cfbddf291cdccc87e5889794
R602 | 47 / 0.1% | Resistor_SMD:R_0805_2012Metric | provisional | 26 | 36 | 0 | F | f050b6a50cc7e6f86291fb7aa8f87b0d02255e21cfbddf291cdccc87e5889794
R603 | 47 / 0.1% | Resistor_SMD:R_0805_2012Metric | provisional | 26 | 58 | 0 | F | f050b6a50cc7e6f86291fb7aa8f87b0d02255e21cfbddf291cdccc87e5889794
R604 | 47 / 0.1% | Resistor_SMD:R_0805_2012Metric | provisional | 26 | 72 | 0 | F | f050b6a50cc7e6f86291fb7aa8f87b0d02255e21cfbddf291cdccc87e5889794
R605 | 100k | Resistor_SMD:R_0805_2012Metric | provisional | 60 | 20 | 0 | F | f050b6a50cc7e6f86291fb7aa8f87b0d02255e21cfbddf291cdccc87e5889794
R606 | 100k | Resistor_SMD:R_0805_2012Metric | provisional | 62 | 88 | 0 | F | f050b6a50cc7e6f86291fb7aa8f87b0d02255e21cfbddf291cdccc87e5889794
R607 | 10 | Resistor_SMD:R_0805_2012Metric | provisional | 46 | 88 | 0 | F | f050b6a50cc7e6f86291fb7aa8f87b0d02255e21cfbddf291cdccc87e5889794
R608 | 0 / SINGLE BOND | Resistor_SMD:R_0805_2012Metric | provisional | 24 | 114 | 0 | F | f050b6a50cc7e6f86291fb7aa8f87b0d02255e21cfbddf291cdccc87e5889794
U1 | TPA3255DDV | Package_SO:HTSSOP-44_6.1x14mm_P0.635mm_TopEP4.14x7.01mm | package_candidate | 125 | 65 | 0 | F | 746a6d46abcdfd145204cb2f76c7c14d46cb92f94355839ec1af7ab3b8e244f1
U2 | NE5532 | Package_SO:SOIC-8_3.9x4.9mm_P1.27mm | package_candidate | 86 | 37 | 0 | F | 074ecb2092b24fa4b4b9cdd7c926fc587b0d7d6d21e7341e57935fd42d36894f
U3 | NE5532 | Package_SO:SOIC-8_3.9x4.9mm_P1.27mm | package_candidate | 86 | 86 | 0 | F | 074ecb2092b24fa4b4b9cdd7c926fc587b0d7d6d21e7341e57935fd42d36894f
U4 | TLV76033DBZR | Package_TO_SOT_SMD:SOT-23 | package_candidate | 65 | 148 | 0 | F | 0d88c86c1b6d8c1aae4aa8c09386264c089d4451a128b6ccd63ed253f4300b15
U301 | VOS618A-3T | Package_SO:SSOP-4_4.4x2.6mm_P1.27mm | package_candidate | 30 | 128 | 0 | F | 4c0e3e53aec80c878a32659b8c4f3d0ba3b3ccc572e75f069da44de6d1038daa
U302 | SN74LVC1G14DBVR | Package_TO_SOT_SMD:SOT-23-5 | package_candidate | 43 | 126 | 0 | F | 455a3f7c3e5eb5b8847eaa5df23e18651e78ab9f75afd09a0883758a0d901761
U303 | TPS3808G01DBVR | Package_TO_SOT_SMD:SOT-23-6 | package_candidate | 58 | 126 | 0 | F | f341c73aac9dcb553456f68bf3fee3d26eb14acf6d8a1cae82b50418fe1d71ca
U304 | SN74LVC1G17DBVR | Package_TO_SOT_SMD:SOT-23-5 | package_candidate | 69 | 126 | 0 | F | 455a3f7c3e5eb5b8847eaa5df23e18651e78ab9f75afd09a0883758a0d901761
U305 | SN74LVC1G17DBVR | Package_TO_SOT_SMD:SOT-23-5 | package_candidate | 82 | 126 | 0 | F | 455a3f7c3e5eb5b8847eaa5df23e18651e78ab9f75afd09a0883758a0d901761
U306 | TPS3808G01DBVR | Package_TO_SOT_SMD:SOT-23-6 | package_candidate | 96 | 126 | 0 | F | f341c73aac9dcb553456f68bf3fee3d26eb14acf6d8a1cae82b50418fe1d71ca
U307 | SN74LVC1G17DBVR | Package_TO_SOT_SMD:SOT-23-5 | package_candidate | 108 | 126 | 0 | F | 455a3f7c3e5eb5b8847eaa5df23e18651e78ab9f75afd09a0883758a0d901761
U401 | TPS26631PWPR | Package_SO:HTSSOP-20-1EP_4.4x6.5mm_P0.65mm_EP3.4x6.5mm_Mask2.96x2.96mm | package_candidate | 130 | 138 | 0 | F | f6663eda6995b7db057e9f9caf6362d259dab41b27ca79d3305dc4842b84ea0a
U601 | INA2137UA | Package_SO:SOIC-14_3.9x8.7mm_P1.27mm | package_candidate | 52 | 45 | 0 | F | a885b619b22880c9559522d2bf865b059d80453b95a98defc9e6ceef284da1fc
U602 | NE5532 | Package_SO:SOIC-8_3.9x4.9mm_P1.27mm | package_candidate | 52 | 64 | 0 | F | 074ecb2092b24fa4b4b9cdd7c926fc587b0d7d6d21e7341e57935fd42d36894f

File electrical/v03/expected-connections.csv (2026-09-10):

reference | pin | function | net | sheet
U1 | 1 | GVDD_AB | +12V | tpa3255-v03
U1 | 2 | VDD | VDD_FILTERED | tpa3255-v03
U1 | 3 | M1 | GND | tpa3255-v03
U1 | 4 | M2 | GND | tpa3255-v03
U1 | 5 | INPUT_A | INPUT_A | tpa3255-v03
U1 | 6 | INPUT_B | INPUT_B | tpa3255-v03
U1 | 7 | OC_ADJ | OC_ADJ | tpa3255-v03
U1 | 8 | FREQ_ADJ | FREQ_ADJ | tpa3255-v03
U1 | 9 | OSC_IOM | NC | tpa3255-v03
U1 | 10 | OSC_IOP | NC | tpa3255-v03
U1 | 11 | DVDD | DVDD | tpa3255-v03
U1 | 12 | GND | GND | tpa3255-v03
U1 | 13 | GND | GND | tpa3255-v03
U1 | 14 | AVDD | AVDD | tpa3255-v03
U1 | 15 | C_START | C_START | tpa3255-v03
U1 | 16 | INPUT_C | INPUT_C | tpa3255-v03
U1 | 17 | INPUT_D | INPUT_D | tpa3255-v03
U1 | 18 | RESET_N | RESET_N | tpa3255-v03
U1 | 19 | FAULT_N | FAULT_N | tpa3255-v03
U1 | 20 | VBG | VBG | tpa3255-v03
U1 | 21 | CLIP_OTW_N | CLIP_OTW_N | tpa3255-v03
U1 | 22 | GVDD_CD | +12V | tpa3255-v03
U1 | 23 | BST_D | BST_D | tpa3255-v03
U1 | 24 | BST_C | BST_C | tpa3255-v03
U1 | 25 | GND | GND | tpa3255-v03
U1 | 26 | GND | GND | tpa3255-v03
U1 | 27 | OUT_D | OUT_D | tpa3255-v03
U1 | 28 | OUT_D | OUT_D | tpa3255-v03
U1 | 29 | PVDD_CD | PVDD | tpa3255-v03
U1 | 30 | PVDD_CD | PVDD | tpa3255-v03
U1 | 31 | PVDD_CD | PVDD | tpa3255-v03
U1 | 32 | OUT_C | OUT_C | tpa3255-v03
U1 | 33 | GND | GND | tpa3255-v03
U1 | 34 | GND | GND | tpa3255-v03
U1 | 35 | OUT_B | OUT_B | tpa3255-v03
U1 | 36 | PVDD_AB | PVDD | tpa3255-v03
U1 | 37 | PVDD_AB | PVDD | tpa3255-v03
U1 | 38 | PVDD_AB | PVDD | tpa3255-v03
U1 | 39 | OUT_A | OUT_A | tpa3255-v03
U1 | 40 | OUT_A | OUT_A | tpa3255-v03
U1 | 41 | GND | GND | tpa3255-v03
U1 | 42 | GND | GND | tpa3255-v03
U1 | 43 | BST_B | BST_B | tpa3255-v03
U1 | 44 | BST_A | BST_A | tpa3255-v03
C1 | 1 | ~ | BST_A | tpa3255-v03
C1 | 2 | ~ | OUT_A | tpa3255-v03
L1 | 1 | ~ | OUT_A | tpa3255-v03
L1 | 2 | ~ | SPK_A | tpa3255-v03
C5 | 1 | ~ | SPK_A | tpa3255-v03
C5 | 2 | ~ | GND | tpa3255-v03
C9 | 1 | ~ | SPK_A | tpa3255-v03
C9 | 2 | ~ | GND | tpa3255-v03
C13 | 1 | ~ | SPK_A | tpa3255-v03
C13 | 2 | ~ | Z_A | tpa3255-v03
R1 | 1 | ~ | Z_A | tpa3255-v03
R1 | 2 | ~ | GND | tpa3255-v03
C2 | 1 | ~ | BST_B | tpa3255-v03
C2 | 2 | ~ | OUT_B | tpa3255-v03
L2 | 1 | ~ | OUT_B | tpa3255-v03
L2 | 2 | ~ | SPK_B | tpa3255-v03
C6 | 1 | ~ | SPK_B | tpa3255-v03
C6 | 2 | ~ | GND | tpa3255-v03
C10 | 1 | ~ | SPK_B | tpa3255-v03
C10 | 2 | ~ | GND | tpa3255-v03
C14 | 1 | ~ | SPK_B | tpa3255-v03
C14 | 2 | ~ | Z_B | tpa3255-v03
R2 | 1 | ~ | Z_B | tpa3255-v03
R2 | 2 | ~ | GND | tpa3255-v03
C3 | 1 | ~ | BST_C | tpa3255-v03
C3 | 2 | ~ | OUT_C | tpa3255-v03
L3 | 1 | ~ | OUT_C | tpa3255-v03
L3 | 2 | ~ | SPK_C | tpa3255-v03
C7 | 1 | ~ | SPK_C | tpa3255-v03
C7 | 2 | ~ | GND | tpa3255-v03
C11 | 1 | ~ | SPK_C | tpa3255-v03
C11 | 2 | ~ | GND | tpa3255-v03
C15 | 1 | ~ | SPK_C | tpa3255-v03
C15 | 2 | ~ | Z_C | tpa3255-v03
R3 | 1 | ~ | Z_C | tpa3255-v03
R3 | 2 | ~ | GND | tpa3255-v03
C4 | 1 | ~ | BST_D | tpa3255-v03
C4 | 2 | ~ | OUT_D | tpa3255-v03
L4 | 1 | ~ | OUT_D | tpa3255-v03
L4 | 2 | ~ | SPK_D | tpa3255-v03
C8 | 1 | ~ | SPK_D | tpa3255-v03
C8 | 2 | ~ | GND | tpa3255-v03
C12 | 1 | ~ | SPK_D | tpa3255-v03
C12 | 2 | ~ | GND | tpa3255-v03
C16 | 1 | ~ | SPK_D | tpa3255-v03
C16 | 2 | ~ | Z_D | tpa3255-v03
R4 | 1 | ~ | Z_D | tpa3255-v03
R4 | 2 | ~ | GND | tpa3255-v03
J1 | 1 | 1 | SPK_A | tpa3255-v03
J1 | 2 | 2 | SPK_B | tpa3255-v03
J2 | 1 | 1 | SPK_C | tpa3255-v03
J2 | 2 | 2 | SPK_D | tpa3255-v03
J101 | 1 | 1 | L_RCA | input
J101 | 2 | 2 | GND | input
R101 | 1 | ~ | L_RCA | input
R101 | 2 | ~ | GND | input
C101 | 1 | ~ | L_SELECTED | input
C101 | 2 | ~ | L_AC | input
R102 | 1 | ~ | L_AC | input
R102 | 2 | ~ | L_INV1 | input
U2 | 3 | + | VMID | input
U2 | 2 | - | L_INV1 | input
U2 | 1 | OUT | L_NEG | input
R103 | 1 | ~ | L_INV1 | input
R103 | 2 | ~ | L_NEG | input
C102 | 1 | ~ | L_INV1 | input
C102 | 2 | ~ | L_NEG | input
R104 | 1 | ~ | L_NEG | input
R104 | 2 | ~ | L_INV2 | input
U2 | 5 | + | VMID | input
U2 | 6 | - | L_INV2 | input
U2 | 7 | OUT | L_POS | input
R105 | 1 | ~ | L_INV2 | input
R105 | 2 | ~ | L_POS | input
C103 | 1 | ~ | L_INV2 | input
C103 | 2 | ~ | L_POS | input
J102 | 1 | 1 | R_RCA | input
J102 | 2 | 2 | GND | input
R121 | 1 | ~ | R_RCA | input
R121 | 2 | ~ | GND | input
C121 | 1 | ~ | R_SELECTED | input
C121 | 2 | ~ | R_AC | input
R122 | 1 | ~ | R_AC | input
R122 | 2 | ~ | R_INV1 | input
U3 | 3 | + | VMID | input
U3 | 2 | - | R_INV1 | input
U3 | 1 | OUT | R_NEG | input
R123 | 1 | ~ | R_INV1 | input
R123 | 2 | ~ | R_NEG | input
C122 | 1 | ~ | R_INV1 | input
C122 | 2 | ~ | R_NEG | input
R124 | 1 | ~ | R_NEG | input
R124 | 2 | ~ | R_INV2 | input
U3 | 5 | + | VMID | input
U3 | 6 | - | R_INV2 | input
U3 | 7 | OUT | R_POS | input
R125 | 1 | ~ | R_INV2 | input
R125 | 2 | ~ | R_POS | input
C123 | 1 | ~ | R_INV2 | input
C123 | 2 | ~ | R_POS | input
R150 | 1 | ~ | L_NEG | input
R150 | 2 | ~ | SUM_A | input
C150 | 1 | ~ | SUM_A | input
C150 | 2 | ~ | INPUT_A | input
C154 | 1 | ~ | INPUT_A | input
C154 | 2 | ~ | GND | input
R151 | 1 | ~ | L_POS | input
R151 | 2 | ~ | SUM_B | input
C151 | 1 | ~ | SUM_B | input
C151 | 2 | ~ | INPUT_B | input
C155 | 1 | ~ | INPUT_B | input
C155 | 2 | ~ | GND | input
R152 | 1 | ~ | R_NEG | input
R152 | 2 | ~ | SUM_C | input
C152 | 1 | ~ | SUM_C | input
C152 | 2 | ~ | INPUT_C | input
C156 | 1 | ~ | INPUT_C | input
C156 | 2 | ~ | GND | input
R153 | 1 | ~ | R_POS | input
R153 | 2 | ~ | SUM_D | input
C153 | 1 | ~ | SUM_D | input
C153 | 2 | ~ | INPUT_D | input
C157 | 1 | ~ | INPUT_D | input
C157 | 2 | ~ | GND | input
J202 | 1 | 1 | +12V | power-control
J202 | 2 | 2 | GND | power-control
C201 | 1 | ~ | PVDD | power-control
C201 | 2 | ~ | GND | power-control
C202 | 1 | ~ | PVDD | power-control
C202 | 2 | ~ | GND | power-control
C203 | 1 | ~ | PVDD | power-control
C203 | 2 | ~ | GND | power-control
C204 | 1 | ~ | PVDD | power-control
C204 | 2 | ~ | GND | power-control
C205 | 1 | ~ | PVDD | power-control
C205 | 2 | ~ | GND | power-control
C206 | 1 | ~ | PVDD | power-control
C206 | 2 | ~ | GND | power-control
R201 | 1 | ~ | +12V | power-control
R201 | 2 | ~ | VDD_FILTERED | power-control
C207 | 1 | ~ | VDD_FILTERED | power-control
C207 | 2 | ~ | GND | power-control
C208 | 1 | ~ | VDD_FILTERED | power-control
C208 | 2 | ~ | GND | power-control
C209 | 1 | ~ | +12V | power-control
C209 | 2 | ~ | GND | power-control
C210 | 1 | ~ | +12V | power-control
C210 | 2 | ~ | GND | power-control
C211 | 1 | ~ | DVDD | power-control
C211 | 2 | ~ | GND | power-control
C212 | 1 | ~ | AVDD | power-control
C212 | 2 | ~ | GND | power-control
C213 | 1 | ~ | VBG | power-control
C213 | 2 | ~ | GND | power-control
C214 | 1 | ~ | C_START | power-control
C214 | 2 | ~ | GND | power-control
R202 | 1 | ~ | OC_ADJ | power-control
R202 | 2 | ~ | GND | power-control
R203 | 1 | ~ | FREQ_ADJ | power-control
R203 | 2 | ~ | GND | power-control
R204 | 1 | ~ | +12V | power-control
R204 | 2 | ~ | +12V_AUDIO | power-control
C215 | 1 | ~ | +12V_AUDIO | power-control
C215 | 2 | ~ | GND | power-control
R205 | 1 | ~ | +12V_AUDIO | power-control
R205 | 2 | ~ | VMID | power-control
R206 | 1 | ~ | VMID | power-control
R206 | 2 | ~ | GND | power-control
C216 | 1 | ~ | VMID | power-control
C216 | 2 | ~ | GND | power-control
C217 | 1 | ~ | VMID | power-control
C217 | 2 | ~ | GND | power-control
U2 | 8 | V+ | +12V_AUDIO | power-control
U2 | 4 | V- | GND | power-control
C218 | 1 | ~ | +12V_AUDIO | power-control
C218 | 2 | ~ | GND | power-control
U3 | 8 | V+ | +12V_AUDIO | power-control
U3 | 4 | V- | GND | power-control
C219 | 1 | ~ | +12V_AUDIO | power-control
C219 | 2 | ~ | GND | power-control
R501 | 1 | ~ | SUM_A | feedback
R501 | 2 | ~ | SPK_A | feedback
C501 | 1 | ~ | SUM_A | feedback
C501 | 2 | ~ | FB_MID_A | feedback
C505 | 1 | ~ | FB_MID_A | feedback
C505 | 2 | ~ | SPK_A | feedback
R505 | 1 | ~ | FB_MID_A | feedback
R505 | 2 | ~ | GND | feedback
R502 | 1 | ~ | SUM_B | feedback
R502 | 2 | ~ | SPK_B | feedback
C502 | 1 | ~ | SUM_B | feedback
C502 | 2 | ~ | FB_MID_B | feedback
C506 | 1 | ~ | FB_MID_B | feedback
C506 | 2 | ~ | SPK_B | feedback
R506 | 1 | ~ | FB_MID_B | feedback
R506 | 2 | ~ | GND | feedback
R503 | 1 | ~ | SUM_C | feedback
R503 | 2 | ~ | SPK_C | feedback
C503 | 1 | ~ | SUM_C | feedback
C503 | 2 | ~ | FB_MID_C | feedback
C507 | 1 | ~ | FB_MID_C | feedback
C507 | 2 | ~ | SPK_C | feedback
R507 | 1 | ~ | FB_MID_C | feedback
R507 | 2 | ~ | GND | feedback
R504 | 1 | ~ | SUM_D | feedback
R504 | 2 | ~ | SPK_D | feedback
C504 | 1 | ~ | SUM_D | feedback
C504 | 2 | ~ | FB_MID_D | feedback
C508 | 1 | ~ | FB_MID_D | feedback
C508 | 2 | ~ | SPK_D | feedback
R508 | 1 | ~ | FB_MID_D | feedback
R508 | 2 | ~ | GND | feedback
J301 | 1 | 1 | TRIG_TIP | trigger
J301 | 2 | 2 | TRIG_RETURN | trigger
R303 | 1 | ~ | TRIG_TIP | trigger
R303 | 2 | ~ | TRIG_LED | trigger
U301 | 1 | A | TRIG_LED | trigger
U301 | 2 | K | TRIG_RETURN | trigger
U301 | 4 | C | TRIG_N | trigger
U301 | 3 | E | GND | trigger
D301 | 1 | A | TRIG_RETURN | trigger
D301 | 2 | K | TRIG_LED | trigger
R304 | 1 | ~ | +3V3_CTRL | trigger
R304 | 2 | ~ | TRIG_N | trigger
U302 | 1 | NC | NC | trigger
U302 | 2 | A | TRIG_N | trigger
U302 | 3 | GND | GND | trigger
U302 | 5 | VCC | +3V3_CTRL | trigger
U302 | 4 | Y | AUTO_REQUEST | trigger
J302 | 1 | 1 | AUTO_REQUEST | trigger
J302 | 2 | 2 | RUN_REQUEST | trigger
J302 | 3 | 3 | +3V3_CTRL | trigger
R305 | 1 | ~ | RUN_REQUEST | trigger
R305 | 2 | ~ | GND | trigger
U303 | 6 | VDD | +3V3_CTRL | trigger
U303 | 5 | SENSE | SENSE_12V | trigger
U303 | 3 | MR_N | RUN_REQUEST | trigger
U303 | 1 | RESET_N | AUX_GOOD | trigger
U303 | 4 | CT | NC | trigger
U303 | 2 | GND | GND | trigger
R306 | 1 | ~ | +12V | trigger
R306 | 2 | ~ | SENSE_12V | trigger
R307 | 1 | ~ | SENSE_12V | trigger
R307 | 2 | ~ | GND | trigger
C303 | 1 | ~ | SENSE_12V | trigger
C303 | 2 | ~ | GND | trigger
R308 | 1 | ~ | +3V3_CTRL | trigger
R308 | 2 | ~ | AUX_GOOD | trigger
U304 | 1 | NC | NC | trigger
U304 | 2 | A | AUX_GOOD | trigger
U304 | 3 | GND | GND | trigger
U304 | 5 | VCC | +3V3_CTRL | trigger
U304 | 4 | Y | AUX_BUFFER | trigger
R309 | 1 | ~ | AUX_BUFFER | trigger
R309 | 2 | ~ | HOLD_CHARGE | trigger
D302 | 1 | A | HOLD_CHARGE | trigger
D302 | 2 | K | HOLD_CAP | trigger
R310 | 1 | ~ | HOLD_CAP | trigger
R310 | 2 | ~ | GND | trigger
C304 | 1 | ~ | HOLD_CAP | trigger
C304 | 2 | ~ | GND | trigger
U305 | 1 | NC | NC | trigger
U305 | 2 | A | HOLD_CAP | trigger
U305 | 3 | GND | GND | trigger
U305 | 5 | VCC | +3V3_CTRL | trigger
U305 | 4 | Y | EFUSE_ENABLE | trigger
J201 | 1 | 1 | PVDD_IN | dc-switch
J201 | 2 | 2 | GND | dc-switch
F1 | 1 | ~ | PVDD_IN | dc-switch
F1 | 2 | ~ | FUSED_48V | dc-switch
D401 | 1 | A | FUSED_48V | dc-switch
D401 | 3 | NC | NC | dc-switch
D401 | 2 | K_TAB | DC_PROTECTED | dc-switch
C401 | 1 | ~ | DC_PROTECTED | dc-switch
C401 | 2 | ~ | GND | dc-switch
U401 | 1 | IN | DC_PROTECTED | dc-switch
U401 | 2 | IN | DC_PROTECTED | dc-switch
U401 | 3 | IN | DC_PROTECTED | dc-switch
U401 | 6 | IN_SYS | DC_PROTECTED | dc-switch
U401 | 4 | B_GATE | NC | dc-switch
U401 | 5 | DRV | NC | dc-switch
U401 | 7 | UVLO | EFUSE_UV | dc-switch
U401 | 8 | OVP | EFUSE_OV | dc-switch
U401 | 13 | SHDN | EFUSE_SHDN | dc-switch
U401 | 9 | GND | GND | dc-switch
U401 | 21 | PAD | GND | dc-switch
U401 | 20 | OUT | PVDD | dc-switch
U401 | 19 | OUT | PVDD | dc-switch
U401 | 18 | OUT | PVDD | dc-switch
U401 | 17 | PGOOD | AUDIO_MR | dc-switch
U401 | 16 | PGTH | EFUSE_PGTH | dc-switch
U401 | 15 | FLT_N | EFUSE_FAULT_N | dc-switch
U401 | 14 | IMON | NC | dc-switch
U401 | 12 | MODE | NC | dc-switch
U401 | 11 | ILIM | EFUSE_ILIM | dc-switch
U401 | 10 | dVdT | EFUSE_DVDT | dc-switch
R401 | 1 | ~ | DC_PROTECTED | dc-switch
R401 | 2 | ~ | EFUSE_UV | dc-switch
R402 | 1 | ~ | EFUSE_UV | dc-switch
R402 | 2 | ~ | GND | dc-switch
R403 | 1 | ~ | DC_PROTECTED | dc-switch
R403 | 2 | ~ | EFUSE_OV | dc-switch
R404 | 1 | ~ | EFUSE_OV | dc-switch
R404 | 2 | ~ | GND | dc-switch
R405 | 1 | ~ | PVDD | dc-switch
R405 | 2 | ~ | EFUSE_PGTH | dc-switch
R406 | 1 | ~ | EFUSE_PGTH | dc-switch
R406 | 2 | ~ | GND | dc-switch
R407 | 1 | ~ | EFUSE_ILIM | dc-switch
R407 | 2 | ~ | GND | dc-switch
R408 | 1 | ~ | EFUSE_ENABLE | dc-switch
R408 | 2 | ~ | EFUSE_SHDN | dc-switch
R409 | 1 | ~ | EFUSE_SHDN | dc-switch
R409 | 2 | ~ | GND | dc-switch
R410 | 1 | ~ | PVDD | dc-switch
R410 | 2 | ~ | GND | dc-switch
C402 | 1 | ~ | EFUSE_DVDT | dc-switch
C402 | 2 | ~ | GND | dc-switch
U306 | 6 | VDD | +3V3_CTRL | dc-switch
U306 | 5 | SENSE | SENSE_PVDD | dc-switch
U306 | 3 | MR_N | AUDIO_MR | dc-switch
U306 | 1 | RESET_N | AUDIO_GOOD | dc-switch
U306 | 4 | CT | AUDIO_DELAY | dc-switch
U306 | 2 | GND | GND | dc-switch
R311 | 1 | ~ | PVDD | dc-switch
R311 | 2 | ~ | SENSE_PVDD | dc-switch
R312 | 1 | ~ | SENSE_PVDD | dc-switch
R312 | 2 | ~ | GND | dc-switch
C305 | 1 | ~ | AUDIO_DELAY | dc-switch
C305 | 2 | ~ | GND | dc-switch
R313 | 1 | ~ | +3V3_CTRL | dc-switch
R313 | 2 | ~ | AUDIO_MR | dc-switch
D303 | 1 | A | AUDIO_MR | dc-switch
D303 | 2 | NC | NC | dc-switch
D303 | 3 | K | AUX_GOOD | dc-switch
R314 | 1 | ~ | +3V3_CTRL | dc-switch
R314 | 2 | ~ | AUDIO_GOOD | dc-switch
U307 | 1 | NC | NC | dc-switch
U307 | 2 | A | AUDIO_GOOD | dc-switch
U307 | 3 | GND | GND | dc-switch
U307 | 5 | VCC | +3V3_CTRL | dc-switch
U307 | 4 | Y | RESET_DRIVE | dc-switch
R301 | 1 | ~ | RESET_DRIVE | dc-switch
R301 | 2 | ~ | RESET_N | dc-switch
R302 | 1 | ~ | RESET_N | dc-switch
R302 | 2 | ~ | GND | dc-switch
U4 | 2 | IN | +12V | control-supply
U4 | 1 | OUT | +3V3_CTRL | control-supply
U4 | 3 | GND | GND | control-supply
C301 | 1 | ~ | +12V | control-supply
C301 | 2 | ~ | GND | control-supply
C302 | 1 | ~ | +3V3_CTRL | control-supply
C302 | 2 | ~ | GND | control-supply
C310 | 1 | ~ | +3V3_CTRL | control-supply
C310 | 2 | ~ | GND | control-supply
C311 | 1 | ~ | +3V3_CTRL | control-supply
C311 | 2 | ~ | GND | control-supply
C312 | 1 | ~ | +3V3_CTRL | control-supply
C312 | 2 | ~ | GND | control-supply
C313 | 1 | ~ | +3V3_CTRL | control-supply
C313 | 2 | ~ | GND | control-supply
C314 | 1 | ~ | +3V3_CTRL | control-supply
C314 | 2 | ~ | GND | control-supply
C315 | 1 | ~ | +3V3_CTRL | control-supply
C315 | 2 | ~ | GND | control-supply
J303 | 1 | 1 | GND | control-supply
J303 | 2 | 2 | FAULT_N | control-supply
J303 | 3 | 3 | CLIP_OTW_N | control-supply
J303 | 4 | 4 | EFUSE_FAULT_N | control-supply
J601 | 1 | 1 | CHASSIS | xlr-input
J601 | 2 | 2 | L_XLR_HOT | xlr-input
J601 | 3 | 3 | L_XLR_COLD | xlr-input
R601 | 1 | ~ | L_XLR_HOT | xlr-input
R601 | 2 | ~ | L_LINE_HOT | xlr-input
C601 | 1 | ~ | L_LINE_HOT | xlr-input
C601 | 2 | ~ | L_RX_HOT | xlr-input
R602 | 1 | ~ | L_XLR_COLD | xlr-input
R602 | 2 | ~ | L_LINE_COLD | xlr-input
C602 | 1 | ~ | L_LINE_COLD | xlr-input
C602 | 2 | ~ | L_RX_COLD | xlr-input
C605 | 1 | ~ | L_RX_OUT | xlr-input
C605 | 2 | ~ | L_XLR | xlr-input
R605 | 1 | ~ | L_XLR | xlr-input
R605 | 2 | ~ | GND | xlr-input
J603 | 1 | 1 | L_RCA | xlr-input
J603 | 2 | 2 | L_SELECTED | xlr-input
J603 | 3 | 3 | L_XLR | xlr-input
J602 | 1 | 1 | CHASSIS | xlr-input
J602 | 2 | 2 | R_XLR_HOT | xlr-input
J602 | 3 | 3 | R_XLR_COLD | xlr-input
R603 | 1 | ~ | R_XLR_HOT | xlr-input
R603 | 2 | ~ | R_LINE_HOT | xlr-input
C603 | 1 | ~ | R_LINE_HOT | xlr-input
C603 | 2 | ~ | R_RX_HOT | xlr-input
R604 | 1 | ~ | R_XLR_COLD | xlr-input
R604 | 2 | ~ | R_LINE_COLD | xlr-input
C604 | 1 | ~ | R_LINE_COLD | xlr-input
C604 | 2 | ~ | R_RX_COLD | xlr-input
C606 | 1 | ~ | R_RX_OUT | xlr-input
C606 | 2 | ~ | R_XLR | xlr-input
R606 | 1 | ~ | R_XLR | xlr-input
R606 | 2 | ~ | GND | xlr-input
J604 | 1 | 1 | R_RCA | xlr-input
J604 | 2 | 2 | R_SELECTED | xlr-input
J604 | 3 | 3 | R_XLR | xlr-input
U601 | 1 | NC | NC | xlr-input
U601 | 2 | IN_A- | L_RX_COLD | xlr-input
U601 | 3 | IN_A+ | L_RX_HOT | xlr-input
U601 | 4 | V- | GND | xlr-input
U601 | 5 | IN_B+ | R_RX_HOT | xlr-input
U601 | 6 | IN_B- | R_RX_COLD | xlr-input
U601 | 7 | NC | NC | xlr-input
U601 | 14 | REF_A | L_RX_REF | xlr-input
U601 | 13 | OUT_A | L_RX_OUT | xlr-input
U601 | 12 | SENSE_A | L_RX_OUT | xlr-input
U601 | 11 | V+ | +12V_XLR | xlr-input
U601 | 10 | SENSE_B | R_RX_OUT | xlr-input
U601 | 9 | OUT_B | R_RX_OUT | xlr-input
U601 | 8 | REF_B | R_RX_REF | xlr-input
J605 | 1 | 1 | CHASSIS | xlr-input
J605 | 2 | 2 | CHASSIS | xlr-input
R608 | 1 | ~ | CHASSIS | xlr-input
R608 | 2 | ~ | GND | xlr-input
U602 | 3 | + | VMID | xlr-input
U602 | 2 | - | L_RX_REF | xlr-input
U602 | 1 | OUT | L_RX_REF | xlr-input
U602 | 5 | + | VMID | xlr-input
U602 | 6 | - | R_RX_REF | xlr-input
U602 | 7 | OUT | R_RX_REF | xlr-input
U602 | 8 | V+ | +12V_XLR | xlr-input
U602 | 4 | V- | GND | xlr-input
R607 | 1 | ~ | +12V | xlr-input
R607 | 2 | ~ | +12V_XLR | xlr-input
C609 | 1 | ~ | +12V_XLR | xlr-input
C609 | 2 | ~ | GND | xlr-input
C607 | 1 | ~ | +12V_XLR | xlr-input
C607 | 2 | ~ | GND | xlr-input
C608 | 1 | ~ | +12V_XLR | xlr-input
C608 | 2 | ~ | GND | xlr-input

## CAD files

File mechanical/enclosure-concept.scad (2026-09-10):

// V0.1 SPACE STUDY ONLY. Units: mm. No fabrication-ready holes or tolerances.
// All dimensions are project assumptions, not verified component dimensions.
case_w = 220;
case_d = 180;
case_h = 70;
wall = 2;
pcb_w = 140;
pcb_d = 100;
pcb_t = 1.6;
pcb_z = 10;
sink_w = 80;
sink_d = 60;
sink_h = 35;
sink_base_z = 18; // placeholder, not the actual IC contact height
show_lid = false;

assert(case_w > pcb_w + 2*wall && case_d > pcb_d + 2*wall);
assert(case_h > sink_base_z + sink_h + wall);

color([0.7,0.72,0.75,0.3]) difference() {
    cube([case_w,case_d,case_h]);
    translate([wall,wall,wall])
        cube([case_w-2*wall,case_d-2*wall,case_h]);
}
color("green") translate([(case_w-pcb_w)/2,(case_d-pcb_d)/2,pcb_z])
    cube([pcb_w,pcb_d,pcb_t]);
color([0.2,0.2,0.2,0.7])
    translate([(case_w-sink_w)/2,(case_d-sink_d)/2,sink_base_z])
        cube([sink_w,sink_d,sink_h]);
if (show_lid) color([0.7,0.72,0.75,0.3])
    translate([0,0,case_h]) cube([case_w,case_d,wall]);

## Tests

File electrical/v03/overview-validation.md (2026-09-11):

# 整合電路圖檢查

- KiCad 10.0.6；A0 橫式、單一原生頁面，無子頁；依訊號與控制路徑重新排列。
- 180 個元件的編號、數值、Footprint／Datasheet、單元與符號 UUID 均與八頁來源一致。
- U1／U601 使用獨立 Overview 圖形庫調整腳位排列；逐腳核對編號、名稱、電氣型態與所屬單元，其餘符號沿用原庫。
- 483 個電氣腳位、120 個網路群組與八頁來源及 `expected-connections.csv` 完全吻合。
- 額外移除所有標籤再匯出接線表：79 組音訊、四路回授及主要啟停控制網路仍完整相連，確認依靠實際導線連接。
- 保留自訂標籤文字；改用單頁局部標籤，匯出名稱增加 `/` 前綴；以腳位群組比較確認等價。
- 八頁來源及單頁總圖 ERC 均為 0 錯誤／0 警告，無排除項目；UUID 無重複。
- `overview-sources.json` 記錄來源及總圖 SHA-256；來源變動而未重建時，檢查會失敗。

只調整圖面排版，未改動電路，未新增性能或實機驗證。既有 PCB 仍對應八頁來源的階層路徑，請從 `tpa3255-v03.kicad_pro` 更新 PCB；單頁版供審閱及衍生編輯。

重建與檢查：

```sh
python3 tools/build_schematic_overview.py
python3 tools/verify_schematic_overview.py
python3 tools/export_schematic.py electrical/v03/tpa3255-v03-overview.kicad_sch --pdf-from-svg --png-width 4800
```

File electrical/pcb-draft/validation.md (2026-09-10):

# PCB 配置草案檢查

- KiCad 10.0.6；180 個電路元件、4 個固定孔；127 個元件在正面、53 個在背面。
- 483 個電氣腳號（484 個編號銅焊盤，DPAK 陰極腳與散熱片共用腳號）、120 個網路，與最新原理圖及預期接線群組逐一吻合；符號 UUID 對應已核對。
- 核對 TPA3255 的 44 腳頂面散熱封裝、TPS26631 第 21 腳接地、BAT54 第 3 腳陰極／第 2 腳 NC，以及兩顆軸向二極體的陰極標記與焊盤編號。
- 通孔焊盤的正反面阻焊開口與焊盤位於板內已檢查。
- 幾何／封裝 DRC 違規 0 項；**仍有 364 項未連接**。完整原始結果在 [drc.json](drc.json)，未排除這些未連接項目。
- 板形暫用 220×160 mm、4 層；0 條走線、0 個覆銅區。幾何檢查不表示佈局已適合高功率或低噪聲。

**未通過製造放行。** 多數被動件與接頭仍是尺寸占位，未核定料號、額定與孔位；尚待 12V 保護、回授／啟停與散熱審查、走線、地平面、機箱配合和實機驗證。本報告不證明音質、穩定度、溫升、電流承載或市電安全。

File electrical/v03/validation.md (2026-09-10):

# V0.3 驗證結果

- KiCad 10.0.6：ERC 0 錯誤／0 警告，無排除。
- 180 元件、483 接腳、120 網路：完整接線群組與關鍵腳位核對通過。
- 額外核對：XLR 正負腳／屏蔽／緩衝參考／輸入選擇、PFFB 同臂與耦合位置、Trigger 隔離、功率供電及靜音控制。
- 控制時序規格模型：9 個情境通過；不是控制 IC 的 SPICE 硬體模型。

## 音訊 AC 簡化模型

| 輸入 | 負載 | 假設功率級極點 | 20Hz 相對 1kHz | 20kHz 相對 1kHz |
|---|---|---|---|---|
| RCA | 4Ω | 無限頻寬 | -0.023dB | -0.277dB |
| RCA | 4Ω | 100kHz，敏感度試算 | -0.023dB | -0.091dB |
| RCA | 8Ω | 無限頻寬 | -0.023dB | +0.304dB |
| RCA | 8Ω | 100kHz，敏感度試算 | -0.024dB | +0.383dB |
| RCA | 空載近似 | 無限頻寬 | -0.024dB | +0.556dB |
| RCA | 空載近似 | 100kHz，敏感度試算 | -0.024dB | +0.483dB |
| XLR | 4Ω | 無限頻寬 | -0.033dB | -0.277dB |
| XLR | 4Ω | 100kHz，敏感度試算 | -0.034dB | -0.091dB |
| XLR | 8Ω | 無限頻寬 | -0.034dB | +0.304dB |
| XLR | 8Ω | 100kHz，敏感度試算 | -0.035dB | +0.383dB |
| XLR | 空載近似 | 無限頻寬 | -0.034dB | +0.556dB |
| XLR | 空載近似 | 100kHz，敏感度試算 | -0.034dB | +0.483dB |

無限頻寬功率級模型下，50W/8Ω 所需 RCA 為 2.126Vrms、XLR 差動為 4.268Vrms；低於 Z10 標示的 2.5 / 5Vrms。
RCA 2.5Vrms 與 XLR 差動 5Vrms 的模型輸出差異，在全部負載／極點案例的 20Hz、1kHz、20kHz 均小於 0.1dB。
12 組差動／RCA 響應與 2 組共模模型通過；共模模型只評估外部 47Ω 電阻 ±0.1%、配對 47µF 電容 ±0.5% 的影響。
INA2137 內部電阻比與 REF 驅動在模型中理想化，共模結果不能當成整機 CMRR 規格；需要實測元件不匹配與訊源阻抗。
該輸出條件下前端最大交流峰值約 2.614V，相對 VMID；實際 NE5532 擺幅仍需驗證。
運放為理想有限增益源；功率級為典型增益線性源。沒有驗證真正的噪聲、THD、開關延遲或回授穩定裕度。
100kHz 極點是自訂敏感度假設，不能當成原廠 TPA3255 模型。空載 AC 計算成功也不代表實機不振盪。

## 控制與元件核算

- 12V 監測名義門檻 11.219V；PVDD 監測 40.905V。
- eFuse 過壓門檻名義 50.640V，含比較器／電阻／漏電最壞估算上限 51.816V。
- 電源良好後開聲延遲名義 1.029s，180nF 資料表最小值加 5% 電容餘裕約 0.589s。
- 正常 3.3V 控制電源下，關機保持 RC 試算 0.071–0.983s；含閾值包絡及 ±5µA 漏電假設，待實測。
- RESET 無電源低態核算 ≤0.522V；RUN 高態核算 ≥2.329V。
- Trigger 設計輸入 9V 時 LED 最小約 1.092mA；12V 標稱約 1.603mA。
- eFuse 48V 軟啟動名義 2.196s；只計 940µF 主電容充電約 0.021A。
- MA5172-AE：50W/8Ω 加估算開關紋波後約 2.616Arms，每顆銅損約 0.178W（25°C DCR 上限）。
電感計算不含磁芯損耗；45A 是原廠 10% 電感下降的典型條件，不是連續可用電流。
PCB 僅有未走線配置草案（見 ../pcb-draft/）；尚無完成的 PCB／製造 DRC、實機電感溫升／保護試驗、Z10 Trigger 電壓與極性量測、功率開關熱驗證或整機音質實測。
資料來源與設計限制見 [V0.3 設計說明](../../docs/V0.3_設計說明.md)。

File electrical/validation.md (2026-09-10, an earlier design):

# V0.2 電氣驗證

由 `python3 tools/verify_electrical.py` 產生；先讀取實際 KiCad netlist，再建立區塊模型。

- KiCad 10.0.6：ERC 0 錯誤、0 警告；未排除違規。
- 接線群組核對：94 個元件、246 個接腳、56 個 net 通過。
- 已核對：主／輔助電源網路分離（共地）、44-pin 對應關鍵網路、bootstrap、重複輸出腳、內部穩壓輸出只接去耦。
- ngspice：兩聲道輸入級及 4Ω／8Ω 輸出濾波區塊 AC 分析通過；不是整顆 TPA3255 的開關模型。

| 頻率 | 輸入級差動增益 V/V | 4Ω 濾波增益 dB | 8Ω 濾波增益 dB |
|---|---|---|---|
| 20 Hz | 0.79817 | -0.214 | -0.108 |
| 1000 Hz | 0.79921 | -0.215 | -0.106 |
| 20000 Hz | 0.79867 | -0.613 | +0.809 |

1kHz 時以前端模型增益及晶片典型 21.5dB 計算，50W/8Ω 所需 RCA 約 2.106Vrms（未含輸出 LC 損耗）。
RESET 以 100µA 漏電、1% 電阻與 3.3V 電源 ±5% 假設核算：無跳線低態 ≤0.475V；RUN 高態 ≥2.493V。

模型限制：運放為理想受控源、有限 DC 增益 10⁶；TPA3255 輸入以 20kΩ 小訊號負載近似；VMID 為理想 6V。
未建模運放實際頻寬／擺幅／雜訊、啟停、PWM、保護、電感飽和、EMI、寄生、實際喇叭阻抗或熱。
電感 DCR 每顆 0.05Ω 為假設，需以選定料號修正。8Ω 高頻增益尚需調整或訂定驗收範圍。
未指定 footprint、F1 額定與功率元件最終料號，這份 ERC 通過不代表可製板。

來源：見 [V0.2 設計說明](../docs/V0.2_電路設計.md)。

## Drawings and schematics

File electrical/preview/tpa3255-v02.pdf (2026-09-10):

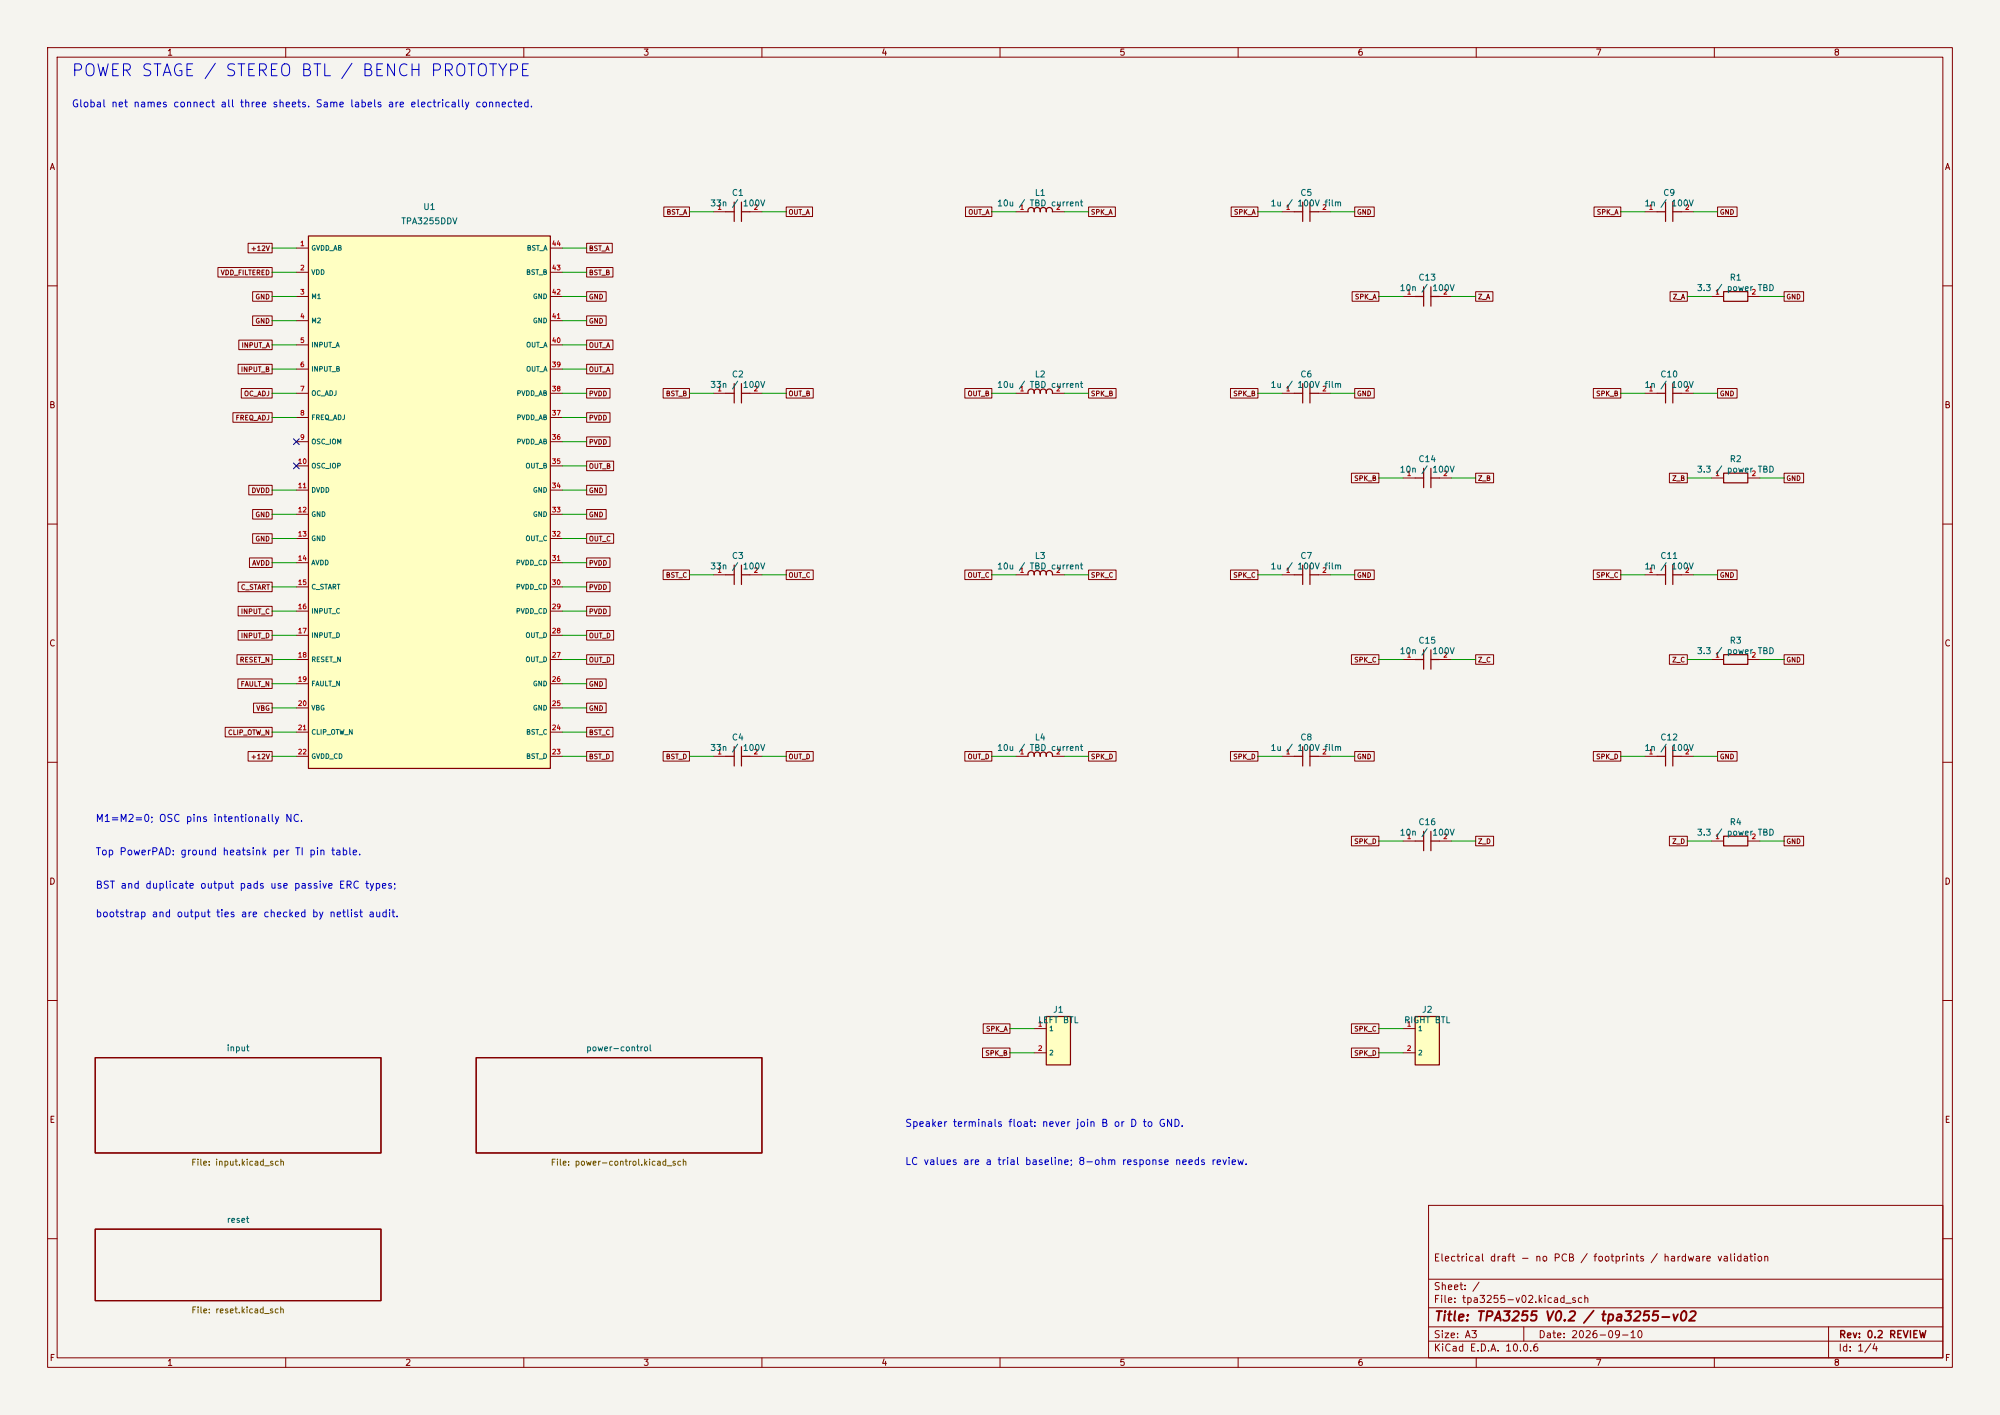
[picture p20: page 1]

POWER STAGE / STEREO BTL / BENCH PROTOTYPE

+12V Global net names connect all three sheets. Same labels are electrically connected.

M1=M2=0; OSC pins intentionally NC.

Top PowerPAD: ground heatsink per TI pin table.

BST and duplicate output pads use passive ERC types;

bootstrap and output ties are checked by netlist audit.

power-control File: power-control.kicad_sch

Speaker terminals float: never join B or D to GND.

LC values are a trial baseline; 8-ohm response needs review.

Electrical draft - no PCB / footprints / hardware validation

Size: A3 | Rev: 0.2 REVIEW | F Date: 2026-09-10
KiCad E.D.A. 10.0.6 | Id: 1/4

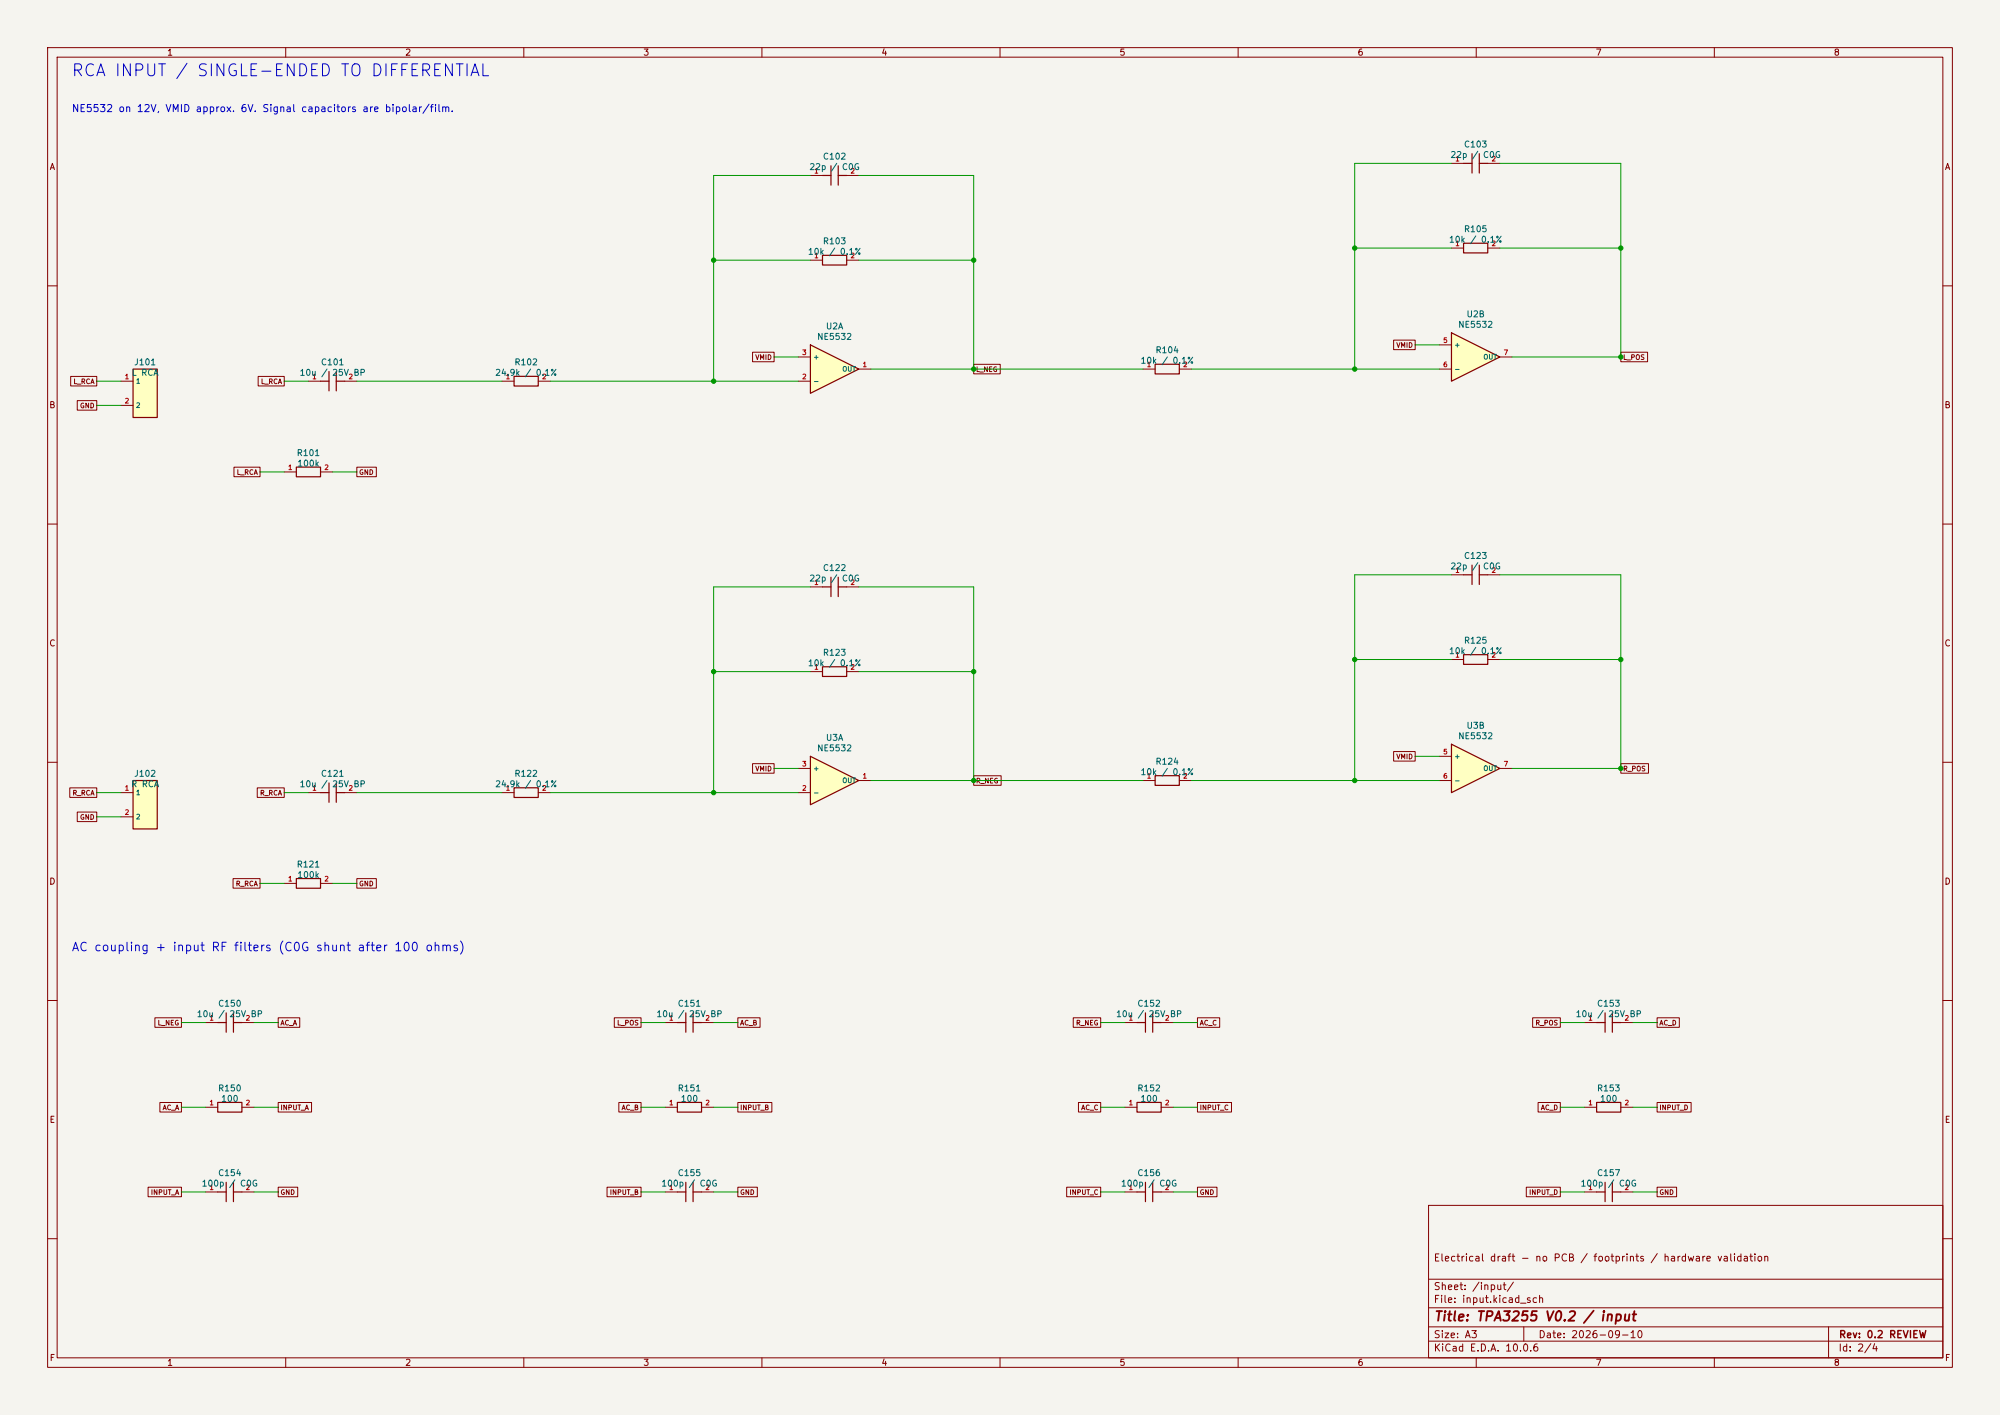
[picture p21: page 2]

RCA INPUT / SINGLE-ENDED TO DIFFERENTIAL

NE5532 on 12V, VMID approx. 6V. Signal capacitors are bipolar/film.

VMID AC coupling + input RF filters (C0G shunt after 100 ohms)

Electrical draft - no PCB / footprints / hardware validation

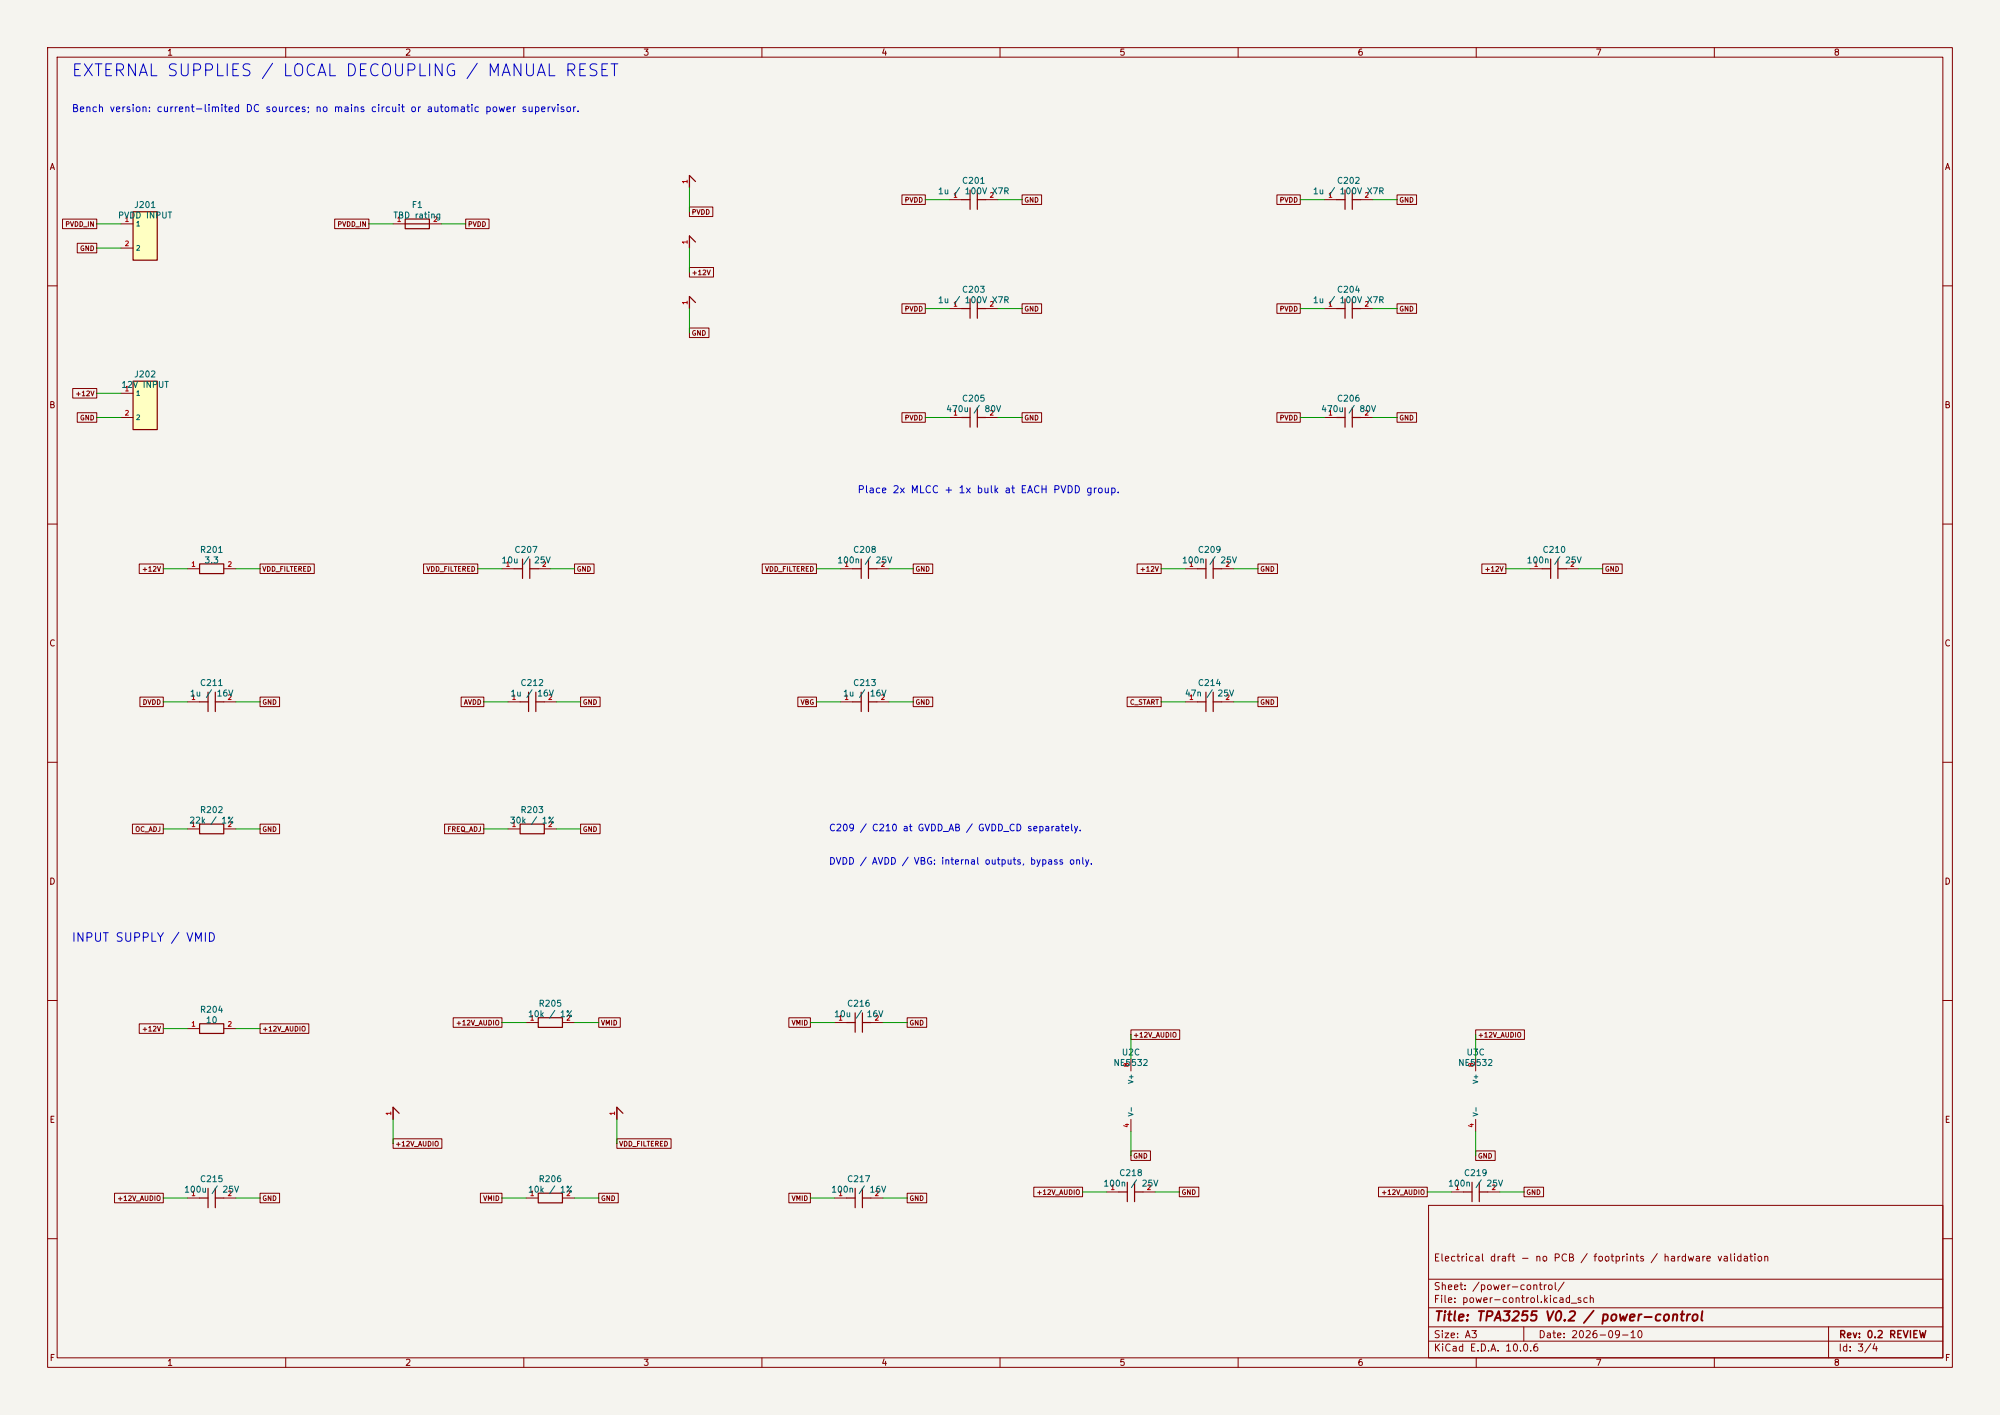
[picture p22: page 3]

EXTERNAL SUPPLIES / LOCAL DECOUPLING / MANUAL RESET

Bench version: current-limited DC sources; no mains circuit or automatic power supervisor.

Place 2x MLCC + 1x bulk at EACH PVDD group.

DVDD / AVDD / VBG: internal outputs, bypass only.

Electrical draft - no PCB / footprints / hardware validation

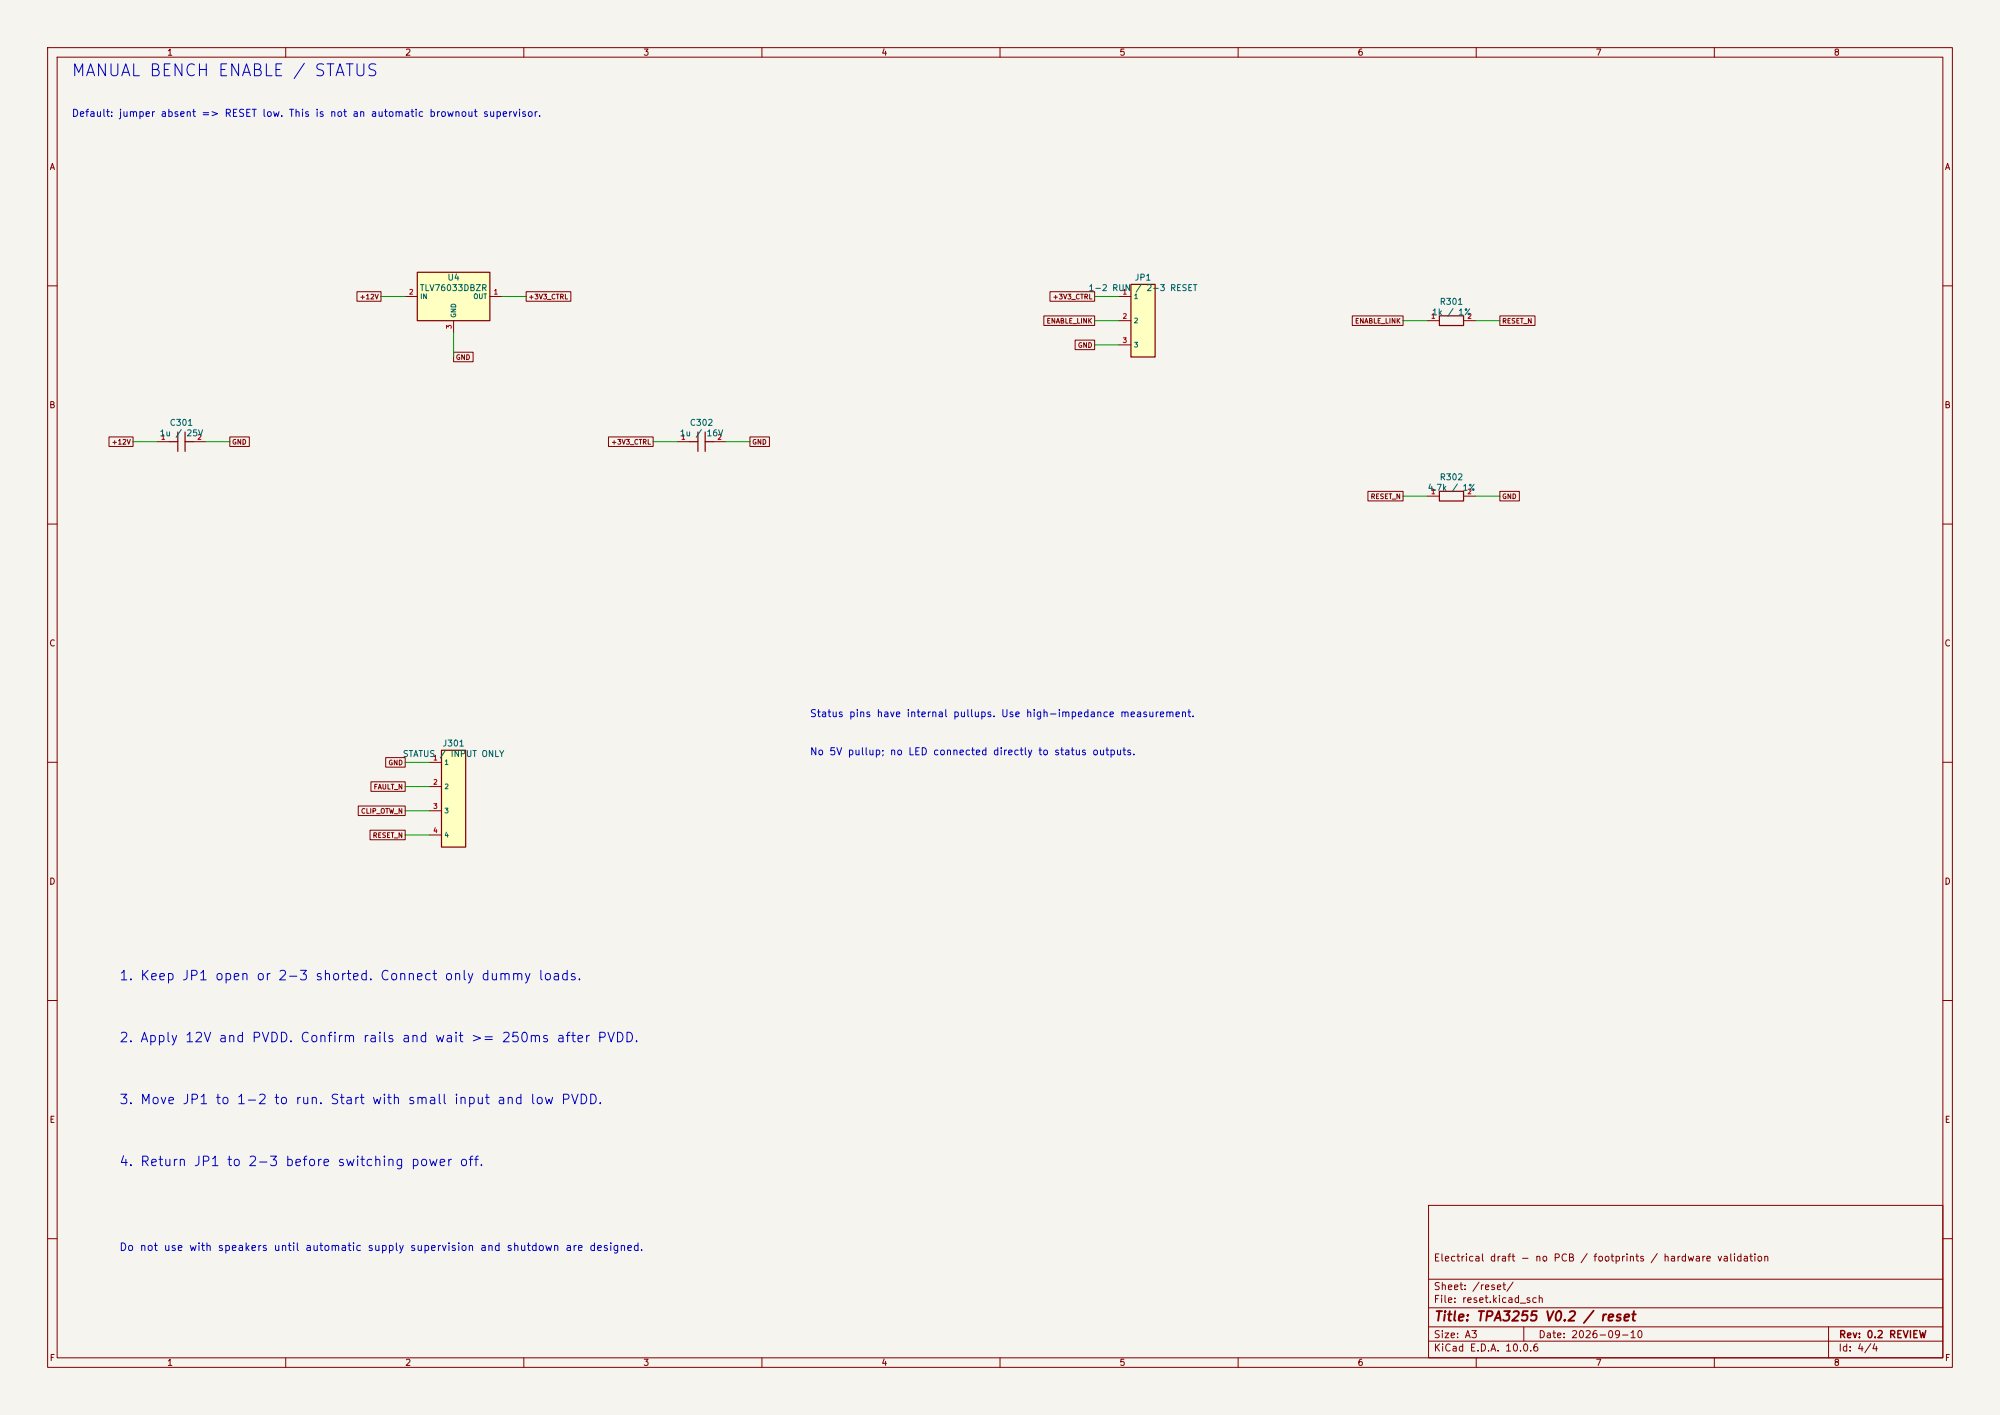
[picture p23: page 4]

MANUAL BENCH ENABLE / STATUS

Status pins have internal pullups. Use high-impedance measurement.

No 5V pullup; no LED connected directly to status outputs.

1. Keep JP1 open or 2-3 shorted. Connect only dummy loads.

2. Apply 12V and PVDD. Confirm rails and wait >= 250ms after PVDD.

3. Move JP1 to 1-2 to run. Start with small input and low PVDD.

4. Return JP1 to 2-3 before switching power off.

Do not use with speakers until automatic supply supervision and shutdown are designed.

Electrical draft - no PCB / footprints / hardware validation

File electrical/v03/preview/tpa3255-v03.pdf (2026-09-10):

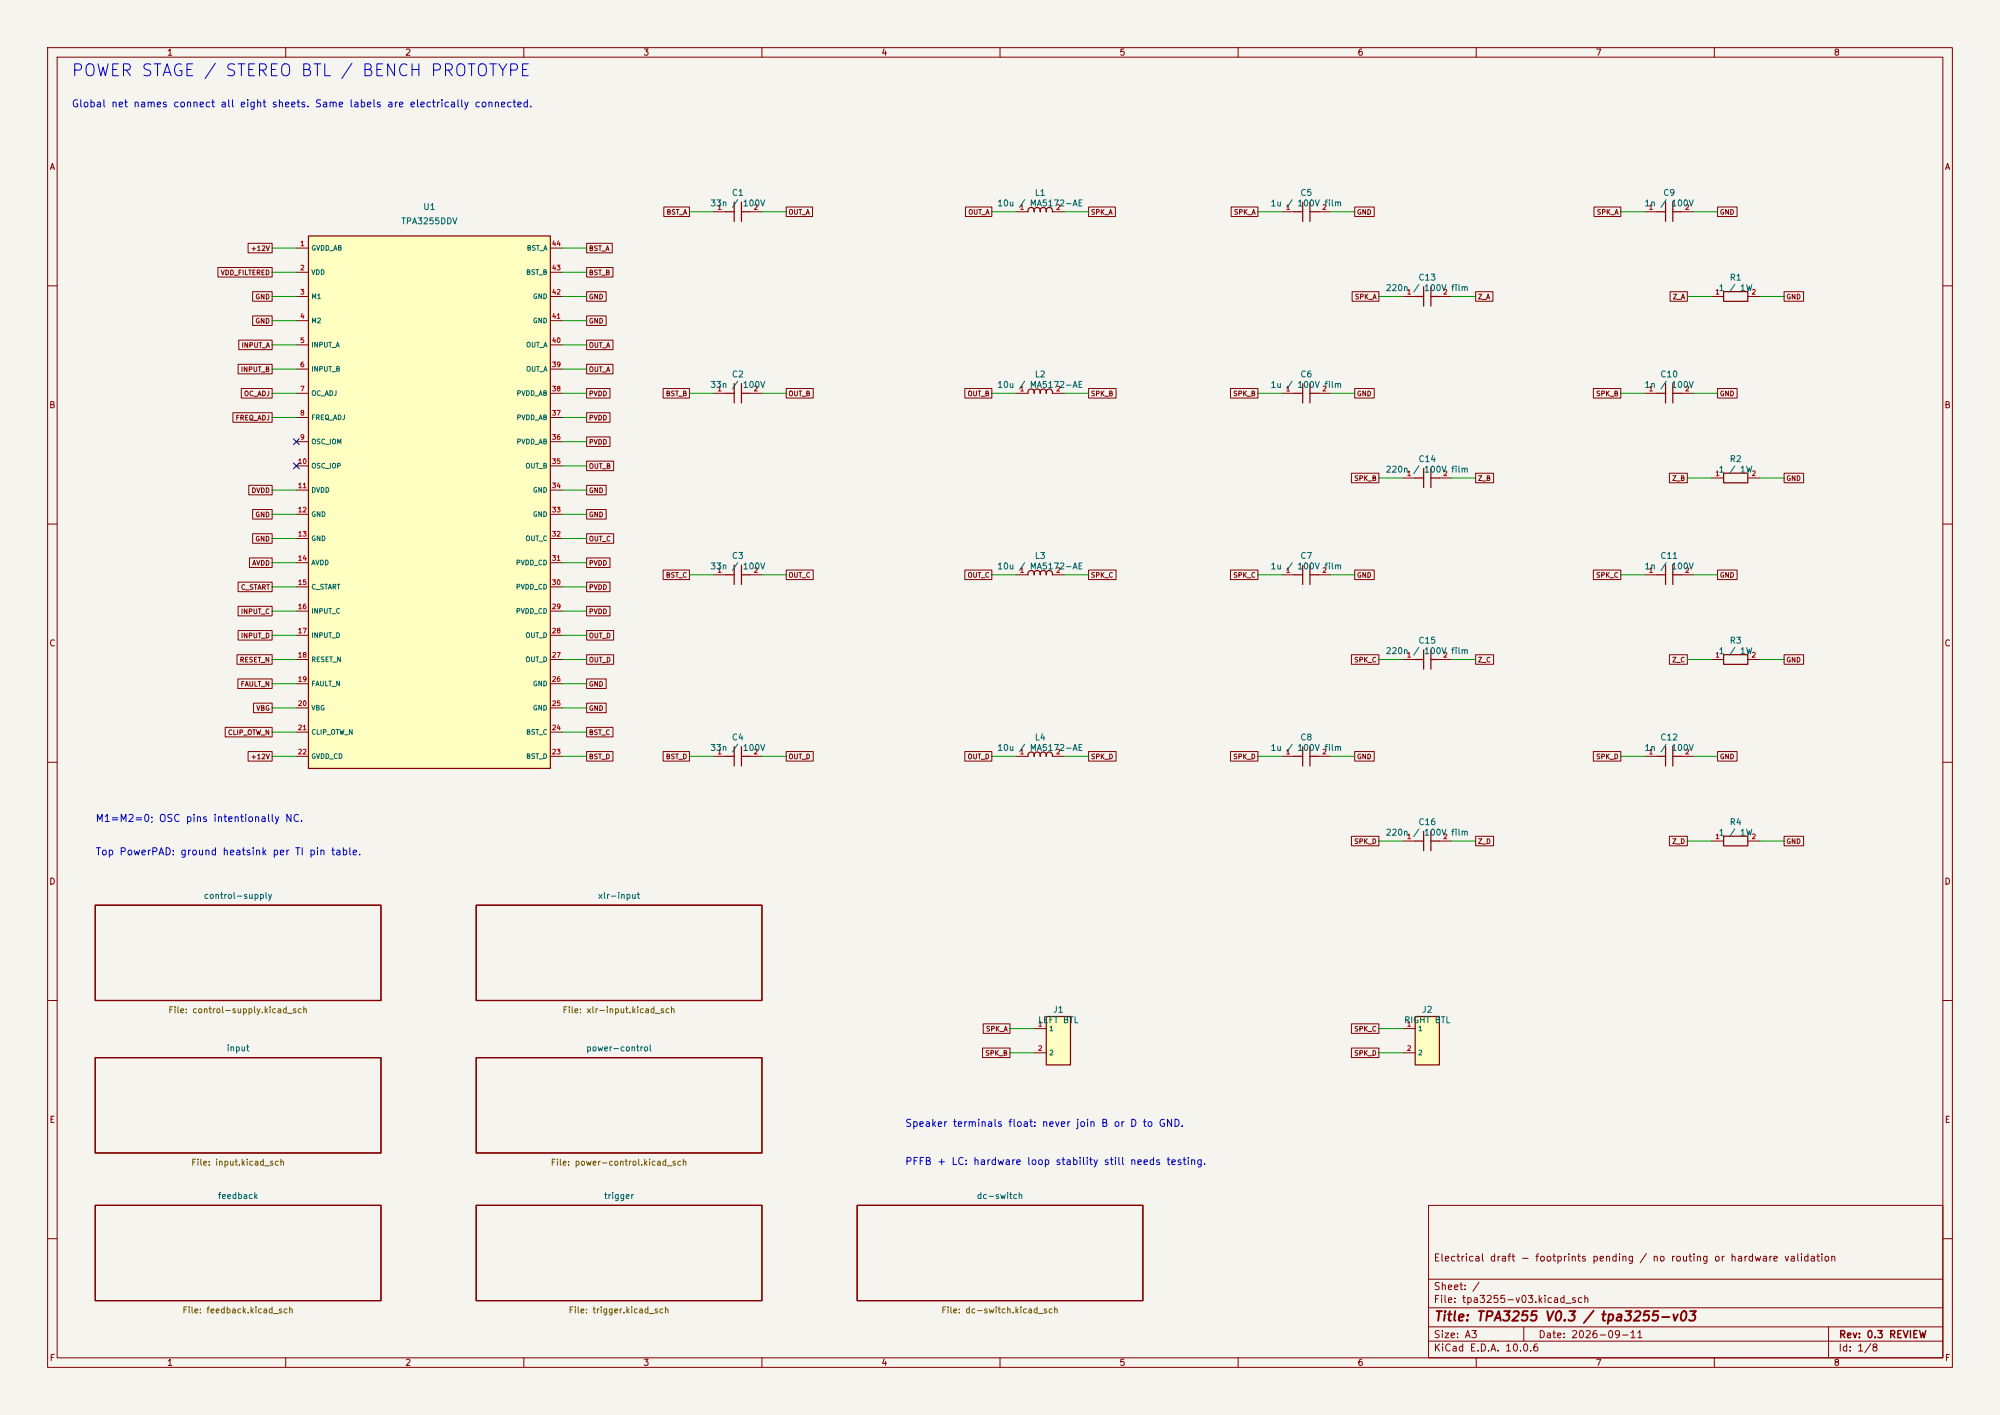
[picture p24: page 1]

POWER STAGE / STEREO BTL / BENCH PROTOTYPE

Global net names connect all eight sheets. Same labels are electrically connected.

M1=M2=0; OSC pins intentionally NC.

Top PowerPAD: ground heatsink per TI pin table.

control-supply File: control-supply.kicad_sch

xlr-input File: xlr-input.kicad_sch

power-control File: power-control.kicad_sch

Speaker terminals float: never join B or D to GND.

PFFB + LC: hardware loop stability still needs testing.

Electrical draft - footprints pending / no routing or hardware validation

Size: A3 | Rev: 0.3 REVIEW | F Date: 2026-09-11
KiCad E.D.A. 10.0.6 | Id: 1/8

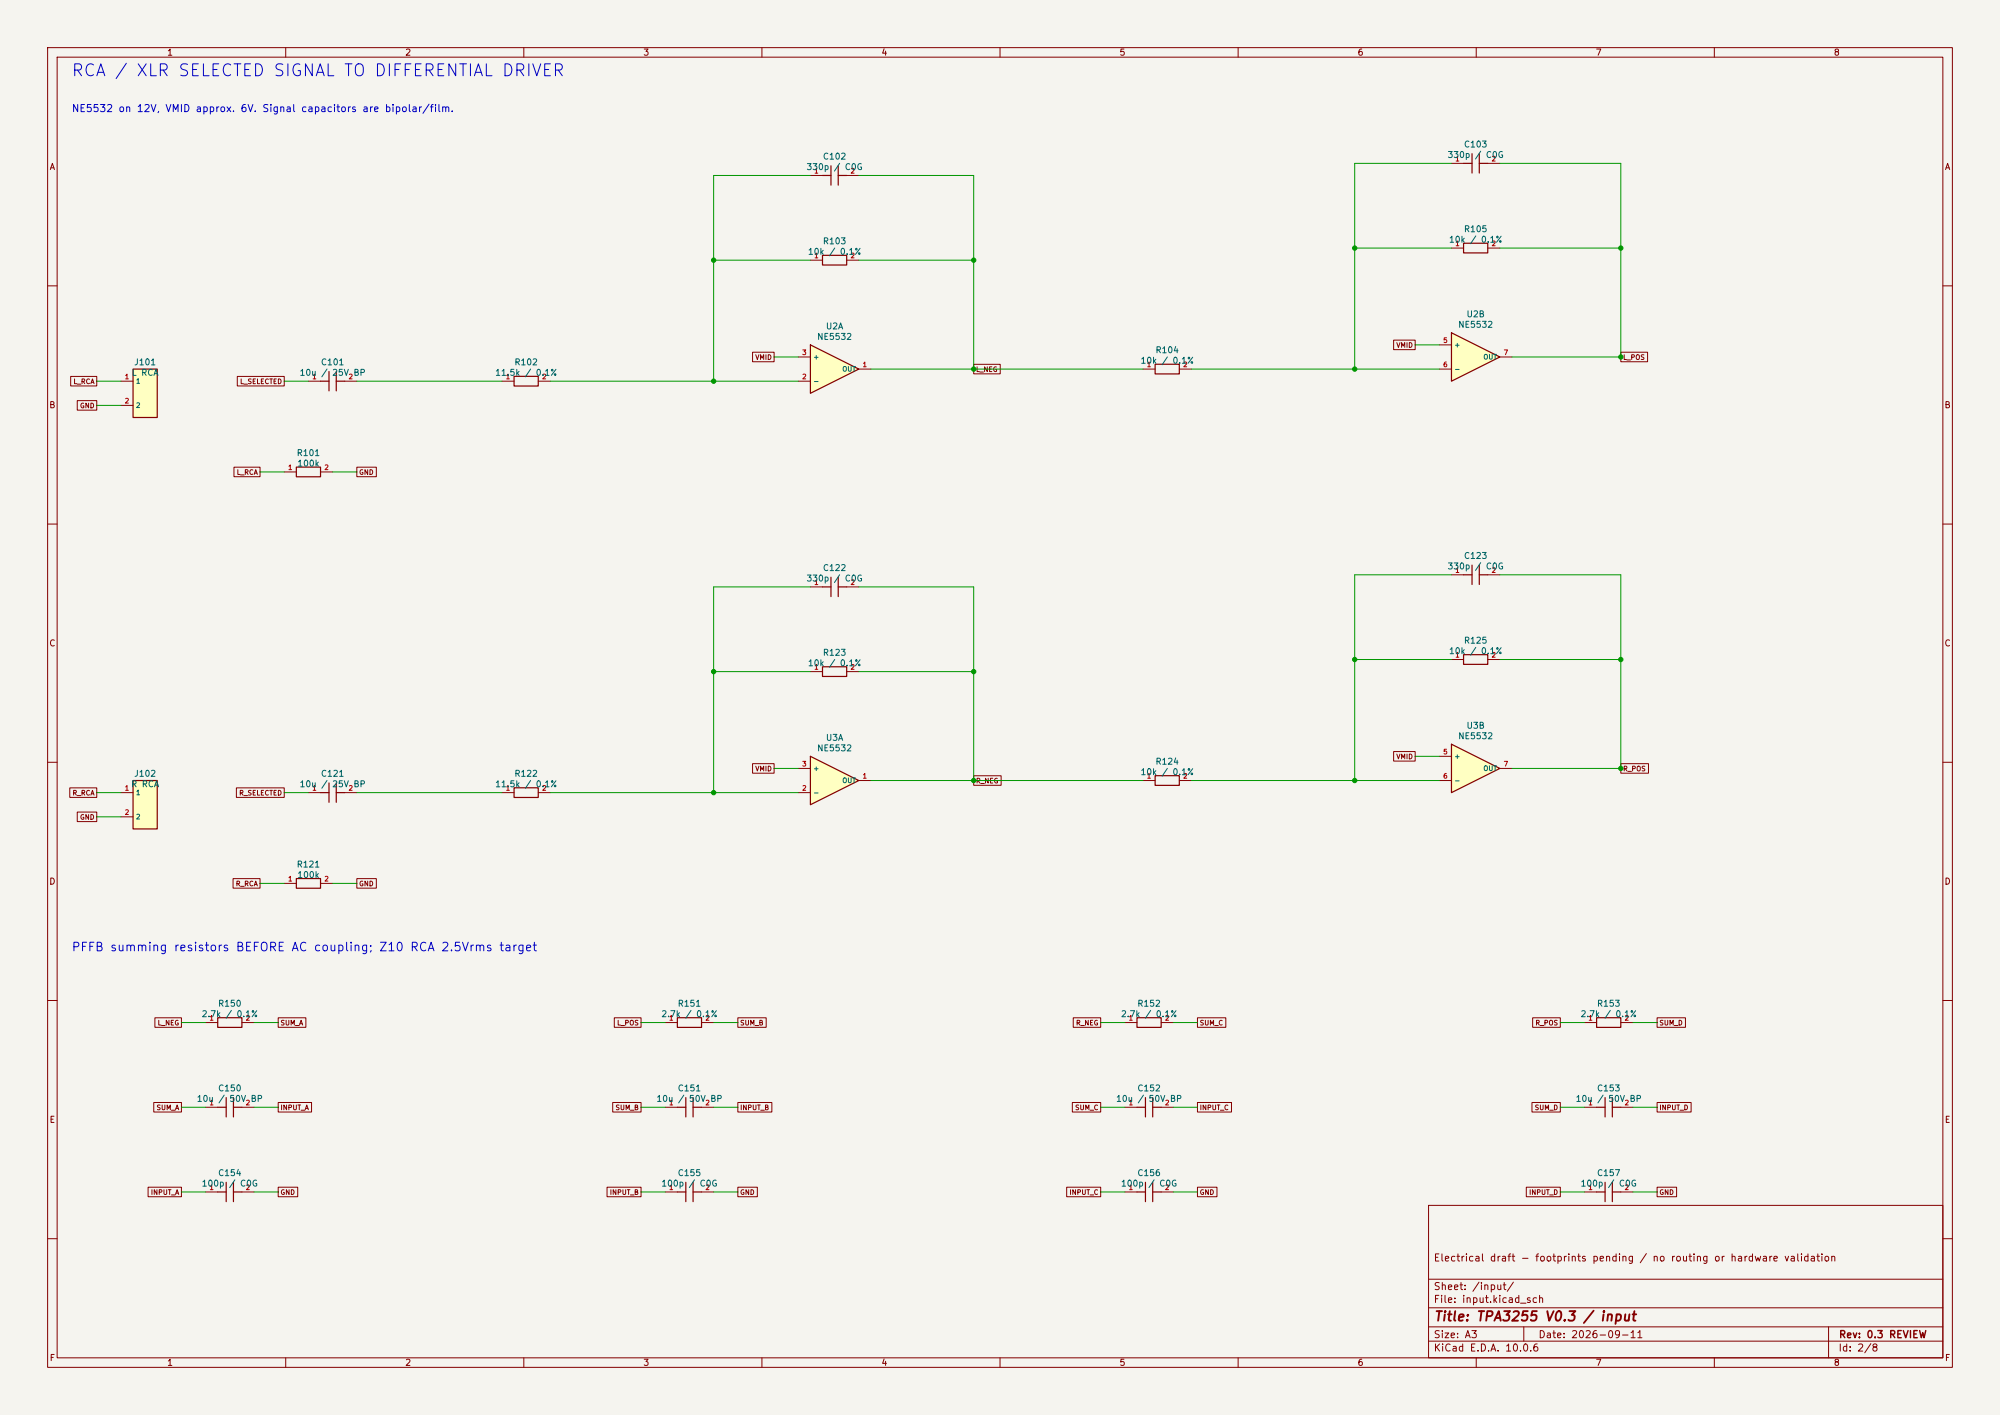
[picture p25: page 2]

RCA / XLR SELECTED SIGNAL TO DIFFERENTIAL DRIVER

NE5532 on 12V, VMID approx. 6V. Signal capacitors are bipolar/film.

SUM_A PFFB summing resistors BEFORE AC coupling; Z10 RCA 2.5Vrms target

Electrical draft - footprints pending / no routing or hardware validation

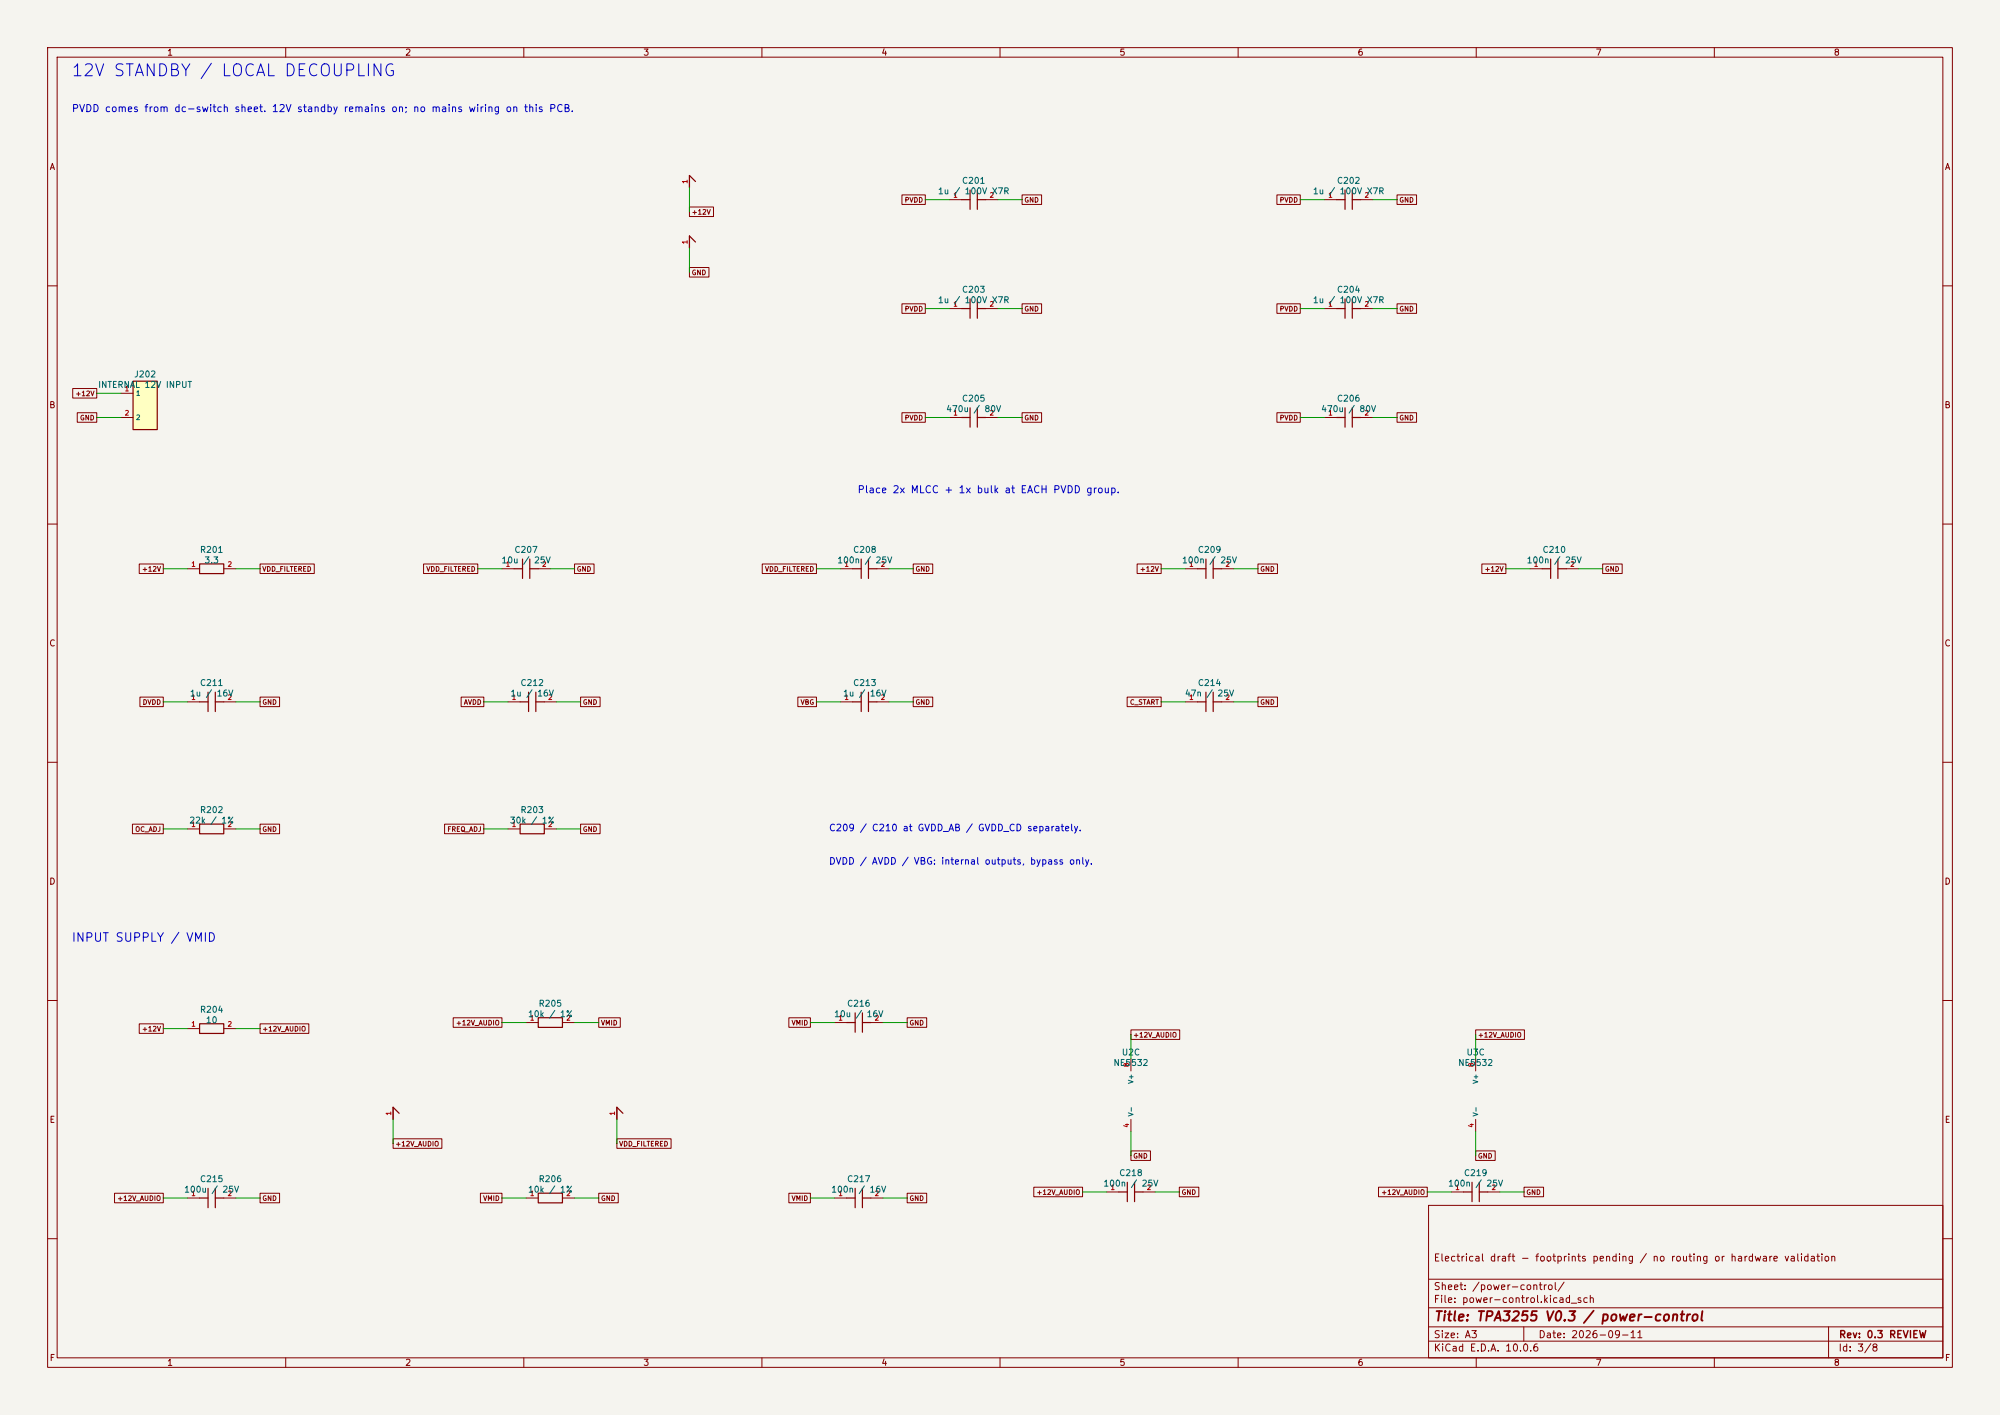
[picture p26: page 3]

PVDD comes from dc-switch sheet. 12V standby remains on; no mains wiring on this PCB.

Place 2x MLCC + 1x bulk at EACH PVDD group. DVDD / AVDD / VBG: internal outputs, bypass only.

Electrical draft - footprints pending / no routing or hardware validation

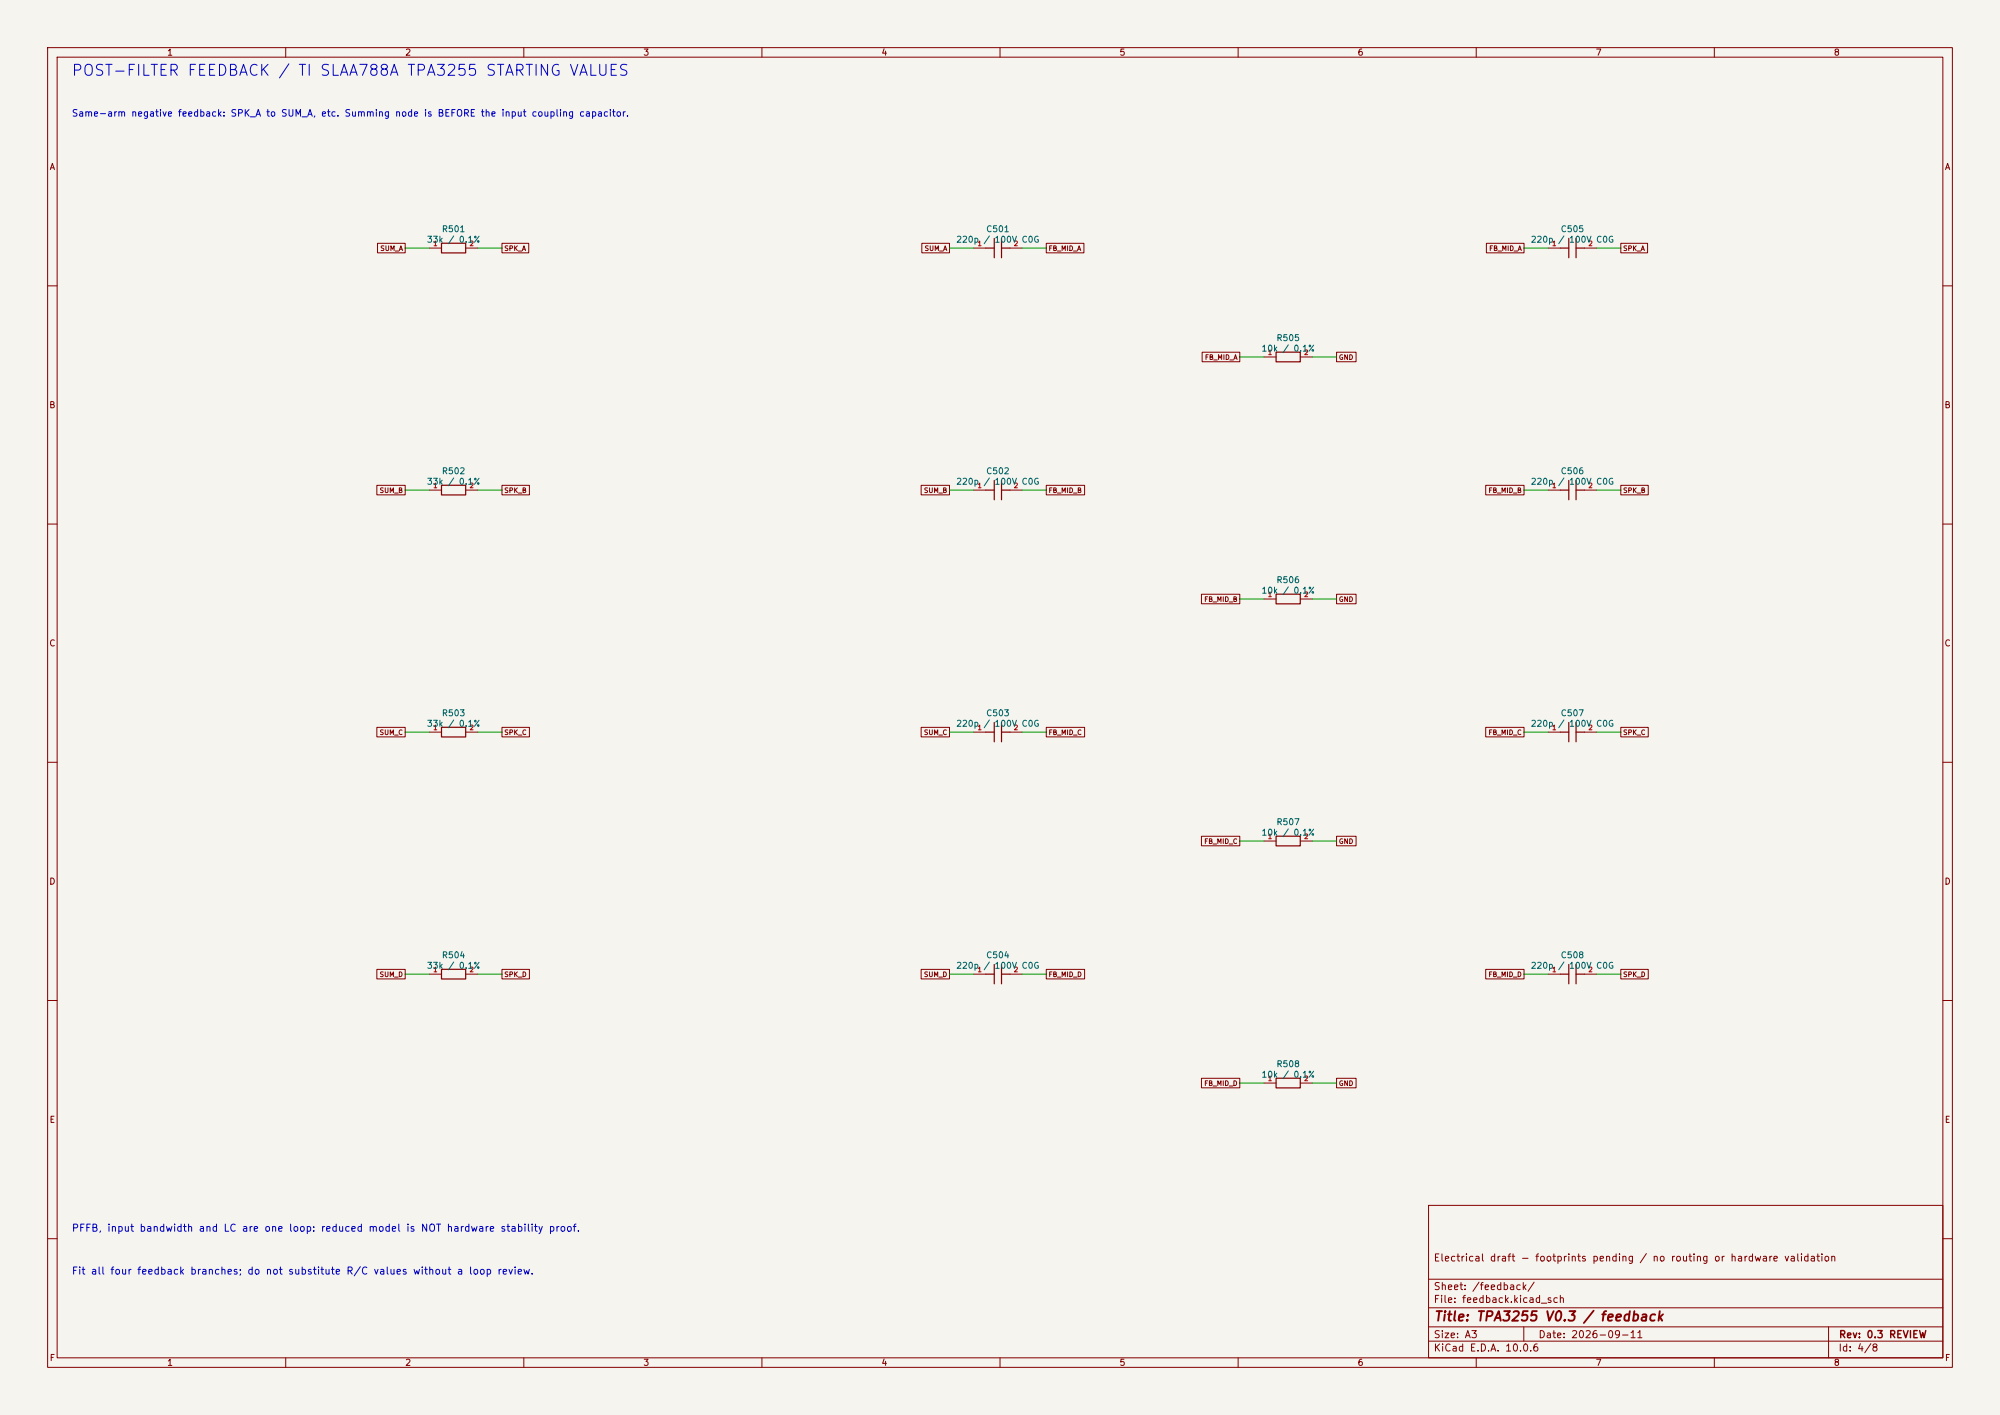
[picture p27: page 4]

POST-FILTER FEEDBACK / TI SLAA788A TPA3255 STARTING VALUES

Same-arm negative feedback: SPK_A to SUM_A, etc. Summing node is BEFORE the input coupling capacitor.

SUM_D Fit all four feedback branches; do not substitute R/C values without a loop review.

PFFB, input bandwidth and LC are one loop: reduced model is NOT hardware stability proof.

Electrical draft - footprints pending / no routing or hardware validation

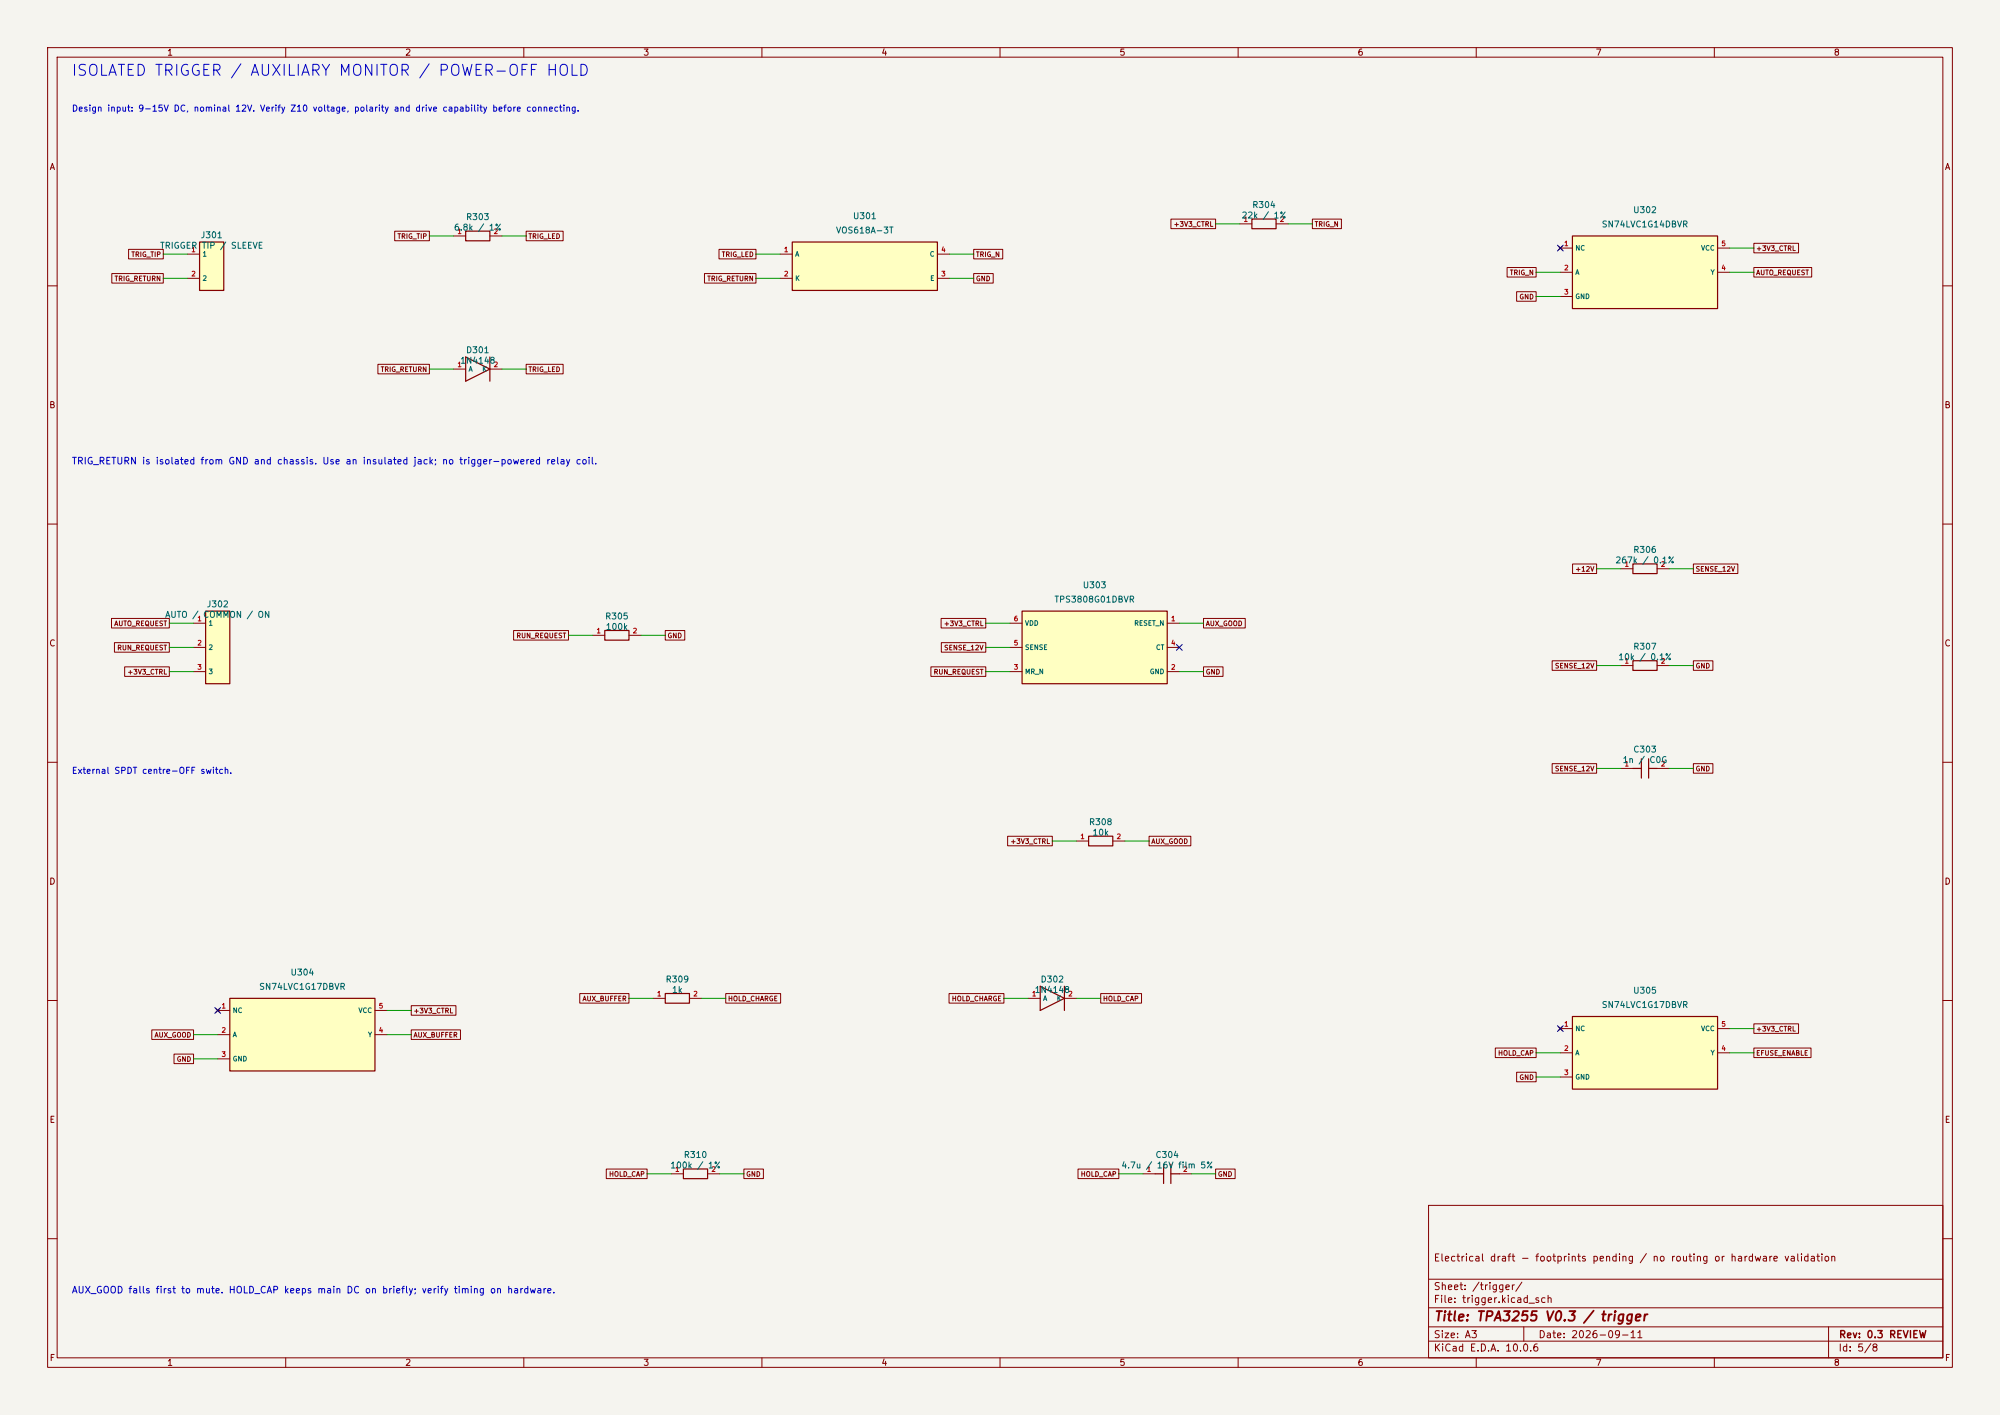
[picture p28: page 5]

ISOLATED TRIGGER / AUXILIARY MONITOR / POWER-OFF HOLD

Design input: 9-15V DC, nominal 12V. Verify Z10 voltage, polarity and drive capability before connecting.

TRIG_RETURN is isolated from GND and chassis. Use an insulated jack; no trigger-powered relay coil.

External SPDT centre-OFF switch.

Electrical draft - footprints pending / no routing or hardware validation

AUX_GOOD falls first to mute. HOLD_CAP keeps main DC on briefly; verify timing on hardware.

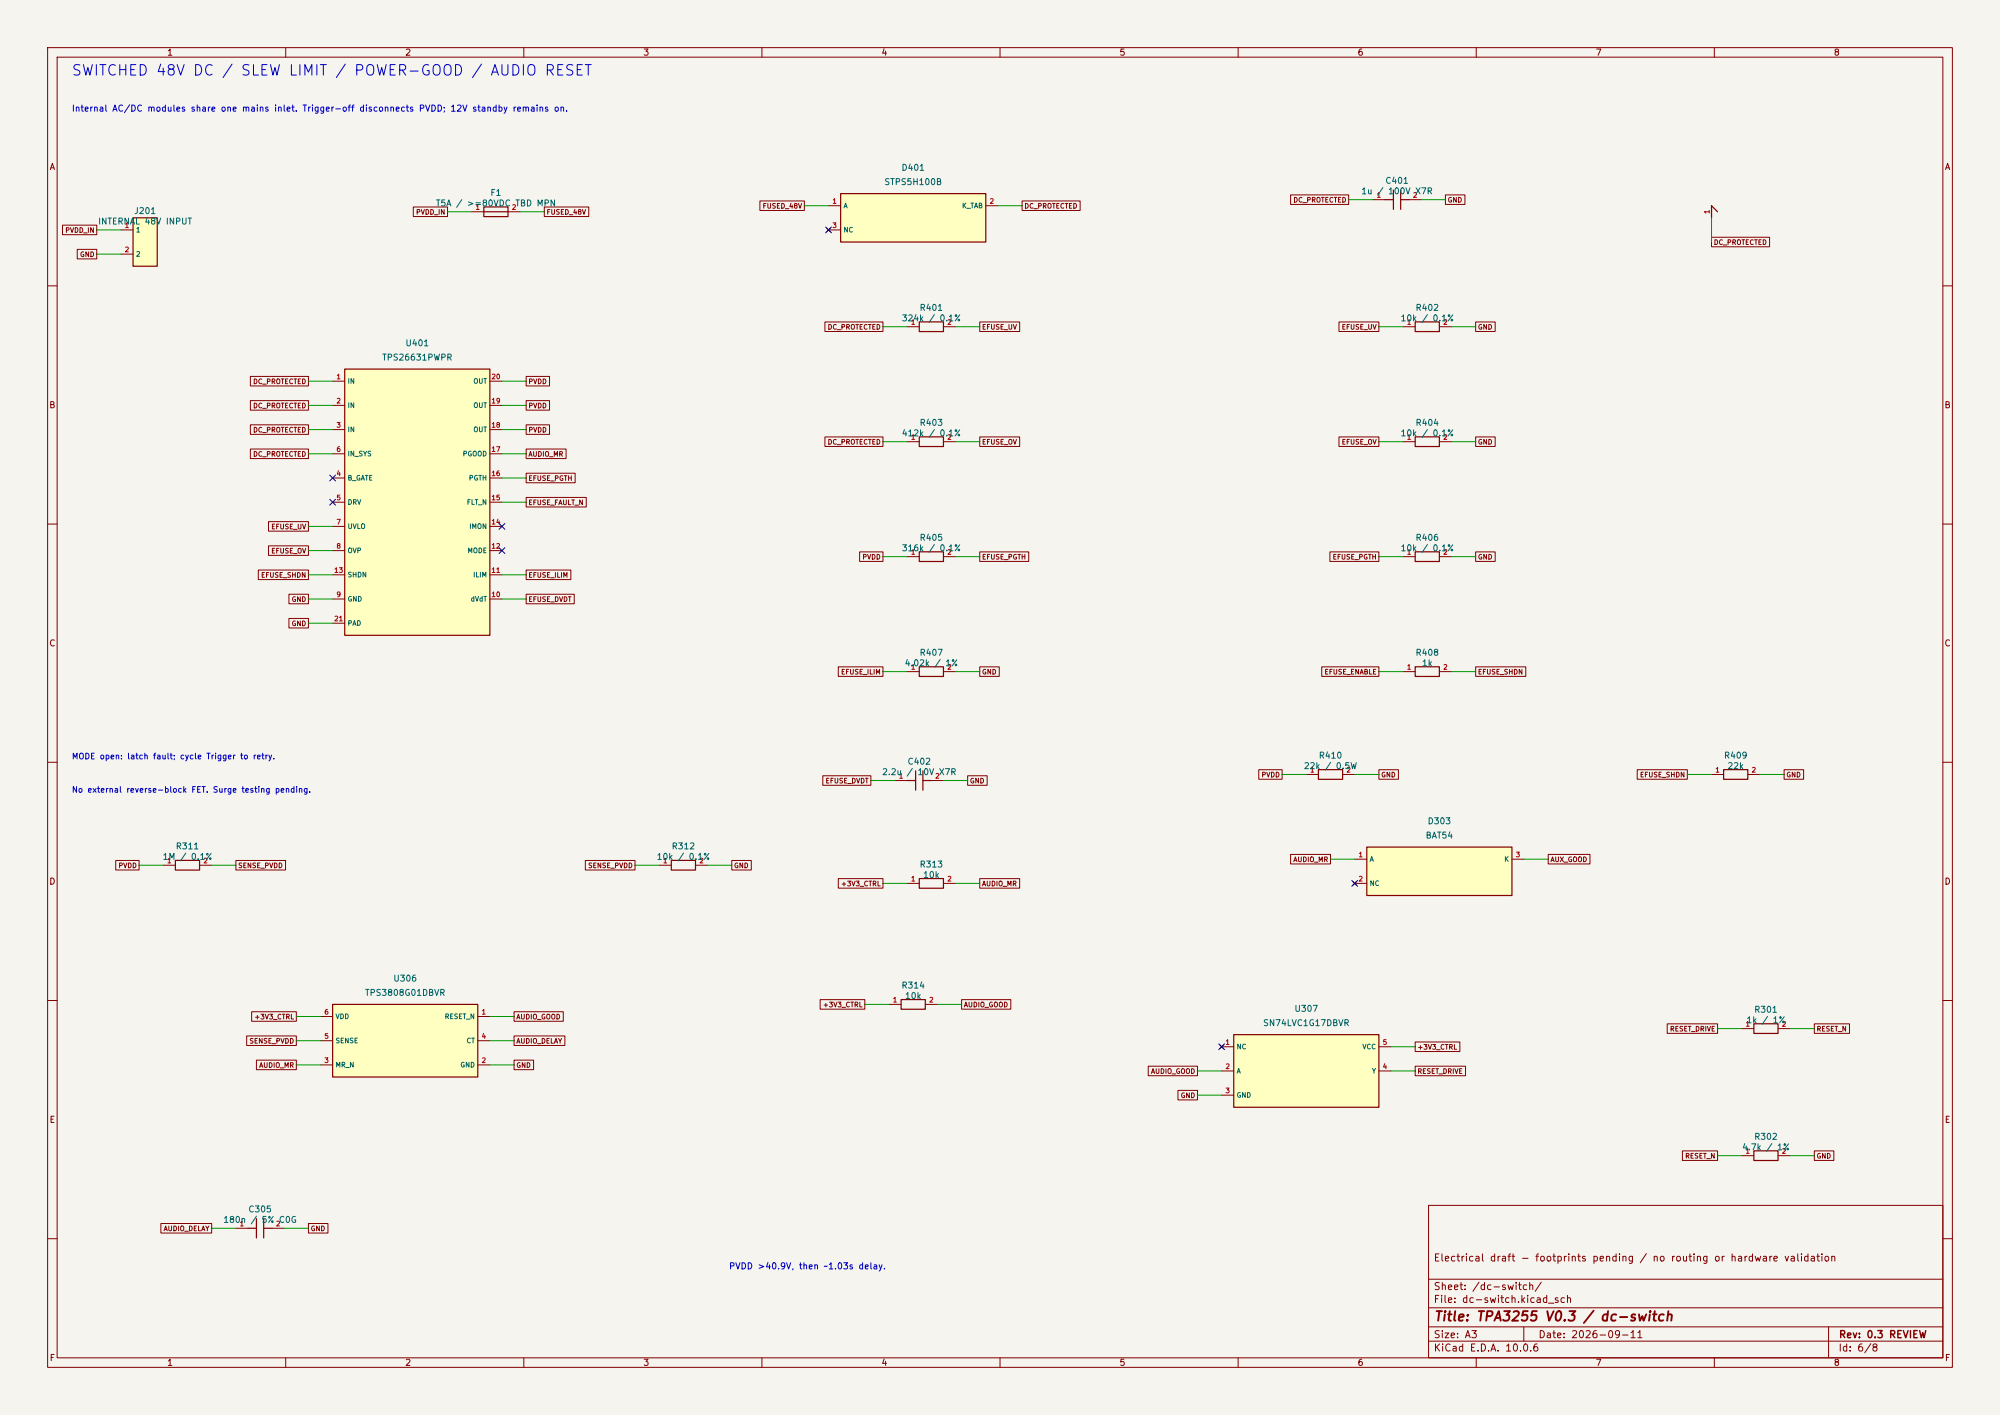
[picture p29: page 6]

Internal AC/DC modules share one mains inlet. Trigger-off disconnects PVDD; 12V standby remains on. SWITCHED 48V DC / SLEW LIMIT / POWER-GOOD / AUDIO RESET

PVDD No external reverse-block FET. Surge testing pending. MODE open: latch fault; cycle Trigger to retry.

Electrical draft - footprints pending / no routing or hardware validation

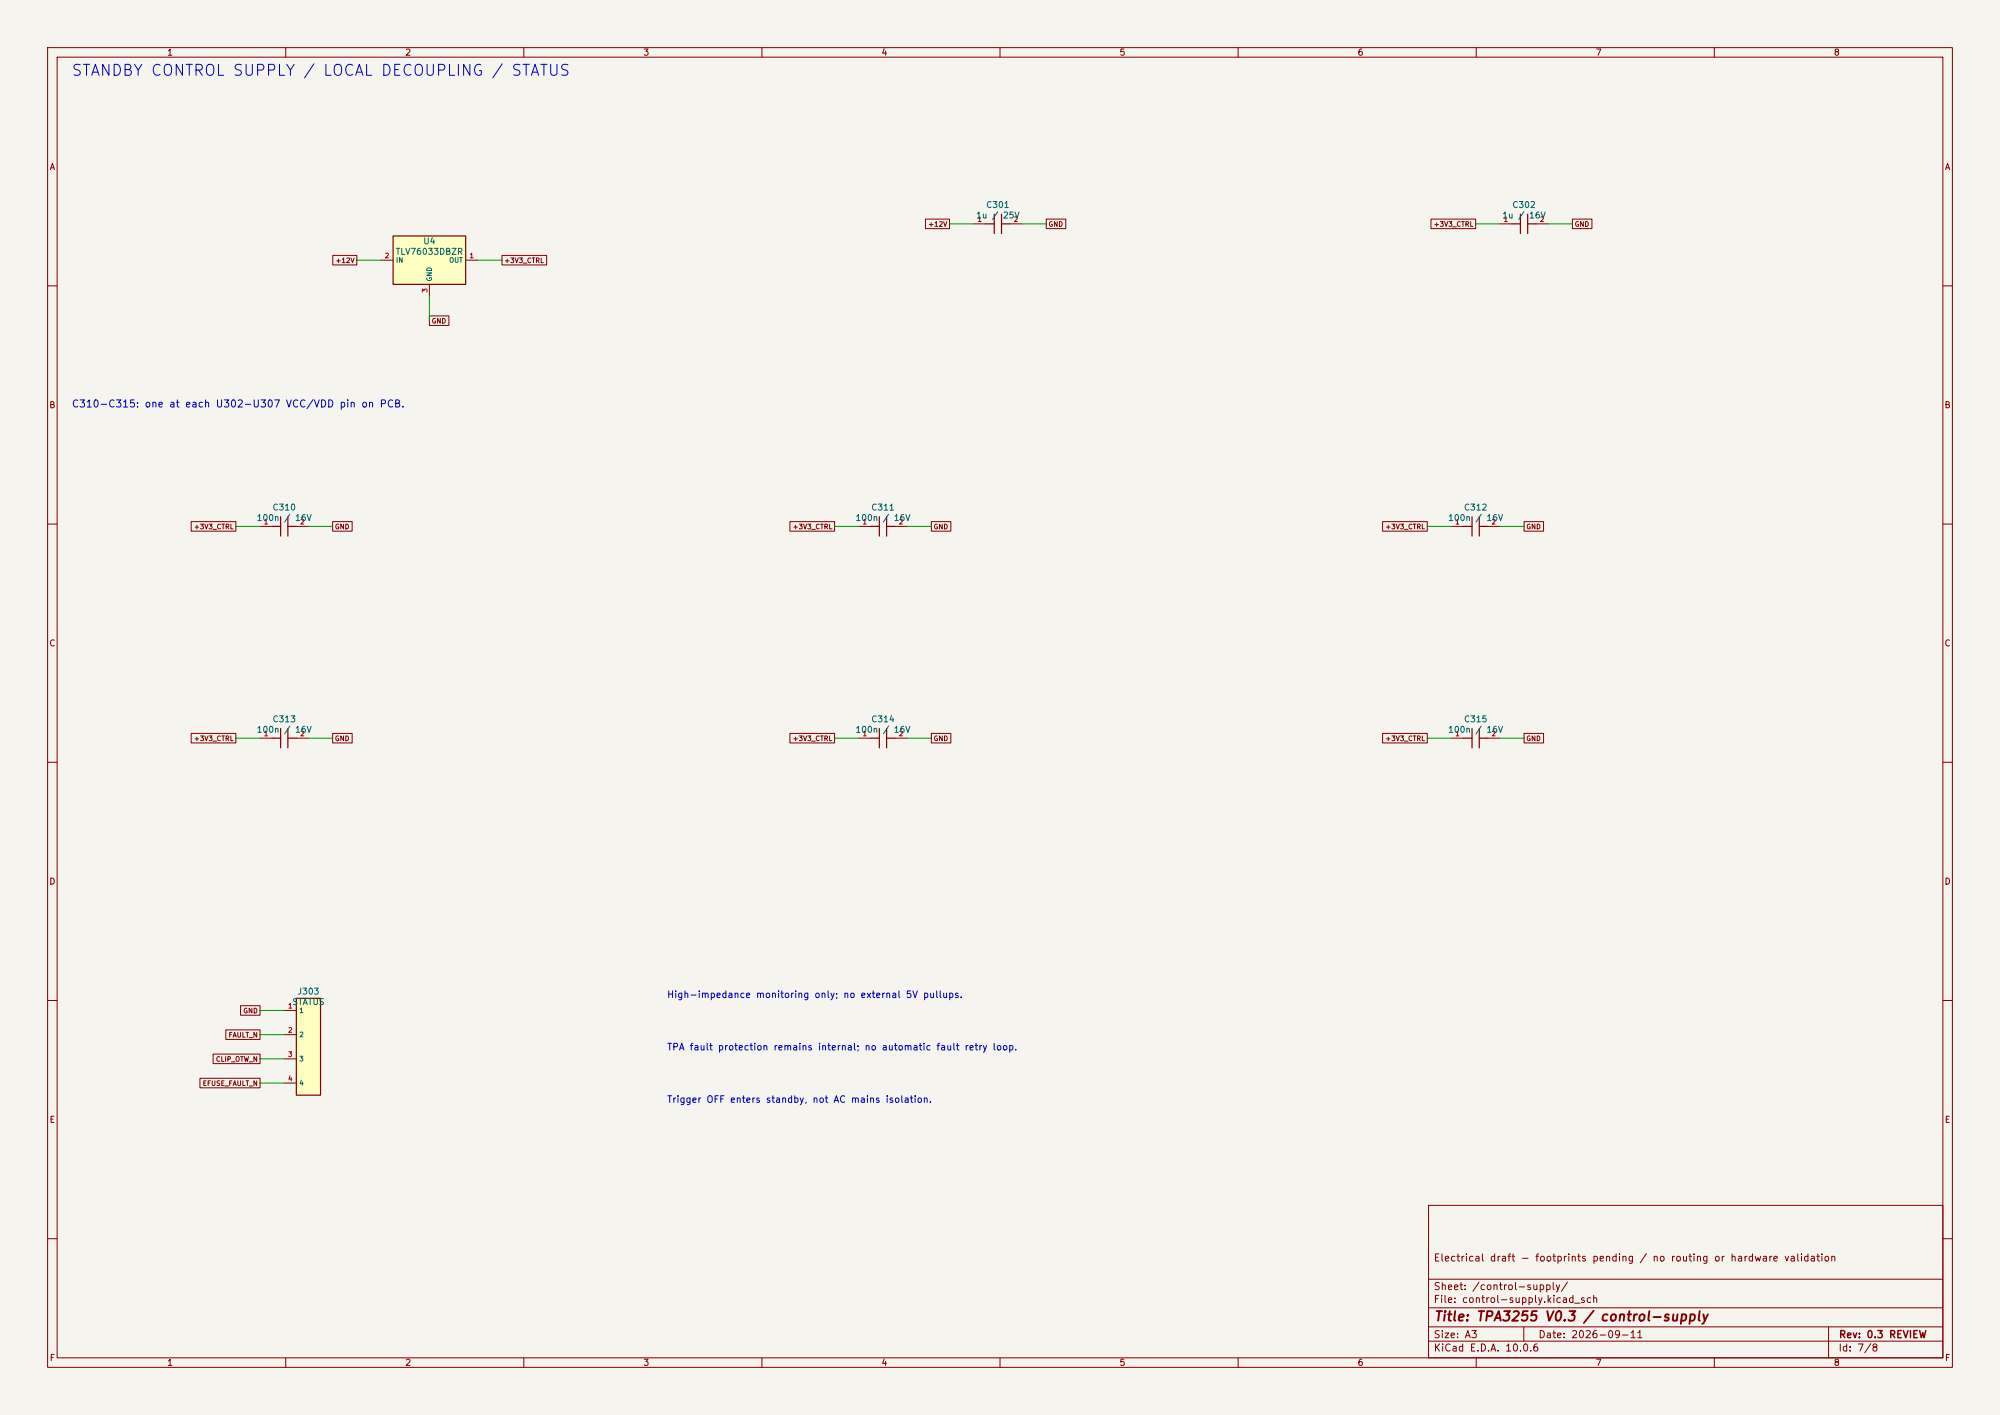
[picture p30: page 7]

STANDBY CONTROL SUPPLY / LOCAL DECOUPLING / STATUS

High-impedance monitoring only; no external 5V pullups.

Trigger OFF enters standby, not AC mains isolation. TPA fault protection remains internal; no automatic fault retry loop.

Electrical draft - footprints pending / no routing or hardware validation

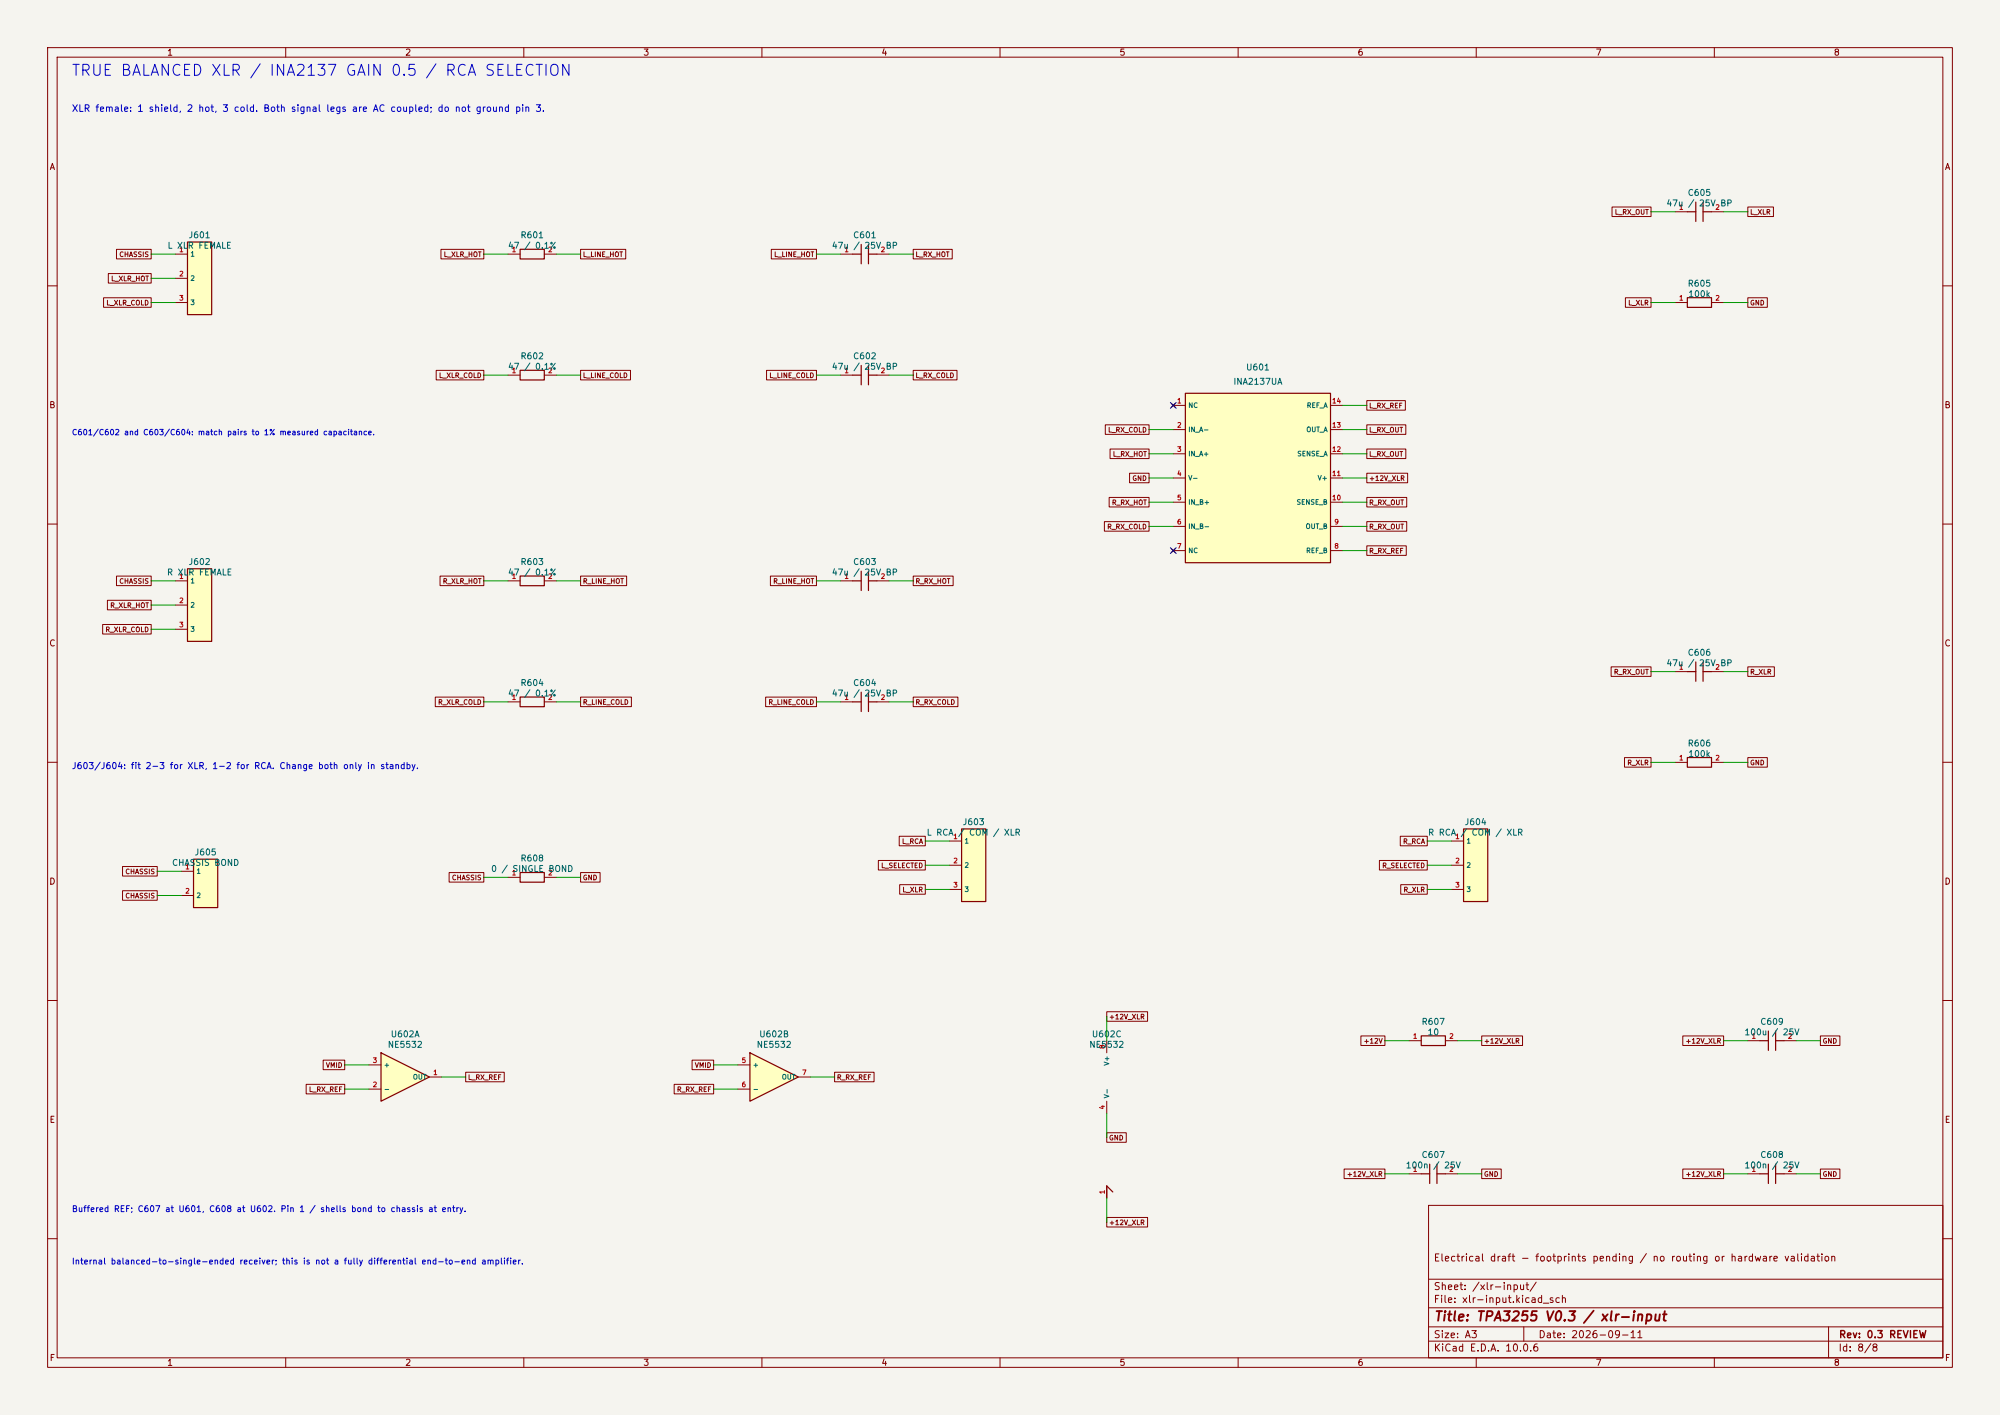
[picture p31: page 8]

TRUE BALANCED XLR / INA2137 GAIN 0.5 / RCA SELECTION

C601/C602 and C603/C604: match pairs to 1% measured capacitance. XLR female: 1 shield, 2 hot, 3 cold. Both signal legs are AC coupled; do not ground pin 3.

J603/J604: fit 2-3 for XLR, 1-2 for RCA. Change both only in standby.

Buffered REF; C607 at U601, C608 at U602. Pin 1 / shells bond to chassis at entry.

Electrical draft - footprints pending / no routing or hardware validation

Internal balanced-to-single-ended receiver; this is not a fully differential end-to-end amplifier.


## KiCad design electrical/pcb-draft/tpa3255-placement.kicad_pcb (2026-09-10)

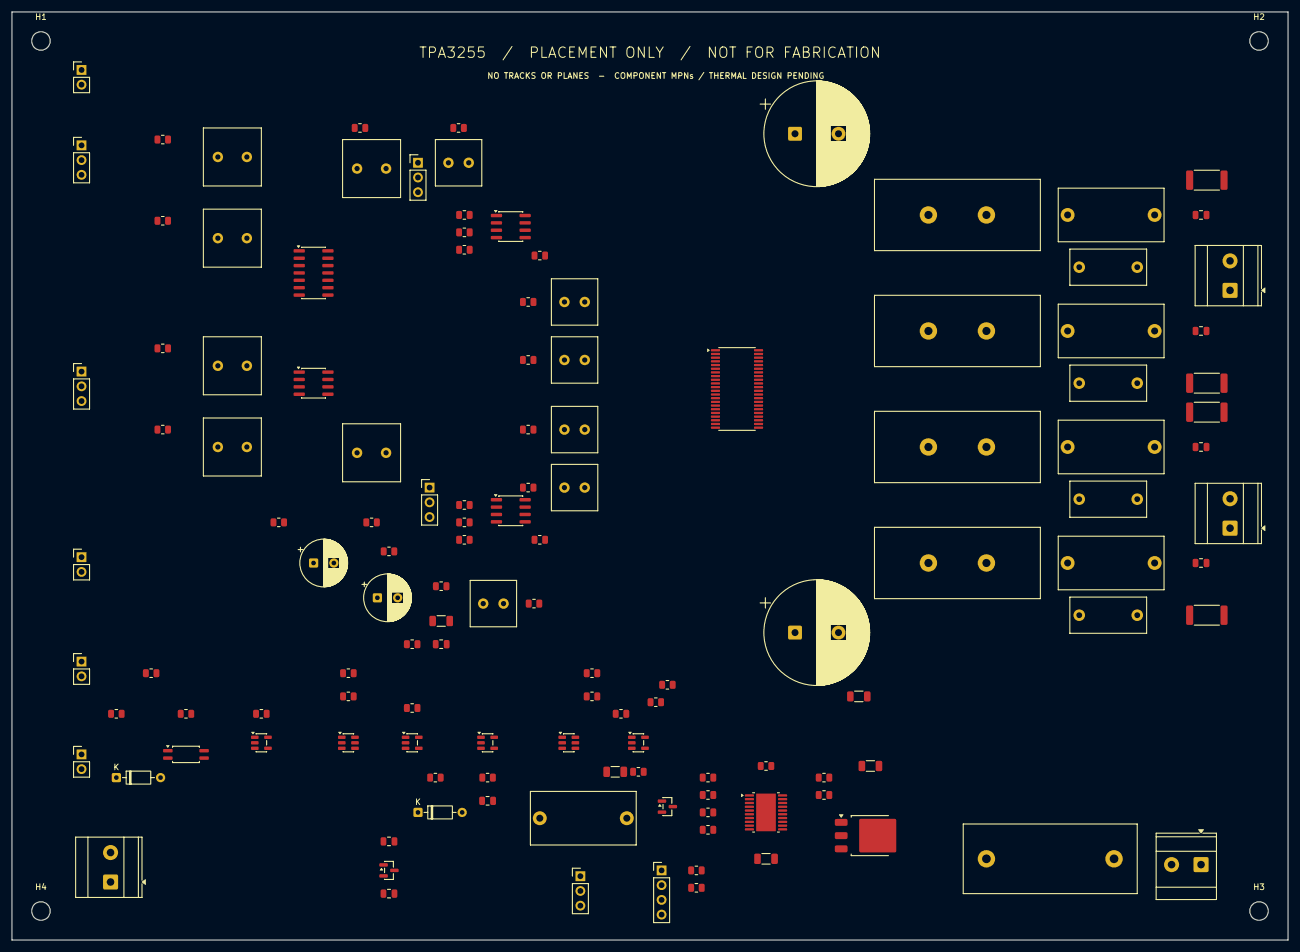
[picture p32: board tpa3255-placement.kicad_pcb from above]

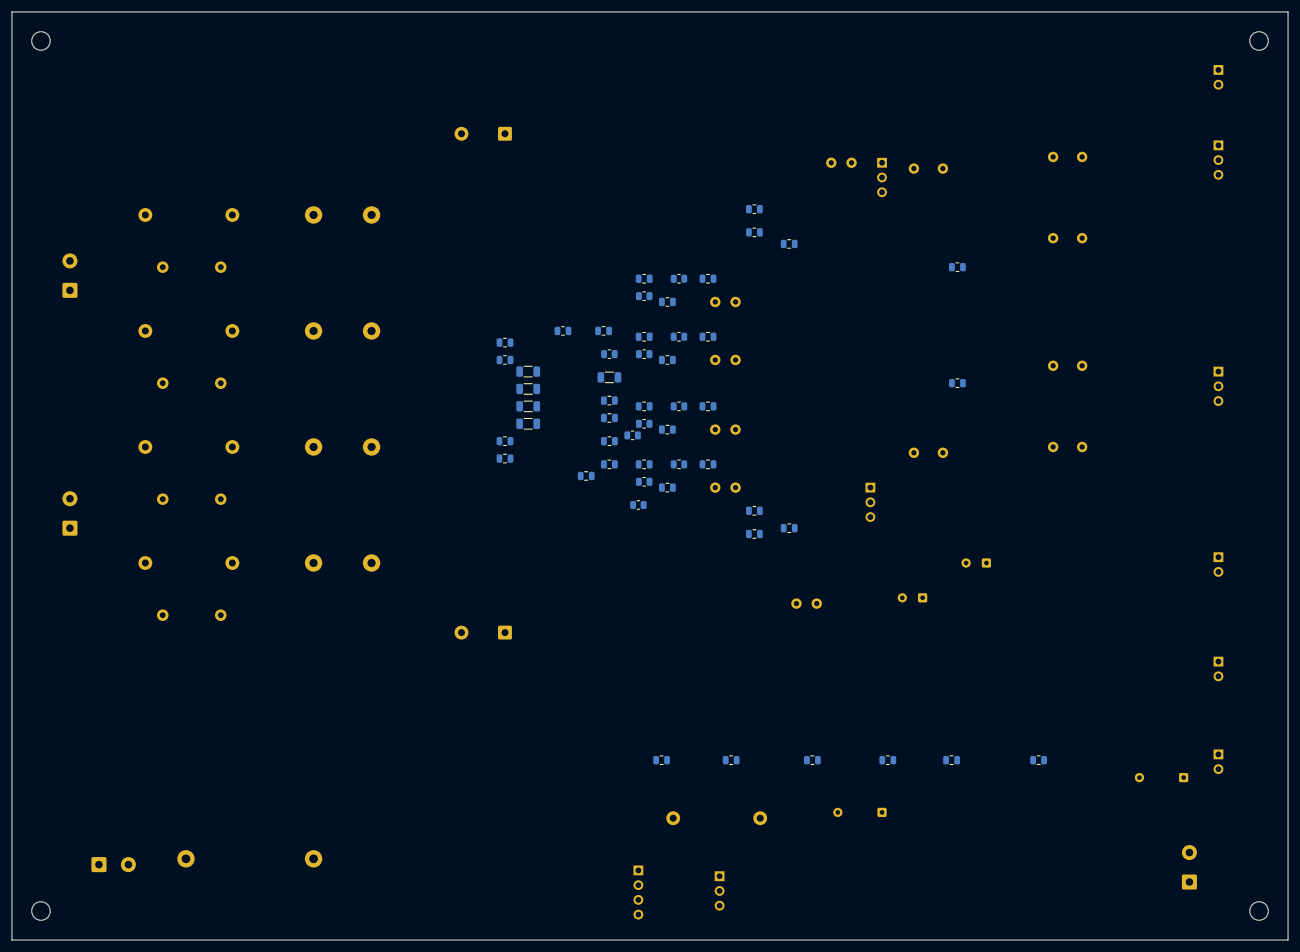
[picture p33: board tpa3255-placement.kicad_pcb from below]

Board: 4 copper layers, 220.0 x 160.0 mm, 184 parts (53 on the bottom side), 105 nets, no tracks yet.

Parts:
C1, C2, C3, C4: 33n / 100V; C_0805_2012Metric
C5, C6, C7, C8: 1u / 100V film; C_Rect_L18.0mm_W9.0mm_P15.00mm_FKS3_FKP3
C9, C10, C11, C12: 1n / 100V; C_0805_2012Metric
C13, C14, C15, C16: 220n / 100V film; C_Rect_L13.0mm_W6.0mm_P10.00mm_FKS3_FKP3_MKS4
C101, C121: 10u / 25V BP; BP_Cap_D8_P3.5
C102, C103, C122, C123: 330p / C0G; C_0805_2012Metric
C150, C151, C152, C153: 10u / 50V BP; BP_Cap_D8_P3.5
C154, C155, C156, C157: 100p / C0G; C_0805_2012Metric
C201, C202, C203, C204, C401: 1u / 100V X7R; C_1206_3216Metric
C205, C206: 470u / 80V; CP_Radial_D18.0mm_P7.50mm
C207: 10u / 25V; C_1206_3216Metric
C208, C209, C210, C218, C219, C607, C608: 100n / 25V; C_0805_2012Metric
C211, C212, C213, C302: 1u / 16V; C_0805_2012Metric
C214: 47n / 25V; C_0805_2012Metric
C215, C609: 100u / 25V; CP_Radial_D8.0mm_P3.50mm
C216: 10u / 16V; C_1206_3216Metric
C217, C310, C311, C312, C313, C314, C315: 100n / 16V; C_0805_2012Metric
C301: 1u / 25V; C_0805_2012Metric
C303: 1n / C0G; C_0805_2012Metric
C304: 4.7u / 16V film 5%; C_Rect_L18.0mm_W9.0mm_P15.00mm_FKS3_FKP3
C305: 180n / 5% C0G; C_1206_3216Metric
C402: 2.2u / 10V X7R; C_1206_3216Metric
C501, C502, C503, C504, C505, C506, C507, C508: 220p / 100V C0G; C_0805_2012Metric
C601, C602, C603, C604, C605, C606: 47u / 25V BP; BP_Cap_D10_P5
D301, D302: 1N4148; DO35_A1_K2_P7.62
D303: BAT54; SOT-23
D401: STPS5H100B; TO-252-3_TabPin2
F1: T5A / >=80VDC TBD MPN; Fuse_P22_Provisional
H1, H2, H3, H4: MountingHole_3.2mm_M3
J1: LEFT BTL; TerminalBlock_Phoenix_MKDS-3-2-5.08_1x02_P5.08mm_Horizontal
J2: RIGHT BTL; TerminalBlock_Phoenix_MKDS-3-2-5.08_1x02_P5.08mm_Horizontal
J101: L RCA; PinHeader_1x02_P2.54mm_Vertical
J102: R RCA; PinHeader_1x02_P2.54mm_Vertical
J201: INTERNAL 48V INPUT; TerminalBlock_Phoenix_MKDS-3-2-5.08_1x02_P5.08mm_Horizontal
J202: INTERNAL 12V INPUT; TerminalBlock_Phoenix_MKDS-3-2-5.08_1x02_P5.08mm_Horizontal
J301: TRIGGER TIP / SLEEVE; PinHeader_1x02_P2.54mm_Vertical
J302: AUTO / COMMON / ON; PinHeader_1x03_P2.54mm_Vertical
J303: STATUS; PinHeader_1x04_P2.54mm_Vertical
J601: L XLR FEMALE; PinHeader_1x03_P2.54mm_Vertical
J602: R XLR FEMALE; PinHeader_1x03_P2.54mm_Vertical
J603: L RCA / COM / XLR; PinHeader_1x03_P2.54mm_Vertical
J604: R RCA / COM / XLR; PinHeader_1x03_P2.54mm_Vertical
J605: CHASSIS BOND; PinHeader_1x02_P2.54mm_Vertical
L1, L2, L3, L4: 10u / MA5172-AE; MA5172_AE_Provisional
R1, R2, R3, R4: 1 / 1W; R_2512_6332Metric
R101, R121, R305, R605, R606: 100k; R_0805_2012Metric
R102, R122: 11.5k / 0.1%; R_0805_2012Metric
R103, R104, R105, R123, R124, R125, R307, R312, R402, R404, R406, R505, R506, R507, R508: 10k / 0.1%; R_0805_2012Metric
R150, R151, R152, R153: 2.7k / 0.1%; R_0805_2012Metric
R201: 3.3; R_0805_2012Metric
R202, R304: 22k / 1%; R_0805_2012Metric
R203: 30k / 1%; R_0805_2012Metric
R204, R607: 10; R_0805_2012Metric
R205, R206: 10k / 1%; R_0805_2012Metric
R301: 1k / 1%; R_0805_2012Metric
R302: 4.7k / 1%; R_0805_2012Metric
R303: 6.8k / 1%; R_0805_2012Metric
R306: 267k / 0.1%; R_0805_2012Metric
R308, R313, R314: 10k; R_0805_2012Metric
R309, R408: 1k; R_0805_2012Metric
R310: 100k / 1%; R_0805_2012Metric
R311: 1M / 0.1%; R_0805_2012Metric
R401: 324k / 0.1%; R_0805_2012Metric
R403: 412k / 0.1%; R_0805_2012Metric
R405: 316k / 0.1%; R_0805_2012Metric
R407: 4.02k / 1%; R_0805_2012Metric
R409: 22k; R_0805_2012Metric
R410: 22k / 0.5W; R_1206_3216Metric
R501, R502, R503, R504: 33k / 0.1%; R_0805_2012Metric
R601, R602, R603, R604: 47 / 0.1%; R_0805_2012Metric
R608: 0 / SINGLE BOND; R_0805_2012Metric
U1: TPA3255DDV; HTSSOP-44_6.1x14mm_P0.635mm_TopEP4.14x7.01mm
U2, U3, U602: NE5532; SOIC-8_3.9x4.9mm_P1.27mm
U4: TLV76033DBZR; SOT-23
U301: VOS618A-3T; SSOP-4_4.4x2.6mm_P1.27mm
U302: SN74LVC1G14DBVR; SOT-23-5
U303, U306: TPS3808G01DBVR; SOT-23-6
U304, U305, U307: SN74LVC1G17DBVR; SOT-23-5
U401: TPS26631PWPR; HTSSOP-20-1EP_4.4x6.5mm_P0.65mm_EP3.4x6.5mm_Mask2.96x2.96mm
U601: INA2137UA; SOIC-14_3.9x8.7mm_P1.27mm

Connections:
+3V3_CTRL: C302.1, C310.1, C311.1, C312.1, C313.1, C314.1, C315.1, J302.3, R304.1, R308.1, R313.1, R314.1, U4.1 (OUT), U302.5 (VCC), U303.6 (VDD), U304.5 (VCC), U305.5 (VCC), U306.6 (VDD), U307.5 (VCC)
+12V: C209.1, C210.1, C301.1, J202.1, R201.1, R204.1, R306.1, R607.1, U1.1 (GVDD_AB), U1.22 (GVDD_CD), U4.2 (IN)
+12V_AUDIO: C215.1, C218.1, C219.1, R204.2, R205.1, U2.8 (V+), U3.8 (V+)
+12V_XLR: C607.1, C608.1, C609.1, R607.2, U601.11 (V+), U602.8 (V+)
AUDIO_DELAY: C305.1, U306.4 (CT)
AUDIO_GOOD: R314.2, U306.1 (RESET_N), U307.2 (A)
AUDIO_MR: D303.1 (A), R313.2, U306.3 (MR_N), U401.17 (PGOOD)
AUTO_REQUEST: J302.1, U302.4 (Y)
AUX_BUFFER: R309.1, U304.4 (Y)
AUX_GOOD: D303.3 (K), R308.2, U303.1 (RESET_N), U304.2 (A)
AVDD: C212.1, U1.14 (AVDD)
BST_A: C1.1, U1.44 (BST_A)
BST_B: C2.1, U1.43 (BST_B)
BST_C: C3.1, U1.24 (BST_C)
BST_D: C4.1, U1.23 (BST_D)
CHASSIS: J601.1, J602.1, J605.1, J605.2, R608.1
CLIP_OTW_N: J303.3, U1.21 (CLIP_OTW_N)
C_START: C214.1, U1.15 (C_START)
DC_PROTECTED: C401.1, D401.2 (K_TAB), R401.1, R403.1, U401.1 (IN), U401.2 (IN), U401.3 (IN), U401.6 (IN_SYS)
DVDD: C211.1, U1.11 (DVDD)
EFUSE_DVDT: C402.1, U401.10 (dVdT)
EFUSE_ENABLE: R408.1, U305.4 (Y)
EFUSE_FAULT_N: J303.4, U401.15 (FLT_N)
EFUSE_ILIM: R407.1, U401.11 (ILIM)
EFUSE_OV: R403.2, R404.1, U401.8 (OVP)
EFUSE_PGTH: R405.2, R406.1, U401.16 (PGTH)
EFUSE_SHDN: R408.2, R409.1, U401.13 (SHDN)
EFUSE_UV: R401.2, R402.1, U401.7 (UVLO)
FAULT_N: J303.2, U1.19 (FAULT_N)
FB_MID_A: C501.2, C505.1, R505.1
FB_MID_B: C502.2, C506.1, R506.1
FB_MID_C: C503.2, C507.1, R507.1
FB_MID_D: C504.2, C508.1, R508.1
FREQ_ADJ: R203.1, U1.8 (FREQ_ADJ)
FUSED_48V: D401.1 (A), F1.2
GND: C5.2, C6.2, C7.2, C8.2, C9.2, C10.2, C11.2, C12.2, C154.2, C155.2, C156.2, C157.2, C201.2, C202.2, C203.2, C204.2, C205.2, C206.2, C207.2, C208.2, C209.2, C210.2, C211.2, C212.2, C213.2, C214.2, C215.2, C216.2, C217.2, C218.2, C219.2, C301.2, C302.2, C303.2, C304.2, C305.2, C310.2, C311.2, C312.2, C313.2, C314.2, C315.2, C401.2, C402.2, C607.2, C608.2, C609.2, J101.2, J102.2, J201.2, J202.2, J303.1, R1.2, R2.2, R3.2, R4.2, R101.2, R121.2, R202.2, R203.2, R206.2, R302.2, R305.2, R307.2, R310.2, R312.2, R402.2, R404.2, R406.2, R407.2, R409.2, R410.2, R505.2, R506.2, R507.2, R508.2, R605.2, R606.2, R608.2, U1.3 (M1), U1.4 (M2), U1.12 (GND), U1.13 (GND), U1.25 (GND), U1.26 (GND), U1.33 (GND), U1.34 (GND), U1.41 (GND), U1.42 (GND), U2.4 (V-), U3.4 (V-), U4.3 (GND), U301.3 (E), U302.3 (GND), U303.2 (GND), U304.3 (GND), U305.3 (GND), U306.2 (GND), U307.3 (GND), U401.9 (GND), U401.21 (PAD), U601.4 (V-), U602.4 (V-)
HOLD_CAP: C304.1, D302.2 (K), R310.1, U305.2 (A)
HOLD_CHARGE: D302.1 (A), R309.2
INPUT_A: C150.2, C154.1, U1.5 (INPUT_A)
INPUT_B: C151.2, C155.1, U1.6 (INPUT_B)
INPUT_C: C152.2, C156.1, U1.16 (INPUT_C)
INPUT_D: C153.2, C157.1, U1.17 (INPUT_D)
L_LINE_COLD: C602.1, R602.2
L_LINE_HOT: C601.1, R601.2
L_NEG: C102.2, R103.2, R104.1, R150.1, U2.1 (OUT)
L_POS: C103.2, R105.2, R151.1, U2.7 (OUT)
L_RCA: J101.1, J603.1, R101.1
L_RX_COLD: C602.2, U601.2 (IN_A-)
L_RX_HOT: C601.2, U601.3 (IN_A+)
L_RX_OUT: C605.1, U601.12 (SENSE_A), U601.13 (OUT_A)
L_RX_REF: U601.14 (REF_A), U602.1 (OUT), U602.2 (-)
L_SELECTED: C101.1, J603.2
L_XLR: C605.2, J603.3, R605.1
L_XLR_COLD: J601.3, R602.1
L_XLR_HOT: J601.2, R601.1
unnamed: C101.2, R102.1
unnamed: C121.2, R122.1
unnamed: C102.1, R102.2, R103.1, U2.2 (-)
unnamed: C103.1, R104.2, R105.1, U2.6 (-)
unnamed: C122.1, R122.2, R123.1, U3.2 (-)
unnamed: C123.1, R124.2, R125.1, U3.6 (-)
OC_ADJ: R202.1, U1.7 (OC_ADJ)
OUT_A: C1.2, L1.1, U1.39 (OUT_A), U1.40 (OUT_A)
OUT_B: C2.2, L2.1, U1.35 (OUT_B)
OUT_C: C3.2, L3.1, U1.32 (OUT_C)
OUT_D: C4.2, L4.1, U1.27 (OUT_D), U1.28 (OUT_D)
PVDD: C201.1, C202.1, C203.1, C204.1, C205.1, C206.1, R311.1, R405.1, R410.1, U1.29 (PVDD_CD), U1.30 (PVDD_CD), U1.31 (PVDD_CD), U1.36 (PVDD_AB), U1.37 (PVDD_AB), U1.38 (PVDD_AB), U401.18 (OUT), U401.19 (OUT), U401.20 (OUT)
PVDD_IN: F1.1, J201.1
RESET_DRIVE: R301.1, U307.4 (Y)
RESET_N: R301.2, R302.1, U1.18 (RESET_N)
RUN_REQUEST: J302.2, R305.1, U303.3 (MR_N)
R_LINE_COLD: C604.1, R604.2
R_LINE_HOT: C603.1, R603.2
R_NEG: C122.2, R123.2, R124.1, R152.1, U3.1 (OUT)
R_POS: C123.2, R125.2, R153.1, U3.7 (OUT)
R_RCA: J102.1, J604.1, R121.1
R_RX_COLD: C604.2, U601.6 (IN_B-)
R_RX_HOT: C603.2, U601.5 (IN_B+)
R_RX_OUT: C606.1, U601.9 (OUT_B), U601.10 (SENSE_B)
R_RX_REF: U601.8 (REF_B), U602.6 (-), U602.7 (OUT)
R_SELECTED: C121.1, J604.2
R_XLR: C606.2, J604.3, R606.1
R_XLR_COLD: J602.3, R604.1
R_XLR_HOT: J602.2, R603.1
SENSE_12V: C303.1, R306.2, R307.1, U303.5 (SENSE)
SENSE_PVDD: R311.2, R312.1, U306.5 (SENSE)
SPK_A: C5.1, C9.1, C13.1, C505.2, J1.1, L1.2, R501.2
SPK_B: C6.1, C10.1, C14.1, C506.2, J1.2, L2.2, R502.2
SPK_C: C7.1, C11.1, C15.1, C507.2, J2.1, L3.2, R503.2
SPK_D: C8.1, C12.1, C16.1, C508.2, J2.2, L4.2, R504.2
SUM_A: C150.1, C501.1, R150.2, R501.1
SUM_B: C151.1, C502.1, R151.2, R502.1
SUM_C: C152.1, C503.1, R152.2, R503.1
SUM_D: C153.1, C504.1, R153.2, R504.1
TRIG_LED: D301.2 (K), R303.2, U301.1 (A)
TRIG_N: R304.2, U301.4 (C), U302.2 (A)
TRIG_RETURN: D301.1 (A), J301.2, U301.2 (K)
TRIG_TIP: J301.1, R303.1
VBG: C213.1, U1.20 (VBG)
VDD_FILTERED: C207.1, C208.1, R201.2, U1.2 (VDD)
VMID: C216.1, C217.1, R205.2, R206.1, U2.3 (+), U2.5 (+), U3.3 (+), U3.5 (+), U602.3 (+), U602.5 (+)
Z_A: C13.2, R1.1
Z_B: C14.2, R2.1
Z_C: C15.2, R3.1
Z_D: C16.2, R4.1

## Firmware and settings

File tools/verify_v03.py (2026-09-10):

"""Audit the V0.3 netlist; run reduced AC and functional power-sequence models.

No TPA3255 PWM, opamp distortion, semiconductor transient or EMI model is claimed.
"""
import csv
import json
import math
from pathlib import Path
import subprocess
import tempfile
import xml.etree.ElementTree as ET

ROOT=Path(__file__).resolve().parents[1]
EL=ROOT/'electrical/v03'
SIM=ROOT/'simulation/v03'


def run(*args,cwd=ROOT):
    result=subprocess.run(args,cwd=cwd,text=True,capture_output=True)
    if result.returncode: raise RuntimeError(result.stdout+result.stderr)
    return result.stdout


def write_csv(path,header,rows):
    with path.open('w',newline='') as f:
        w=csv.writer(f,lineterminator='\n');w.writerow(header);w.writerows(rows)


def interpolate(data,f):
    for a,b in zip(data,data[1:]):
        if a[0]<=f<=b[0]:
            t=math.log(f/a[0])/math.log(b[0]/a[0])
            z=[x*(1-t)+y*t for x,y in zip(a[1:],b[1:])]
            return [complex(*z[i:i+2]) for i in range(0,len(z),2)]
    raise ValueError(f)


def main():
    SIM.mkdir(parents=True,exist_ok=True)
    sch=str(EL/'tpa3255-v03.kicad_sch')
    with tempfile.TemporaryDirectory(prefix='tpa-v03-') as td:
        tmp=Path(td)
        run('kicad-cli','sch','erc','--format','json','--exit-code-violations','-o',str(tmp/'erc.json'),sch)
        erc=json.loads((tmp/'erc.json').read_text())
        assert not any(sheet['violations'] for sheet in erc['sheets'])
        run('kicad-cli','sch','export','netlist','--format','kicadxml','-o',str(tmp/'net.xml'),sch)
        root=ET.parse(tmp/'net.xml').getroot()
        actual={}
        groups={}
        for net in root.findall('./nets/net'):
            name=net.attrib['name'];groups[name]=set()
            for node in net.findall('node'):
                key=(node.attrib['ref'],node.attrib['pin'])
                assert key not in actual
                actual[key]=name;groups[name].add(key)
        expected={}
        with (EL/'expected-connections.csv').open() as f:
            for row in csv.DictReader(f):
                node=(row['reference'],row['pin'])
                name=row['net'] if row['net']!='NC' else 'NC:'+':'.join(node)
                expected.setdefault(name,set()).add(node)
        assert set(actual)==set().union(*expected.values())
        assert {frozenset(v) for v in groups.values()}=={frozenset(v) for v in expected.values()}
        net=lambda ref,pin:actual[(ref,str(pin))]
        def pins(ref,mapping):
            for pin,name in mapping.items(): assert net(ref,pin)==name,(ref,pin,name)
        # Critical checks use physical pin numbers independently of the drawing generator.
        pins('U1',{1:'+12V',2:'VDD_FILTERED',3:'GND',4:'GND',5:'INPUT_A',6:'INPUT_B',
                   11:'DVDD',14:'AVDD',16:'INPUT_C',17:'INPUT_D',18:'RESET_N',20:'VBG',22:'+12V'})
        for n in [29,30,31,36,37,38]:pins('U1',{n:'PVDD'})
        for n in [12,13,25,26,33,34,41,42]:pins('U1',{n:'GND'})
        pins('U1',{39:'OUT_A',40:'OUT_A',27:'OUT_D',28:'OUT_D'})
        for i,(bst,out) in enumerate([(44,40),(43,35),(24,32),(23,28)],1):
            assert net('C'+str(i),1)==net('U1',bst)
            assert net('C'+str(i),2)==net('U1',out)
        for name,cap in [('DVDD','C211'),('AVDD','C212'),('VBG','C213')]:
            assert len(groups[name])==2 and (cap,'1') in groups[name]
        for i,ch in enumerate('ABCD'):
            arm=('L_NEG','L_POS','R_NEG','R_POS')[i]
            pins('R'+str(150+i),{1:arm,2:'SUM_'+ch})
            pins('C'+str(150+i),{1:'SUM_'+ch,2:'INPUT_'+ch})
            pins('R'+str(501+i),{1:'SUM_'+ch,2:'SPK_'+ch})
            pins('C'+str(501+i),{1:'SUM_'+ch,2:'FB_MID_'+ch})
            pins('C'+str(505+i),{1:'FB_MID_'+ch,2:'SPK_'+ch})
            pins('R'+str(505+i),{1:'FB_MID_'+ch,2:'GND'})
        assert groups['TRIG_RETURN']=={('J301','2'),('D301','1'),('U301','2')}
        pins('U301',{1:'TRIG_LED',2:'TRIG_RETURN',3:'GND',4:'TRIG_N'})
        pins('D301',{1:'TRIG_RETURN',2:'TRIG_LED'})
        pins('U303',{1:'AUX_GOOD',2:'GND',3:'RUN_REQUEST',5:'SENSE_12V',6:'+3V3_CTRL'})
        pins('D302',{1:'HOLD_CHARGE',2:'HOLD_CAP'})
        # BAT54 SOT-23: physical pin 2 is NC; cathode is pin 3.
        pins('D303',{1:'AUDIO_MR',3:'AUX_GOOD'})
        assert len(groups[net('D303',2)])==1
        pins('U306',{1:'AUDIO_GOOD',2:'GND',3:'AUDIO_MR',4:'AUDIO_DELAY',5:'SENSE_PVDD',6:'+3V3_CTRL'})
        pins('U401',{1:'DC_PROTECTED',2:'DC_PROTECTED',3:'DC_PROTECTED',6:'DC_PROTECTED',
                     7:'EFUSE_UV',8:'EFUSE_OV',9:'GND',10:'EFUSE_DVDT',11:'EFUSE_ILIM',
                     13:'EFUSE_SHDN',16:'EFUSE_PGTH',17:'AUDIO_MR',18:'PVDD',19:'PVDD',20:'PVDD',21:'GND'})
        pins('D401',{1:'FUSED_48V',2:'DC_PROTECTED'})
        pins('U601',{2:'L_RX_COLD',3:'L_RX_HOT',4:'GND',5:'R_RX_HOT',6:'R_RX_COLD',
                     8:'R_RX_REF',9:'R_RX_OUT',10:'R_RX_OUT',11:'+12V_XLR',12:'L_RX_OUT',13:'L_RX_OUT',14:'L_RX_REF'})
        pins('U602',{1:'L_RX_REF',2:'L_RX_REF',3:'VMID',4:'GND',5:'VMID',6:'R_RX_REF',7:'R_RX_REF',8:'+12V_XLR'})
        for idx,ch in enumerate(('L','R')):
            pins('J'+str(601+idx),{1:'CHASSIS',2:ch+'_XLR_HOT',3:ch+'_XLR_COLD'})
            pins('J'+str(603+idx),{1:ch+'_RCA',2:ch+'_SELECTED',3:ch+'_XLR'})
            pins('C'+str(101+20*idx),{1:ch+'_SELECTED'})
            assert net('C'+str(101+20*idx),2)==net('R'+str(102+20*idx),1)
            for offset,leg in enumerate(('HOT','COLD')):
                pins('R'+str(601+2*idx+offset),{1:ch+'_XLR_'+leg,2:ch+'_LINE_'+leg})
                pins('C'+str(601+2*idx+offset),{1:ch+'_LINE_'+leg,2:ch+'_RX_'+leg})
            pins('C'+str(605+idx),{1:ch+'_RX_OUT',2:ch+'_XLR'})
        assert groups['CHASSIS']=={('J601','1'),('J602','1'),('J605','1'),('J605','2'),('R608','1')}
        pins('R608',{1:'CHASSIS',2:'GND'})
        for ref in ['U302','U304','U305','U307']:pins(ref,{3:'GND',5:'+3V3_CTRL'})
        pins('U302',{2:'TRIG_N',4:'AUTO_REQUEST'})
        pins('U304',{2:'AUX_GOOD',4:'AUX_BUFFER'})
        pins('U305',{2:'HOLD_CAP',4:'EFUSE_ENABLE'})
        pins('U307',{2:'AUDIO_GOOD',4:'RESET_DRIVE'})
        for ref,ps in [('U401',[4,5,12,14]),('U303',[4])]:
            for pin in ps: assert len(groups[net(ref,pin)])==1
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

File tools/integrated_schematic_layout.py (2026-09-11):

"""Re-layout native source symbols into one electrically integrated schematic.

Coordinates below use a 2.54 mm drawing grid. Main audio, PFFB and enable/reset
paths are wires; repeated supply/bias connections use ordinary same-sheet labels.
Only the overview's TPA3255/INA2137 pin positions are rearranged for signal flow.
Pin numbers, names, types, unit identities and all source component data survive.
"""
import collections
import copy
import csv
import hashlib
import json
import math
from uuid import NAMESPACE_URL, uuid5
from build_schematic_overview import (EL, NAME, OUTPUT, MANIFEST, UUID, SOURCE_NAMES,
    parse, dump, child, children, walk, q, number, annotation)

G = 2.54

def mm(v):
    return number(v * G)

def ident(key):
    return str(uuid5(NAMESPACE_URL, NAME + '/integrated/' + key))

class Drawing:
    def __init__(self):
        self.sources = {n: parse((EL/(n+'.kicad_sch')).read_text()) for n in SOURCE_NAMES}
        expected = {'tpa3255-v03'} | {json.loads(next(p[2] for p in children(s,'property') if p[1]=='"Sheetfile"'))[:-10] for s in children(self.sources['tpa3255-v03'], 'sheet')}
        assert expected == set(self.sources), 'Unmapped source sheet'
        self.lib, self.source, self.parts, self.pins = {}, {}, {}, {}
        self.items, self.lines, self.used, self.labels = [], [], set(), []
        self.nets = {(r['reference'],r['pin']):r['net'] for r in csv.DictReader((EL/'expected-connections.csv').open())}
        for n, net in [(1,'+12V'),(2,'GND'),(4,'+12V_AUDIO'),(5,'VDD_FILTERED'),(6,'DC_PROTECTED'),(7,'+12V_XLR')]:
            self.nets[('#FLG'+str(n),'1')] = net
        for t in self.sources.values():
            for s in children(child(t,'lib_symbols'),'symbol'):
                if s[1] in self.lib:
                    assert self.lib[s[1]] == s
                self.lib[s[1]] = copy.deepcopy(s)
            for s in children(t,'symbol'):
                ref = json.loads(next(p[2] for p in children(s,'property') if p[1]=='"Reference"'))
                key = (ref,int(child(s,'unit')[1]))
                assert key not in self.source
                self.source[key] = s
        self.reshape()

    def reshape(self):
        # The single TPA symbol remains one unit; pin placement follows four
        # signal lanes. No package pin is added, removed or renumbered.
        left = {5:57,6:87,16:125,17:155,1:66,2:69,7:98,8:101,
                11:104,14:107,15:110,20:113,3:116,4:119,9:134,10:137,
                18:140,19:143,21:146,22:149,12:160,13:163}
        right = {44:51,40:57,39:59,42:63,41:65,38:69,37:71,36:73,
                 43:81,35:87,34:93,33:95,32:125,31:103,30:105,29:107,
                 24:119,28:155,27:157,26:133,25:135,23:149}
        self.box('Project:TPA3255', (-28, -57, 28, 60),
                 {str(p):(-30,y-106,0) for p,y in left.items()} |
                 {str(p):(30,y-106,180) for p,y in right.items()})
        self.box('Project:INA2137', (-8,-40,8,48), {
            '1':(-10,-38,0),'2':(-10,-28,0),'3':(-10,-34,0),
            '4':(0,50,90),'5':(-10,34,0),'6':(-10,40,0),'7':(-10,44,0),
            '14':(10,-22,180),'13':(10,-34,180),'12':(10,-30,180),
            '11':(0,-42,270),'10':(10,38,180),'9':(10,34,180),'8':(10,46,180)})

    def box(self, name, bounds, pins):
        lib = self.lib[q(name)]
        unit = children(lib,'symbol')[0]
        oldpins = children(unit,'pin')
        assert set(pins) == {json.loads(child(p,'number')[1]) for p in oldpins}
        x1,y1,x2,y2=bounds
        unit[:] = [unit[0], unit[1], parse(f'(rectangle (start {mm(x1)} {mm(-y1)}) (end {mm(x2)} {mm(-y2)}) (stroke (width 0.254)(type default))(fill(type background)))')]
        for p in oldpins:
            n=json.loads(child(p,'number')[1]); x,y,a=pins[n]
            child(p,'at')[:] = ['at',mm(x),mm(-y),str(a)]
            child(p,'length')[1] = mm(2)
            unit.append(p)

    def place(self, ref, x, y, angle=0, unit=1, mirror=False):
        key=(ref,unit)
        assert key not in self.parts, key
        s=copy.deepcopy(self.source[key]); self.parts[key]=s
        child(s,'at')[:] = ['at',mm(x),mm(y),str(angle)]
        s[:] = [v for v in s if not(isinstance(v,list) and v[0]=='mirror')]
        if mirror: s.append(['mirror','y'])
        props={json.loads(p[1]):p for p in children(s,'property')}
        for p in props.values(): child(p,'at')[:] = ['at',mm(x),mm(y), '0']
        kind=json.loads(child(s,'lib_id')[1]).split(':')[1]
        # Keep readable horizontal properties even on rotated vertical passives.
        if kind in {'R','C','L','Diode','Fuse'} and angle in {90,270}:
            positions=[(x+1.6,y-0.5),(x+1.6,y+0.7)]
            justify='left'
        elif kind in {'R','C','L','Diode','Fuse'}:
            positions=[(x,y-2.0),(x,y-0.95)]; justify=''
        elif kind.startswith('Conn'):
            positions=[(x,y-4),(x,y-2.7)]; justify=''
        elif kind=='TPA3255':
            positions=[(x+15,106-54),(x+15,106-52.5)]; justify=''
        elif kind=='INA2137':
            positions=[(x,y-44),(x,y-42.8)]; justify=''
        else:
            positions=[(x,y-5.8),(x,y-4.6)]; justify=''
        if kind in {'TPS26631'}: positions=[(x,y-15),(x,y-13.7)]
        if kind in {'BAT54','PowerDiode'}: positions=[(x,y-7),(x,y-5.7)]
        for name,pos in zip(['Reference','Value'],positions):
            p=props[name]; child(p,'at')[:] = ['at',mm(pos[0]),mm(pos[1]),'0']
            # Only property styling changes; original text remains exact.
            p[4:] = []
            p[3] = ['at',mm(pos[0]),mm(pos[1]),'90' if angle in {90,270} else '0']
            p.append(parse('(effects (font (size 1.27 1.27))'+(' (justify left)' if justify else '')+')'))
        inst=child(s,'instances'); project=child(inst,'project'); path=child(project,'path')
        inst[:]=['instances',['project',q(NAME),['path',q('/'+UUID),copy.deepcopy(child(path,'reference')),copy.deepcopy(child(path,'unit'))]]]
        lib=self.lib[child(s,'lib_id')[1]]
        for sub in children(lib,'symbol'):
            u=int(json.loads(sub[1]).split('_')[-2])
            if u not in {0,unit}: continue
            for p in children(sub,'pin'):
                n=json.loads(child(p,'number')[1]); at=child(p,'at')
                px=float(at[1])/G; py=-float(at[2])/G
                direction=(int(at[3])+180)%360
                dx=math.cos(math.radians(direction)); dy=-math.sin(math.radians(direction))
                if mirror: px=-px; dx=-dx
                c=round(math.cos(math.radians(angle))); sn=round(math.sin(math.radians(angle)))
                px,py=c*px+sn*py,-sn*px+c*py
                dx,dy=c*dx+sn*dy,-sn*dx+c*dy
                self.pins[(ref,n)]=((round(x+px,6),round(y+py,6)),(round(dx),round(dy)))
        self.items.append(s)

    def pt(self, p):
        if isinstance(p[0],str):
            key=(p[0],str(p[1])); self.used.add(key); return self.pins[key][0]
        return tuple(p)
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

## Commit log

2026-09-10 將 TPA3255 後級與 V0.1 設計獨立為專案
    [enclosure-concept.scad]
2026-09-10 建立 TPA3255 V0.2 四頁原理圖、BOM 與區塊模擬
    [bom-draft.csv, expected-connections.csv, filter-ac.csv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]
2026-09-10 記錄 TPA3255 音質改善評估與下一版優先順序
2026-09-10 加入 V0.3 XLR 平衡輸入、PFFB 與 Trigger 電源控制草案
    [ac-common-8-pole0-mismatch.csv, ac-common-8-pole0.csv, ac-rca-4-pole0.csv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]
2026-09-10 記錄現成機箱加客製面板方案與尺寸候選
2026-09-10 Plan internal dual supplies with a single mains inlet
    [bom-draft.csv, dc-switch.kicad_sch, power-control.kicad_sch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]
2026-09-10 Start unrouted PCB placement and correct BAT54 package pin mapping
    [control-supply.kicad_sch, dc-switch.kicad_sch, expected-connections.csv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]
2026-09-11 Combine V0.3 schematics into a verified single-page review drawing
    [tpa3255-v03-overview.kicad_sch]
2026-09-11 Redraw the complete TPA3255 circuit with continuous signal paths
    [tpa3255-v03-overview.kicad_sch]
